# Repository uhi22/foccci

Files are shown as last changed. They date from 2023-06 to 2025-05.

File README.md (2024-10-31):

# foccci - The Fully Open CCS Charge Controller Interface

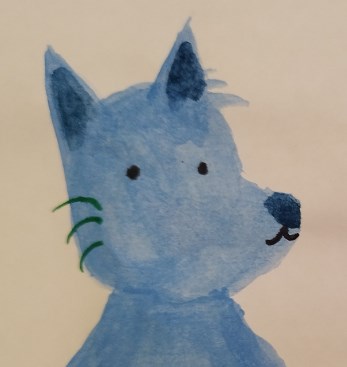
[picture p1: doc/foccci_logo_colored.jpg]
 Hi, I'm Foccci. Just call me [Foksi] or [Fok-See] or just Foxi :-)
My real name is "Fully Open CCS Charge Controller Interface", but that's just too difficult to remember.

What I am? I'm a Charge Controller that enables CCS charging of homebrew electric vehicles.
I was born in the OpenInverter forum community, https://openinverter.org/forum/viewtopic.php?t=3727, and I'm growing more and more due to the great people there.
Inside, I have a QCA7005 PLC modem and an STM32 microcontroller. I'm a piece of hardware, and because hardware alone is quite boring,
I'm in a team with Clara, https://github.com/uhi22/ccs32clara, which is dealing with the bits and bytes of our mission. And together, we can do a lot for you.

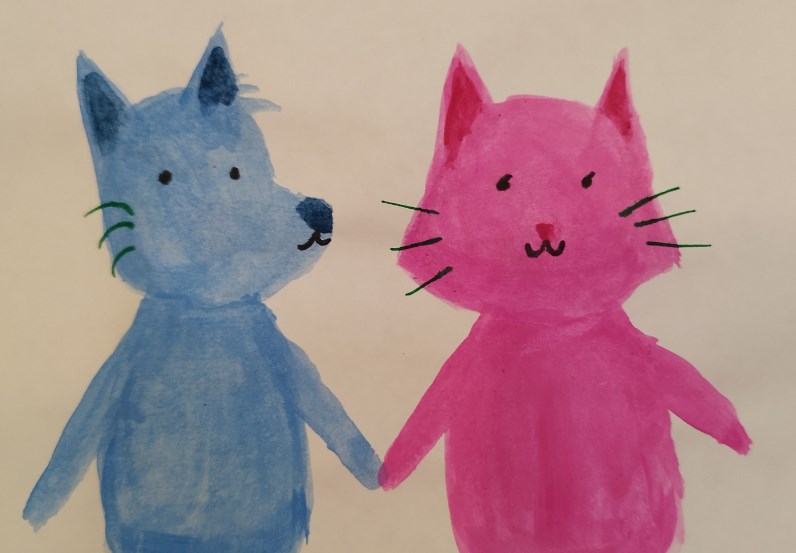
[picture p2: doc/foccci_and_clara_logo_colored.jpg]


# News

## 2024-06-27 Foccci Is Gaining Speed

While some folks are integrating Foccci in their vehicles and providing nice pictures for the galery (https://openinverter.org/forum/viewtopic.php?t=5077), we were proudly presenting the project at the
Augsburg Linux info day (https://openinverter.org/forum/viewtopic.php?t=4800). Sleep and wakeup,
new, fast contactor driver and a new connector pinout provide more flexibility for the car integration. That will
be the version 5, which will hopefully pop-up in the shop in July.

## 2023-12-13 Supercharging works. Halve a dozen boards are spread around the world. 

Johu is charging the Touran on the TESLA Supercharger using the hand-populated V3 board: https://openinverter.org/forum/viewtopic.php?p=64563#p64563 and https://www.youtube.com/watch?v=OKg3VUslol8
The first JLC populated boards have been completed manually, only one bug in the schematic needed a small workaround. Boards are on the way to several enthusiasts for further testing. The software is growing thanks to the great openinverter community.

## 2023-10-25 First Order of Populated Boards

Received four reservations on openinverter forum, and this was the trigger to create version v4.1 with minor layout
improvements, and to order a batch of five
at JLCPCB. Total cost for five: $127.32 including shipping, taxes and duties. The NCV8402 was out of stock,
and the QCA7005 is anyway not in their stock. So the material price is

- 25€ JLCPCB populated PCB
- 12€ QCA7005
- 4€ 2 x NCV8402
- 1€ RF transformator
- <1€ connectors for programming and serial line

## 2023-10-08 Light-Bulb-Demo-Charging on Alpitronic and ABB works

Using the foccci V3 board together with ccs32clara software, the muehlpower voltage sense board, a cheap chinese relay, the light-bulb-demo
worked on the first attempt on alpitronics hypercharger and on an ABB triple charger.

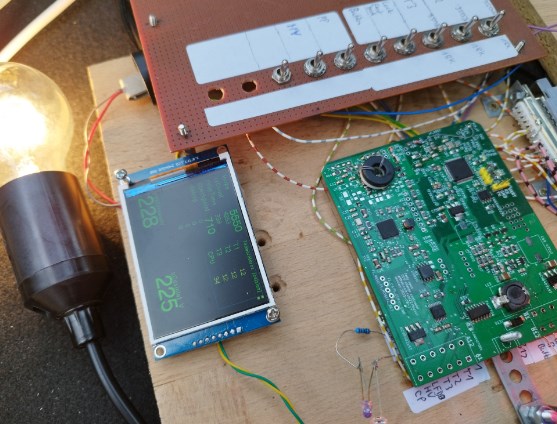
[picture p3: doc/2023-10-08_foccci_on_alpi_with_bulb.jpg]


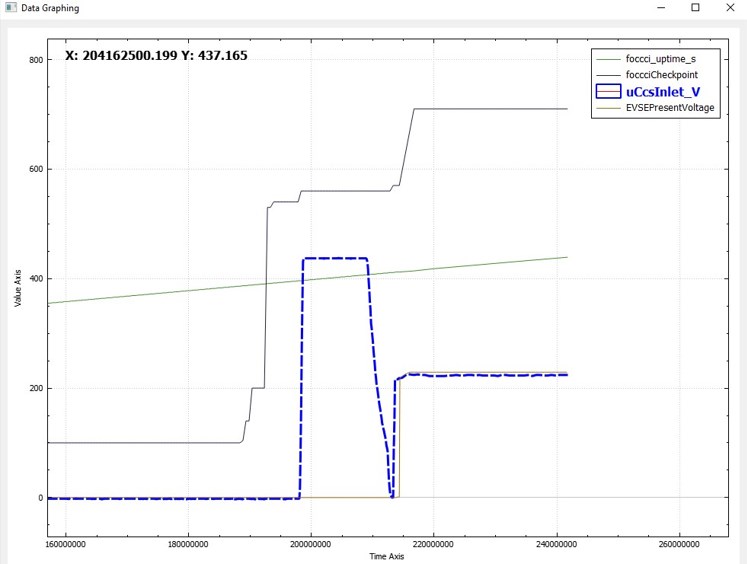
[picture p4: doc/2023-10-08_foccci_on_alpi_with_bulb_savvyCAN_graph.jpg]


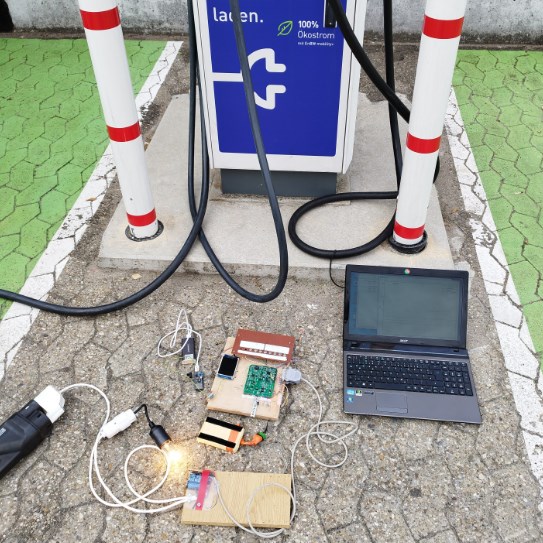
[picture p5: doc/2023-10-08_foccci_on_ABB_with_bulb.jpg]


## 2023-07-28 Charging Loop Reached

The foccci board version 2023-07-12 runs the STM32F103 and the QCA7005, and successfully enters
the charging loop, with simulated evse by pyPLC. It provides the checkpoint number and some other
informations via CAN with 500kBaud. On the other side of the CAN sits an ESP32 Wifi-Kit-32, with
a CAN transceiver added. It shows the data of the CAN on its OLED display.

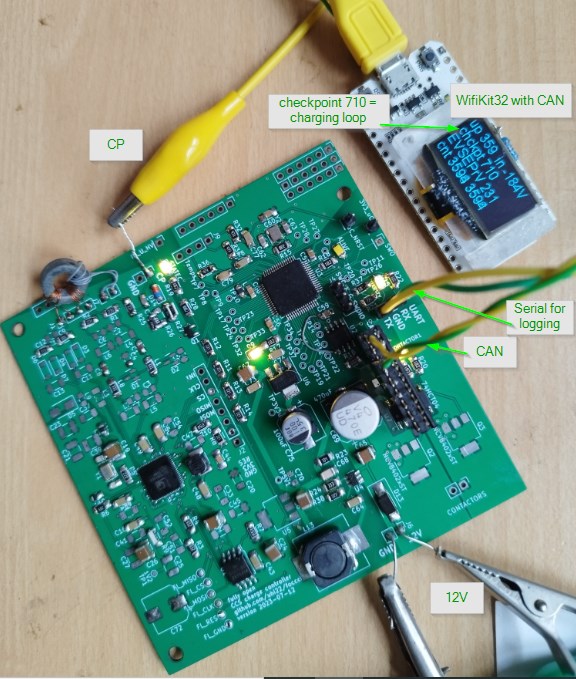
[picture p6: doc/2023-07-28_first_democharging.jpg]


## 2023-07-09 The board starts talking

After the PCBs and QCAs arrived, the soldering was the next challenge. It went well, and the board started talking to
the ESP32 running ccs32berta https://github.com/uhi22/ccs32berta

https://openinverter.org/forum/viewtopic.php?p=58627#p58627

## 2023-06-21 First PCB with the QCA7005

...is ready in KiCad and is sent to JLCPCB. It is a two-layer, and has so many capacitors, that they do not really fit
to the place where they would make sense. Caused by taking the schematic from the Millisman design, but changing
the size to 1206 for easy hand soldering. Btw: Below five dollars for five PCBs, including shipping, duties and taxes.

## 2023-06-14 The Idea Is Born

...and the discussion is starting on the OpenInverter forum
https://openinverter.org/forum/viewtopic.php?p=57643#p57643

# Board versions

## V1 June 2023

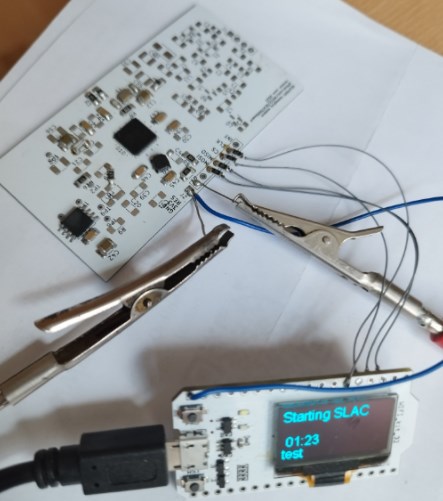
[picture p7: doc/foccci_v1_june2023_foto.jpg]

- Just the QCA7005, exposing the SPI interface.
- No controller, no voltage regulator, no CP logic.
- Test result summary: Light-bulb-demo-charging works on alpitronics, with ccs32berta running on ESP32. (https://github.com/uhi22/ccs32berta)

## V2 2023-07-12

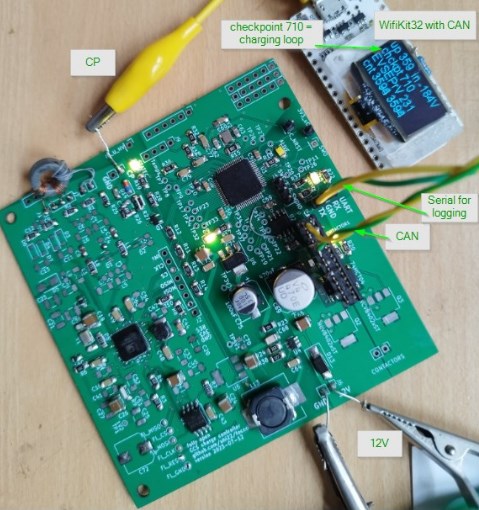
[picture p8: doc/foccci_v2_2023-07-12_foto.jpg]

- STM32 controller
- Power supply
- CAN transceiver
- CP logic
- Two contactor drivers
- Test result summary: Light-bulb-demo-charging works on alpitronics, with ccs32clara https://github.com/uhi22/ccs32clara running on the STM32.  https://openinverter.org/forum/viewtopic.php?p=59821#p59821

## V3 2023-08-17

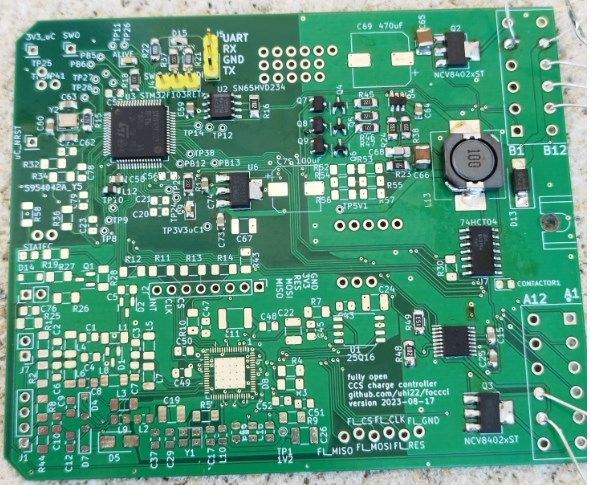
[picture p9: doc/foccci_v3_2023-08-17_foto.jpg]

- HBridge driver DRV8874 for connector lock
- discrete drivers for RGB LEDs
- Deutsch Connector 2x12pins
- added CP and PP sensing
- changed from 2 layers to 4 layers
- Test result summary: The new output drivers work with https://github.com/uhi22/ccs32clara. Other tests still in progress.
- Issues:
    - Diode to 3V3 is missing in the CP sense path (R58). Need to be patched.
    - There is a via near the pin1-corner of the QCA, which is very near to the metal frame at the corner, and may cause shortcut between 1V2 and ground.

## V4 2023-09-10

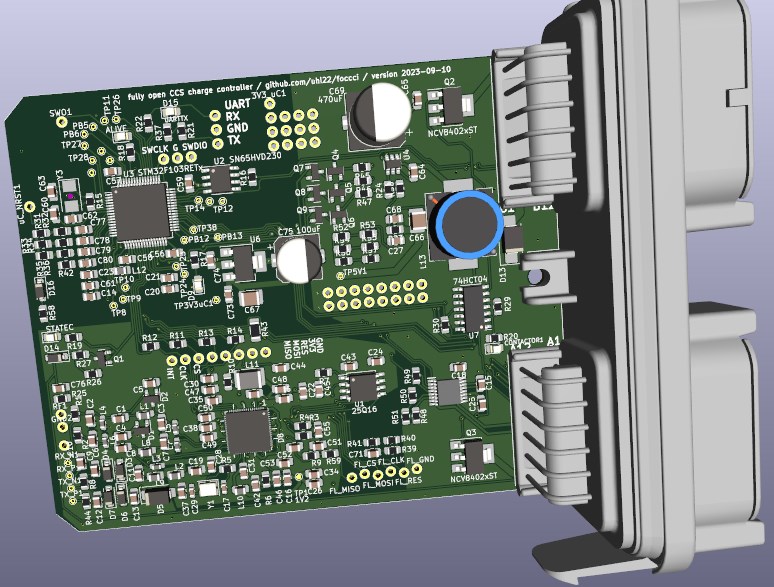
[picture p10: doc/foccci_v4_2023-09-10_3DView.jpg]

- Prepared for assembling by JLCPCB
- No 1206 size components anymore. Means: 0805 is the new default size now.
- Test result summary: PCBs not ordered yet. No testing done yet.
- Outdated, never produced.

## V4.1 2023-10-25

- functionally identical to V4
- moved via away from QCA corner to avoid solder bridge
- silk screen improvements: more component names and better readability
- Test result summary: one issue found (shortcut on the RX inputs to ground via inductors). After fixing this, everything works fine.

## V4.2 2024-02-06

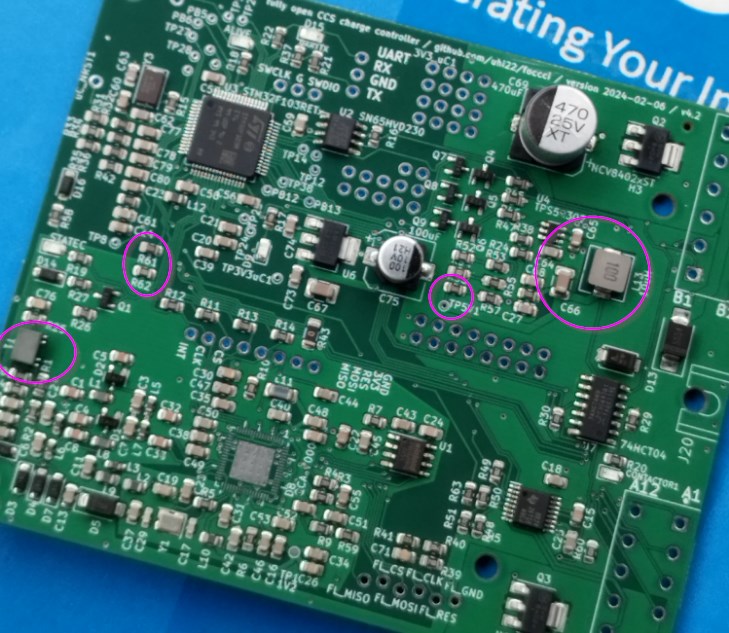
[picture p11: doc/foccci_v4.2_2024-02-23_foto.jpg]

- rx path grounding bug resolved
- added RF transformer
- proximity pilot input circuit corrected (330ohm pull-up to 5V instead of 1k to 3.3V)
- hardware variant coding with two resistors on analog port added
- routed the current measurement pin of the lock driver DRV8874 (IPROPI) to the ADC
- more copper cooling area for the contactor drivers
- more spare holes
- added openinverter logo - and lost it later when transferring the schematics update to the PCB - sorry
- added mounting holes
- layout optimizations, footprint and part number corrections
- Issues:
    - R56 (PP pull-up) has 33ohms instead of intended 330ohms. Wrong part number C17634.
    - missing track between D4 and D7
    - missing tracks on C39 (IPROPI)
    - missing track on R63 (IPROPI)
    - missing tracks on R28 (ADC_PP)
    - missing ground on R60 (PP_PULLDOWN)

These are the patches:
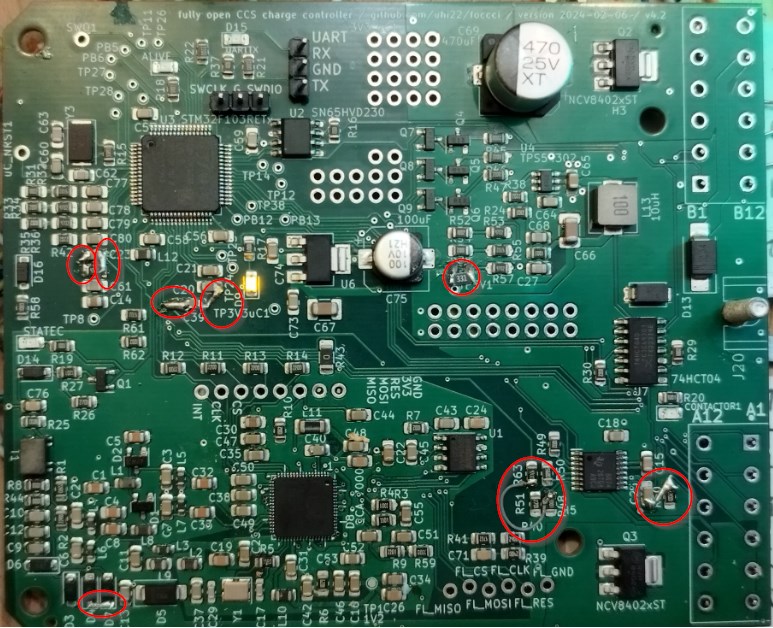
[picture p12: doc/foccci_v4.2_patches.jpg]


## V4.3

fixes the issues of the 4.2

## V4.5

- contactor driver is now the same, fast as the lock motor driver
- wakeup logic added

## V4.5b

First version with the changed connector pinout. Intermediate version, never produced.

## V5

Functionally identical with V4.5b. The first official version with the new connector pinout.
- layout fixes (missing connection D20, clearance violations, courtyard violations)
- QCA JTAG preparation
- Added openinverter and Foccci logos

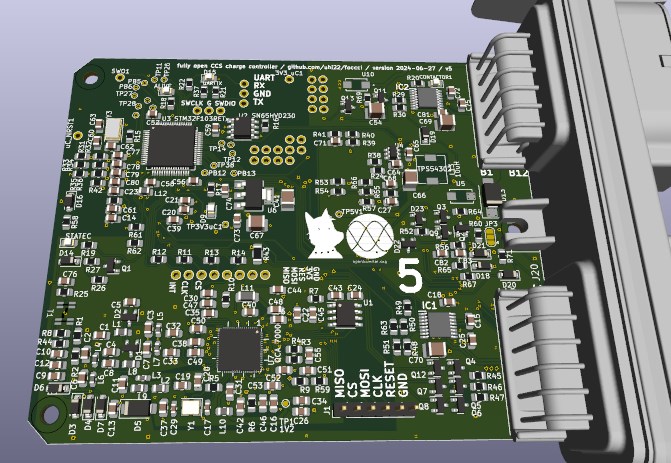
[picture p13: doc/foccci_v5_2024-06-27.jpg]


- Issues
    - enable pin of the step-down gets battery voltage, which leads to current draw
    - wrong resistor values R52 and R64 in the BOM

## V5.1

- added D8 at the enable pin of the step-down, to avoid unintended current flow
- removed spare capacitors on the crystal from schematic
- propagated the 1k values of R52 and R64 to the board
- fixed some rotations

## V5.2pre

- removed the RF transformer including symmetric parts of the RX and TX path
- added fast TVS for protection of RF path
- three mounting holes changed from 3.2mm to 3.5mm
- demo placement for alternative 2.54mm headers (not routed, lot of DRC violations!!!)

# Background

The QCA7005 schematic and board was originally designed by Millisman https://github.com/Millisman/QCA7000, then forked to https://github.com/uhi22/QCA7000board and then renamed to https://github.com/uhi22/foccci

# Changes to the original Millisman design

## Schematic
- removed JTAG completely
- removed connector for SPI flash, added testpoints instead

- ATP_P and ATP_N are reserved analog test points. Leave unconnected without testpoints.
- ZC_IN connected to ground. Not used.
- PLL_BYPASS has an internal pulldown. Removed the external pulldown.
- Removed the LEDs on the GPIO.
- RSVD06 and 07 are "do not connect". Removed the test points.
- Bugfix: The ground was missing between C13 and C14.

## symbol QCA7000:
 - RSVD01 changed to power_in, because connected to 3.3V
 - RSVD04 changed to power_in, because connected to 1.2V
 - TCK changed from output to input, because this is the test clock driven by debugger. Even if the data sheet says "output".
 
## Footprints in Schematic

- changed the 100nF to 1206 for easy handsoldering (and back to 0805 for some, to safe space)
- changed the 10µF to 1210
- changed other 0603 Cs to 0805
- changed L and Rs to 1206 (and the beads back to 0805)

## Todos for now

[ ] Footprint for L13 leads to complains of JLC, see https://openinverter.org/forum/viewtopic.php?p=72630#p72630

## Todos for Later

- [ ] add optional "Molex Mini-Fit Jr. Header, Dual Row" for the case, that the Deutsch is not needed in certain use cases.
- [ ] Docu: add details of step-by-step bring-up, incl current consumption, and typical errors
- [ ] more temperature inputs (6, to support L1, L2, L3, N, DC+ and DC-)
- [ ] The use of the LEDs on GPIO0 to 3 is not clear. Are they used in the automotive firmware at all? GPIO3: on the CCM, this is connected to µC.43 via R8 (0 ohms). Measure the pin.
- [ ] Regarding AMS1117-3.3 for the 3v3 regulators. These are tried and tested, but you may wish to avoid the polarized capacitor by using a more modern regulator. Consider TLV75733PDBV "Stable With a 1-μF Ceramic Output Capacitor"
- [ ] The STM32F103 seems to meet the requirements and it's popular but be aware that it has a basic ARM core with no FPU. And: Do we need a low-power variant (stm32L4 series)?
- [ ] The QCA7005 is labelled QCA7000.
- [ ] missing the JTAG port pull down resistors on the QCA
- [ ] Could do with one more processor decoupler so that a cap can be dropped right against every package power pin.
- [ ] Would be worth adding lines to the QCA7005 Reset (so that is can be reset without a power cycle) and the Int pins (just in case it's needed in the future).
- [ ] Might put a Schottky protection diode on the temperate sense inputs.
- [ ] supply voltage measurement (to be able to adjust the PWM for contactors according to the supply voltage, and just for info)

## Finished Todos
- [x] TVS at the CP
- [x] Transformerless RF path
- [x] do not inject >7V into the enable pin of the step-down
- [x] Low-power concept
- [x] Clarify interface (electrically and mechanically)
- [x] more copper cooling area for the NCVs
- [x] analog current feedback from the DRV8874 IPROPI to the controller
- [x] Add a version indication analog circuit. Discussed here: https://openinverter.org/forum/viewtopic.php?p=66745#p66745
- [x] Change the PP pull-up to 330 ohms and 5V, and optionally prepare pull-down 2k7. Use voltage divider to the controller, to be able to measure the full 0 to 5V range. Discussion here: https://openinverter.org/forum/viewtopic.php?p=66208#p66208

- [x] For C69, how to workaround the forced switch from "economy" to "standard" service? Workaround: use C3445244, discussed here: https://openinverter.org/forum/viewtopic.php?p=65016#p65016
- [x] Remove DC-grounding of the RX inputs. Done: C32 and C33 added on the RX inputs.
- [x] Transformer (discussion here: https://openinverter.org/forum/viewtopic.php?p=64465#p64465) see https://jlcpcb.com/partdetail/3170710-CL4532A201/C2904734 Done: Added into new lib transformerCL4532A-201 and to schematic and pcb.
- [x] Adapt the part number for the NCV8402 (discussed here: https://openinverter.org/forum/viewtopic.php?p=62903#p62903). Done: Part number C77755 instead of C236053
- [x] Adapt the footprints / part numbers for the parts which JLC could not populate
    - [x] U1 Flash: Old: Package_SO:SOP-8_5.28x5.23mm_P1.27mm, must be SOIC 150mil (order code SN), which is Package_SO:SOIC-8_3.9x4.9mm_P1.27mm.
    - [x] L11: The https://jlcpcb.com/partdetail/C162588 is normal 1206. Changed from Inductor_SMD:L_1812_4532Metric_Pad1.30x3.40mm_HandSolder to Inductor_SMD:L_1206_3216Metric_Pad1.22x1.90mm_HandSolder
- [x] Add additional mounting holes
- [x] Stepdown layout optimization (discussed here: https://openinverter.org/forum/viewtopic.php?p=61697#p61697), including smaller L, e.g. https://jlcpcb.com/partdetail/LantuMicro-SMS1050100MT/C5127462 instead of C3000379. And, next step, even smaller
https://jlcpcb.com/partdetail/Sunlord-MWSA0503S100MT/C408412 is 5.1 x 5.4mm.
- [x] TVS at the 12V. SMAJ18A
- [x] move as much as possible bottom layer components to upper layer, to allow population by JLBPCB
- [x] adapt layout for changed footprints
- [x] check/remove/correct the JLCPCB part numbers for all parts. Most parts now 0805.
- [x] add protection diode for CP sense
- [x] CP sensing
- [x] 5V on the connector for supply of the muehlpower high voltage sense board
- [x] Clarify expected contactor current and use appropriate drivers
- [x] Footprints for the bigger capacitors too small. -> Use 1210 for C65, C66, C67, 
- [x] Many texts in the silk screen are not readable due to overlap with solder or components
- [x] Some of the many capacitors on the supply lines could be removed
- [x] Use 0805 for all 100nF, instead of mixing 0805 and 1206.
- [x] The EN pin of the CAN transceiver should have the flexibility to solder-bridge to GND and 3V3, to allow different type of transceivers.
- [x] Change footprint of the test points for flash programming, so that squared connector pins fit into.
- [x] highside LED drivers for RGB button
- [x] VDDA of the STM32 needs additional 1µF according to STM application note AN2834. https://www.st.com/resource/en/application_note/an2834-how-to-get-the-best-adc-accuracy-in-stm32-microcontrollers-stmicroelectronics.pdf chapter 4.2.1 -> C14 added.
- [x] add port locking driver
- [x] Complete the schematic and the layout for the DRV8874 h-bridge driver
- [x] add PP detection
- [x] change to 4 layers
- [x] One of your AMS1117 seems to have a 100nF output cap and the other doesn't.
- [x] 470u input cap is an electrolytic? Yes.
- [x] Which connector? DTM13-12PA-12PB-R008 https://openinverter.org/forum/viewtopic.php?p=58697#p58697
- [x] HCT04: Risk of activating the contactors if the controller power fails. Find a better solution.
- [x] Check boot config on GPIO 0 to 2.
    - [x] GPIO0: High during boot to boot from the SPI Flash. (pin60) CCM: R9 is 3k3 to 3V3.
    - [x] GPIO1: must be pulled low during reset. (pin61) CCM: R11 is 3k3 to ground.
    - [x] GPIO2: 0=legacy SPI, 1=burst SPI. Which is used in the CCM? (pin62) CCM: R10 is 3k3 to 3V3, and the not-populated R27 into direction of µC.
        - [x] connect the GPIO2 with pullup to 3V3
- [x] add LEDs for functional check
- [x] add mounting holes
- [x] correct voltage divider in the TPS54302
- [x] 3V3_uC and NRST on connectors for debugger
- [x] removed the wrong part number and datasheet for the 8MHz XTAL
- [x] larger footprint for L10: From 1206 to 1812
- [x] check all pins -> all plausible with the data sheet.
- [x] check the QCA footprint -> fits.
- [x] assign footprint to all components in the schematic
- [x] add CP logic
- [x] add microcontroller
- [x] add power supply
- [x] add contactor driver outputs
- [x] add port temperature sensor inputs
- [x] Takeover from CCM:
   - [x] RBIAS (pin 51, R9). In the CCM this is R19 with 2,5k. Used 3k || 15k, this is exactly 2k5.
   - [x] BIAS_REF (pin 40, R6). In the CCM this is R23 with 6,2k. -> Changed from 2k5 to 6k2 in the schematic. Populated 6k8.
- [x] What's going on with the missing processor Gnd pins, are they mapped within the part? Yes, in the layout they are correct.
- [x] Add LIM-like current input for HVDC voltage measuring, https://openinverter.org/forum/viewtopic.php?p=58839#p58839

# Interface

...is described in the wiki: https://openinverter.org/wiki/Foccci

# Connector and Housing

Ideas: https://openinverter.org/forum/viewtopic.php?p=59972#p59972

Plan:
- use the DTM13-12PA-12PB-R008 - 2 x 12 pins
- data sheet: https://www.te.com/usa-en/product-DTM1312PA12PBR008.html (mentioned here: https://openinverter.org/forum/viewtopic.php?p=60064#p60064)
- Enclosure: https://www.te.com/usa-en/product-EEC-325X4B.html

# Power supply options

## The OpenInverter VCU supply
From openinverter VCU (https://github.com/jsphuebner/stm32-vcu/blob/master/Hardware/GS450H_VCU_V3%20-%20Schematic.pdf)
- MP2359DJ as step down from (6V to 24V) to 5V.
    - datasheet https://www.monolithicpower.com/en/documentview/productdocument/index/version/2/document_type/Datasheet/lang/en/sku/MP2359/document_id/228
    - cheap (5 parts 6 euros on ebay from China)
    - "not recommended for new designs"
    - 1.2MHz fix frequency
    - output 1.2A
- Inductance 4.7µH
    - https://www.ebay.de/itm/334756668131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

- Diodes for reverse polarity and step down: Schottky SS54B-HF, 40V, 5A.
    - https://www.mouser.de/datasheet/2/80/20190806170503-2505092.pdf
    
- ams1117-3.3V linear from 5V to 3.3V
    - output 1A
    - cheap (10 parts 4 euros on ebay)
    - datasheet https://datasheet.lcsc.com/szlcsc/2001081204_Shikues-AMS1117-1-2_C475600.pdf
Conclusion: Seems ok for feeding the QCA7005 and ESP32 plus other small consumers.

## The zombieverter supply
From https://github.com/jsphuebner/stm32-vcu/blob/master/Hardware/Zombie/ZombieVerter_V1%20-%20Schematic.pdf
- XL1509-5.0 as step down from (6V to 40V) to 5V
    - https://datasheet.lcsc.com/lcsc/1809050422_XLSEMI-XL1509-5-0E1_C61063.pdf
    - 2A constant output
    - 150kHz fix frequency
    - recommended L: 68uH/2A
    - cheap (10 parts 9 euro on ebay from China)
- Inductance 68uH:
    - e.g. SMD 12x12x7mm
    - e.g. https://de.aliexpress.com/item/4000079812764.html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,scm-url:1007.40050.281175.0,pvid:03c46a0a-7aed-47f8-b4c4-6e97bc2d985f,tpp_buckets:668%232846%238114%231999&isseo=y&pdp_npi=3%40dis%21EUR%211.84%211.84%21%21%21%21%21%40211b613116886252208597357e08be%2110000000209047381%21rec%21DE%21

## The Catphish supply
From https://openinverter.org/forum/viewtopic.php?p=58555#p58555
- TPS54302 as step down from (6V to 28V) to 5V
    - voltage is flexible by resistor divider
    - output 3A
    - 400kHz fix frequency
    - SOT-23 (6) package
    - no external diode on the output required
    - https://www.ti.com/lit/gpn/tps54302 
- L 10uH, JLC C408412
- TLV75733PDBV linear from 5V to 3V3
    - 1A
    - SOT-23 5pin
    - https://www.ti.com/lit/ds/symlink/tlv757p.pdf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

# CAN Transceiver
- SN65HVD234
    - https://www.ti.com/lit/ds/symlink/sn65hvd230.pdf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

# Requirements
- [ ] 8V to 30V power supply
- [ ] PLC communication
- [ ] CAN communication
- [ ] CP level handling (and -detection?)
- [ ] PP detection
- [ ] 12V highside LED drivers (for RGB LEDs as in BMW LIM)
- [ ] Contactor driver (with PWM?) for two contactors
- [ ] Charge port temperature sensing (2 channels, either NTC or PT1000)
- [ ] Connector lock motor bridge and connector lock feedback
- Optional:
    - [ ] Analog input for HV voltage sensor at the charging port
    - [ ] fuel flap switch
    - [ ] button to start/stop the charging process
    - [ ] HV contactor feedback
    
# Requirements for the low-power-mode

- The foccci shall fall in low-power-mode, if not needed. The consumption shall be less than 5mA during this mode.
- The foccci shall use the enable pin of the step down converter TPS54302 to shut down the power supply.
- The following ways shall be used to activate the high-power-mode:
    - CP line: A significant voltage (above 4V) for a significant time (at least some milliseconds).
    - Button: A button to ground, internally pulled-up to 12V, if pressed long enough (at least some milliseconds).
    - microcontroller: The STM32 shall be able to keep itself powered by using a toggle pin. In case of stuck to high or low, the foccci shall power-down.
    - Not planned at the moment: Wakeup via CAN communication. This would be a helpful use case, if the user wakes the car via remote key (unlock), and the connector is unlocked by this activity.

# Controller

STM32 selection:

Overview: http://stefanfrings.de/stm32/stm32f1.html

https://www.st.com/en/microcontrollers-microprocessors/stm32f103.html
- STM32F103C8T6 ("blue pill") 64kB Flash and 20kB RAM too small. -> FAIL
- STM32F401CC ("black pill") 256kB Flash and 64k RAM. No CAN -> FAIL
    - https://www.st.com/en/microcontrollers-microprocessors/stm32f401cc.html
- STM32F103RC 256k Flash, 48k RAM, CAN 
- STM32F103RD 384k Flash, 64k RAM, CAN (10 pieces 22 euro on Aliexpress)
- STM32F103RE 512k Flash, 64k RAM, CAN (10 pieces 24 euro on Aliexpress)
- STM32F303RE (Nucleo demo board available) (STM32F303RET6) 512K Flash, 80k RAM, LQFP-64, 1 CAN. (6 euro on Aliexpress)

Programming:
- en.st-stm32cubeide_1.12.1_16088_20230420_1057_x86_64.exe

# First run of the June 2023 version

- Starting with power suppy connected to the 3V3, but set to 0V. Slowly increase the voltage to 0.5V. Observe the current. No current is good.
- Measure, whether the DVDD pins of the QCA and 3 pins of the Flash have 0.5V.
- Connect multimeter to 1V2, and turn the power supply slowly up.
- With 2V, the board draws 4.5mA.
- At 2.7V, the current jumps from 6mA to 13mA. This is when the 1.2V regulator starts delivering its intended output voltage.
- At 3.3V, the current is 20mA. This does not look like normal operating current.
- On the L10 input, there is a 0V/3.3V quare wave with 600ns cycle time. This looks normal for the step-down-converter.
- On the R6 (both sides), there is the 25MHz clock, with ~1V amplitude.
- The Reset line is 3.3V (no reset). When pulling it to ground, the current consumption increases from 20.8mA to 23mA.
- The CS of the Flash is permanent high. This means, the QCA does not want to load its programm code from the Flash. Something is wrong.
- The RBIAS and R_BIASREF were not populated. Added them.
- Looks better: At 3V3, the current is 80mA. At the CS of the Flash there is activity for one second after power-on. Seems the QCA is fetching its program code.
- Connect the ESP32 with the ccs32berta via SPI, using 220 ohm protection resistors in all four SPI lines. ESP powered via USB, QCA powered from 3.3V bench power supply. Result: The Berta finds the modem and starts the SLAC.

# Programming the SPI Flash

An introduction how to use a Raspberry to program the SPI flash is here:
https://www.rototron.info/recover-bricked-bios-using-flashrom-on-a-raspberry-pi/
The connection is quite simple: SPI_FLASH_programming_with_Raspberry.jpg

Make sure that SPI is enabled in the settings of the Raspberry.
Install the flashrom tool: `sudo apt-get install flashrom`
The docu of flashrom is here: https://www.flashrom.org/Flashrom

Check whether the device is detected: `flashrom -p linux_spi:dev=/dev/spidev0.0,spispeed=2000 -V`

Binary is available here: https://github.com/uhi22/Ioniq28Investigations/blob/main/CCM_ChargeControlModule_PLC_CCS/CCM_FlashDump_SpiFlash_2MB_Ioniq_00_33_79.bin

For viewing the binary, a hex editor can be used, e.g. http://www.funduc.com/fshexedit.htm

To flash the binary file to the SPI flash: `flashrom -p linux_spi:dev=/dev/spidev0.0,spispeed=2000 -w myfile.bin` In the case that to tool complains that multiple flash chip definitions match the detected chip, choose the correct one with the option `-c "MX25L...something...`

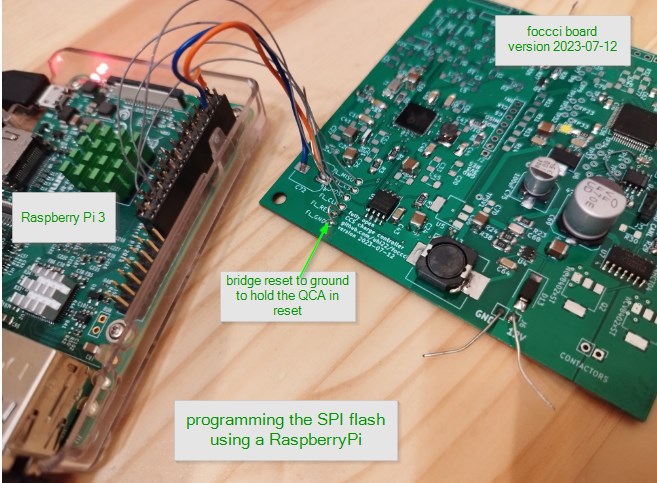
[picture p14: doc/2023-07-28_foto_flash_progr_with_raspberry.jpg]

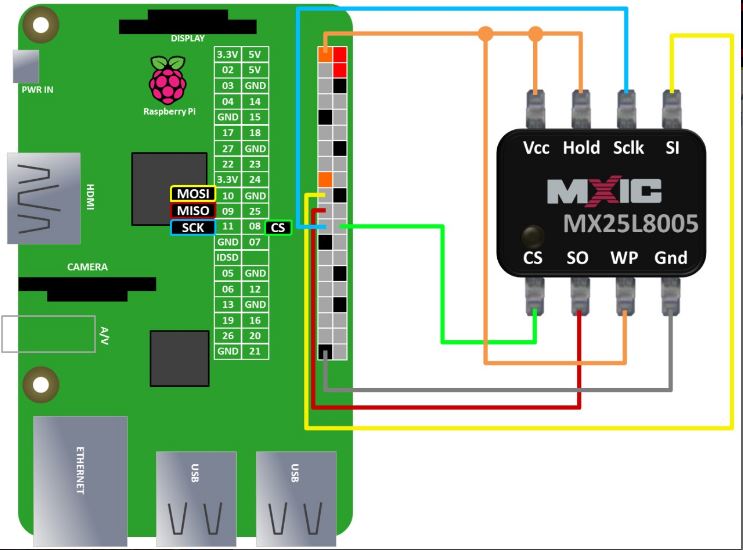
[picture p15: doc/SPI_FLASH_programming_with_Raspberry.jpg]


# Create Fabrication Output for JLCPCB

Starting with KiCad7, the The xsltproc appears to have been removed. So the procedure to create the BOM needs to be adjusted.
In https://gist.github.com/arturo182/a8c4a4b96907cfccf616a1edb59d0389 we find, that there is a plugin now: "Fabrication Toolkit".
This can be installed with the "Plugin and Content Manager" in the KiCad main window.
Then, in the PCB editor, use the FabricationToolkit from the toolbar. This creates a new folder in <project>/production/, which
contains a zip with Gerber and drill files, and also the BOM, positions and designator files.

The docu of the Fabrication Toolkit is here: https://github.com/bennymeg/JLC-Plugin-for-KiCad

Some of the IC footprints have the wrong orientation in the JLCPCB viewer. The Fabrication toolkit offers the possibility to
rotate (and shift, if necessary) the footprints, by adding in the schematic an attribute 'JLCPCB Rotation Offset'.
Thanks to jrbe for the hint in https://openinverter.org/forum/viewtopic.php?p=61049#p61049

# JLCPCB offers

Offer 2023-08-27: 5 PCBs, 2 populated.
- Option A: All available components: $82, which includes Extended components fee: $45.30
- Option B: Only basic components. $21. Plus shipping and duties, = $38.

Offer 2023-08-28: 5 PCBs, 5 populated.
- Total $107 for 5 populated PCBs, plus shipping ($13) and duties and taxes ($23). Plus QCA, connector, inductor, transformator, housing.
- Includes $42 extended components fee.

# Soldering Lessons

[solder_lessons.md](doc/solder_lessons.md)

# Trouble Shooting / FAQ

## How to trouble shoot Foccci/Clara?

For trouble shooting it is recommended to create a log file of the serial output. You need a serial-to-usb converter and connect it to the UART TX line and ground. For recording, you can use e.g. Putty on windows or any console program. The baud rate is 921600. Not each cheap USB-to-serial is able to catch this high speed. So if you get only garbage, try an other adaptor.

Additionally, use the openinverter web interface to observe spot values. As default, the Node ID of Foccci/Clara is 22.

## No communication with the charger possible

Check the following points (discussed here: https://openinverter.org/forum/viewtopic.php?p=64449#p64449 )
1. Is the 1.2V present and stable?
2. Does the STM detect the modem? Means: Does it show the QCAs software version?
3. Does the QCA go to sleep 30s after power-on? This is when the STM says "zero modems found".
4. Does the QCA stay awake longer than 30s when a central coordinator is present. If not, this means the QCA does not hear the central coordinator, so the RX path is deaf.
5. Are the RX and TX pins (4 in total) on the QCA at around 1.6V statically? If not, then check for short circuits.
6. Is the resistance between the RX pins around 500 ohms (measured when not powered)? If not, check for short circuits or bad soldered pads.
7. Is the resistance between the TX pins around 16kohms (measured when not powered)? If not, check for short circuits or bad soldered pads.
8. If evse (central coordinator) is connected, do you see packets on the RX pins? Using two osci channels, they should be invers on positive and negative RX pins.
9. In the web interface or in the serial log, check whether the spot value ControlPilotDuty shows 5% PWM on the control pilot.
10. In the web interface or in the serial log, check whether the resistance on the ProximityPilot pin is correctly detected. The spot value "ResistanceProxPilot" shall show 10000 ohms (means: infinite) while the charge plug is not connected, and it shall show around 1500 ohms if a CCS2 plug is connected. For CCS1 this should show 150 ohms if the button the plug is not pressed, and 480 ohms if the button on the plug is pressed. (Discussion here: https://openinverter.org/forum/viewtopic.php?p=70435#p70435)

## Clara shows software version "bootloader". Is tis normal?

No. Clara should report something like "[PEVSLAC] received GET_SW.CNF
For MAC 04:65:65:ff:ff:ff software version MAC-QCA7005-1.1.0.730-04-20140815-CS" 

If you see instead something like "[PEVSLAC] received GET_SW.CNF
For MAC 00:b0:52:00:00:01 software version BootLoader" then the QCA7005 was not able to load the firmware from the SPI flash U1. Some possible root causes are
* U1 is not populated
* U1 is not programmed with the software (see above "Programming of the SPI flash")
* U1 is wrong type.
* One of the SPI lines between the QCA and the SPI flash are not soldered correctly.

# Credits

Thanks to Millisman for the initial board design.

Thanks to Lars @evcreate for sponsoring the Ioniq charge control module.

Thanks to celeron55, mikeselectricstuff, Zieg, catphish, projectgus, chrskly, johu, Infant, muehlpower, crasbe, royhen99, asavage, Pete9008, P.S.Mangelsdorf, grgumxlm, royhen99, MeKe, mstegen, jrbe, Bigpie, xvyDFatih, olegiv, ns0708, f0ld, explorer232, dougyip, Gabriel, tom91, quentin42, maciek16c, apple2, CCSknowitall on the openinverter forum for the helpful discussions, proposals, reviews, tests and questions.

Special thanks to projectgus for organizing the chips.

Thanks to cookie_kater1 for the logos.

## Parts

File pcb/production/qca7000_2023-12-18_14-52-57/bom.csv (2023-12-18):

Designator | Footprint | Quantity | Value | LCSC Part #
3V3, 3V3_uC1, CLK1, CS1, GND1, INT1, MISO1, MOSI1, RES1, SWCLK1, SWDIO1, SWGND1, SWO1, UART_GND1, UART_RX1, UART_TX1, uC_NRST1 | TestPoint_Special_THTPad_D1.9mm_Drill1mm | 17 | ~
C1, C32, C33, C4, C5, C8 | 0805 | 6 | 1.5nF | C1717
C10, C2, C3, C6, C7 | 0805 | 5 | 220pF | C107145
C11, C12, C13, C16, C18, C20, C21, C23, C25, C28, C31, C34, C35, C37, C38, C40, C42, C43, C44, C45, C46, C47, C48, C49, C50, C51, C52, C53, C55, C56, C57, C58, C59, C60, C61, C64, C73, C74, C77, C78, C79, C80, C9 | 0805 | 43 | 100nF | C49678
C14 | 0805 | 1 | 1uF | C28323
C15 | 0805 | 1 | 22nF | C1729
C17, C29 | 0603 | 2 | 6.8pF | C1679
C17a1, C29a1 | 1206 | 2 | 6.8pF
C19, C22, C24, C26, C30, C36, C65 | 0805 | 7 | 10uF 25V | C15850
C27, C62, C63 | 0805 | 3 | 22pF | C1804
C66, C67 | 1210 | 2 | 22uF | C12891
C68 | 0805 | 1 | 47pF | C14857
C69 | CP_Elec_10x10 | 1 | 470uF | C4747956
C71, C76 | 0805 | 2 | 1nF | C46653
C75 | CP_Elec_8x10 | 1 | 100uF | C59937
D1, D2 | SOT-23 | 2 | BAV99 | C2500
D10 | 0805 | 1 | ALIVE | C2296
D11 | 0805 | 1 | STATEC | C2296
D12 | 0805 | 1 | CONTACTOR1 | C2296
D13 | D_SMB_Handsoldering | 1 | SS54B-HF | C3014033
D14, D16, D3, D4, D6, D7 | D_SOD-123 | 6 | B5819W | C8598
D15 | 0805 | 1 | UARTTX | C2296
D5 | D_SMA | 1 | 3V9 | C438352
D8 | QFN-68-1EP_8x8mm_P0.4mm_EP5.2x5.2mm_ThermalVias | 1 | QCA 7000
D9 | 0805 | 1 | PWR | C2296
H1, H2, H3, H4, H5 | MountingHole_3.2mm_M3 | 5 | MountingHole
IC1 | SOP65P640X120-17N | 1 | DRV8874QPWPRQ1 | C1855818
J20 | TE_DTM1312PA12PBR008 | 1 | DTM1312PA12PBR008
JP1 | SolderJumper-2_P1.3mm_Open_TrianglePad1.0x1.5mm | 1 | EN_LOW
JP2 | SolderJumper-2_P1.3mm_Open_TrianglePad1.0x1.5mm | 1 | EN_HIGH
L1, L8 | 0805 | 2 | 270nH | C281081
L10, L12, L2, L9 | 0805 | 4 | Bead 600 | C1017
L11 | 1206 | 1 | 4.7uH | C162588
L13 | L_12x12mm_H4.5mm | 1 | 10uH | C5127462
L3, L4, L5, L6, L7 | 0603 | 5 | 1.8uH | C78153
PB12, PB13, PB5, PB6, TP10, TP11, TP12, TP13, TP14, TP23, TP24, TP26, TP27, TP28, TP29, TP30, TP31, TP38, TP8, TP9 | TestPoint_THTPad_D1.0mm_Drill0.5mm | 20 | ~
Q1, Q7, Q8, Q9 | SOT-23 | 4 | DTC114E | C358500
Q2, Q3 | SOT-223 | 2 | NCV8402xST | C77755
Q4, Q5, Q6 | SOT-23 | 3 | DTA143Z | C2910150
R1, R2 | 0805 | 2 | 22 | C17561
R10, R29, R30, R31, R33, R35, R49, R52, R54, R7 | 0805 | 10 | 10k | C17414
R11, R12, R13, R14, R21, R22, R45, R46, R47 | 0805 | 9 | 220 | C17557
R15, R5 | 0805 | 2 | 33 | C17634
R16, R17, R18, R19, R20, R37, R48, R56 | 0805 | 8 | 1k | C17513
R23, R58 | 0805 | 2 | 100k | C149504
R24 | 0805 | 1 | 33k | C17633
R25 | 0805 | 1 | 180 | C25270
R26, R51 | 0805 | 2 | 2k7 | C17530
R27 | 0805 | 1 | 1k2 | C17379
R3, R4 | 0805 | 2 | 3.3K | C26010
R32, R34, R36, R41, R53, R55, R57 | 0805 | 7 | 47k | C17713
R38, R42 | 0805 | 2 | 22k | C17560
R39, R40 | 0805 | 2 | 240 | C17572
R43 | 1206 | 1 | 0 | C17888
R44, R8 | 0805 | 2 | 100 | C17408
R50 | 0805 | 1 | 560 | C28636
R59 | 0805 | 1 | 330 | C17630
R6 | 0805 | 1 | 6k2 | C17767
R9 | 0805 | 1 | 2.2k | C17520
T1 | transformerCL4532A-201 | 1 | ~ | C2904734
TP1 | TestPoint_Pad_D1.0mm | 1 | 1V2
TP15, TP25, TP32, TP33, TP34, TP35, TP36, TP37, TP41, TP42, TP43, TP44, TP45, TP46, TP47, TP48, TP49, TP50, TP51, TP52, TP53, TP54, TP55, TP56, TP57, TP58, TP59, TP6, TP60 | TestPoint_Special_THTPad_D1.9mm_Drill1mm | 29 | TestPoint
TP2 | TestPoint_Special_THTPad_D1.9mm_Drill1mm | 1 | FL_MOSI
TP3 | TestPoint_Special_THTPad_D1.9mm_Drill1mm | 1 | FL_CLK
TP39 | TestPoint_Special_THTPad_D1.9mm_Drill1mm | 1 | FL_GND
TP3V3uC1 | TestPoint_THTPad_D1.0mm_Drill0.5mm | 1 | TP3V3uC
TP4 | TestPoint_Special_THTPad_D1.9mm_Drill1mm | 1 | FL_CS
TP40 | TestPoint_Special_THTPad_D1.9mm_Drill1mm | 1 | FL_RES
TP5 | TestPoint_Special_THTPad_D1.9mm_Drill1mm | 1 | FL_MISO
TP5V1 | TestPoint_THTPad_D1.0mm_Drill0.5mm | 1 | TP5V
U1 | SOIC-8_3.9x4.9mm_P1.27mm | 1 | 25Q16 | C115407
U2 | SOIC-8_3.9x4.9mm_P1.27mm | 1 | SN65HVD230 | C12084
U3 | LQFP-64_10x10mm_P0.5mm | 1 | STM32F103RETx | C8322
U4 | SOT-23-6 | 1 | TPS54302 | C311983
U5 | SMA_UNI_STM | 1 | SMAJ18A-TR | C908771
U6 | SOT-223-3_TabPin2 | 1 | AMS1117-3.3 | C6186
U7 | SO-14_3.9x8.65mm_P1.27mm | 1 | 74HCT04 | C672096
U8 | TE_EEC-325X4B | 1 | EEC-325X4B
Y1 | Crystal_SMD_TXC_7M-4Pin_3.2x2.5mm | 1 | 25MHz | C9006
Y2 | Crystal_SMD_TXC_7M-4Pin_3.2x2.5mm | 1 | 8MHz | none
Y3 | Crystal_SMD_5032-2Pin_5.0x3.2mm | 1 | 8MHz | C115962

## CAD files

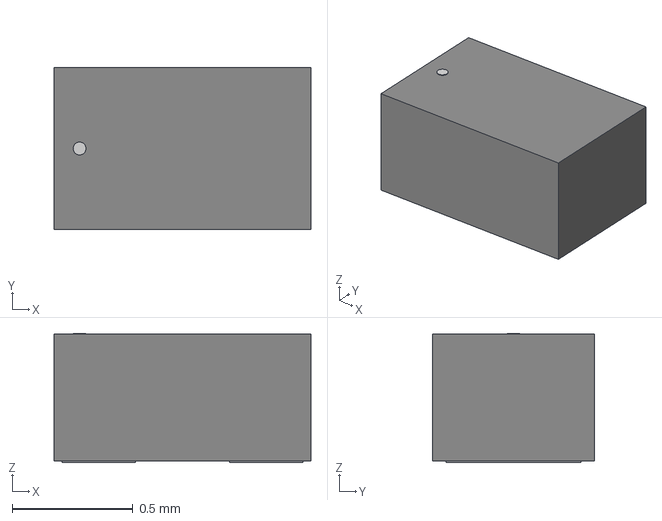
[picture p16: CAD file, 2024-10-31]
pcb/externLibs/DESD3V3S1BL_7B_TVS_10pF/X1-DFN1006-2_RH_DIO.step
1.07 x 0.674 x 0.536 mm

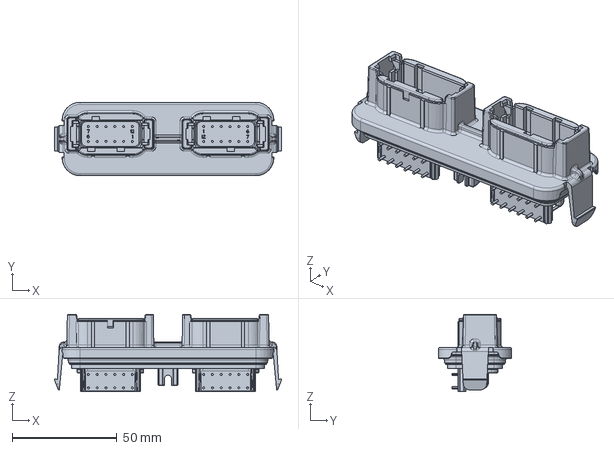
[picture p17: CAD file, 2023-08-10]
pcb/externLibs/DTM1312PA12PBR008/DTM1312PA12PBR008.step
108.3 x 35.0 x 36.9 mm

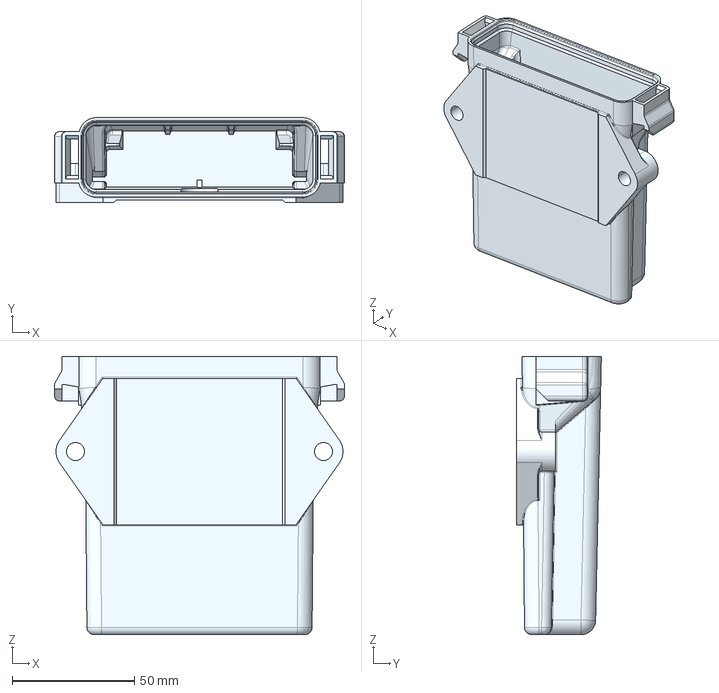
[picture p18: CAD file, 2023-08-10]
pcb/externLibs/EEC-325X4B/EEC-325X4B.step
118.8 x 34.7 x 114.0 mm

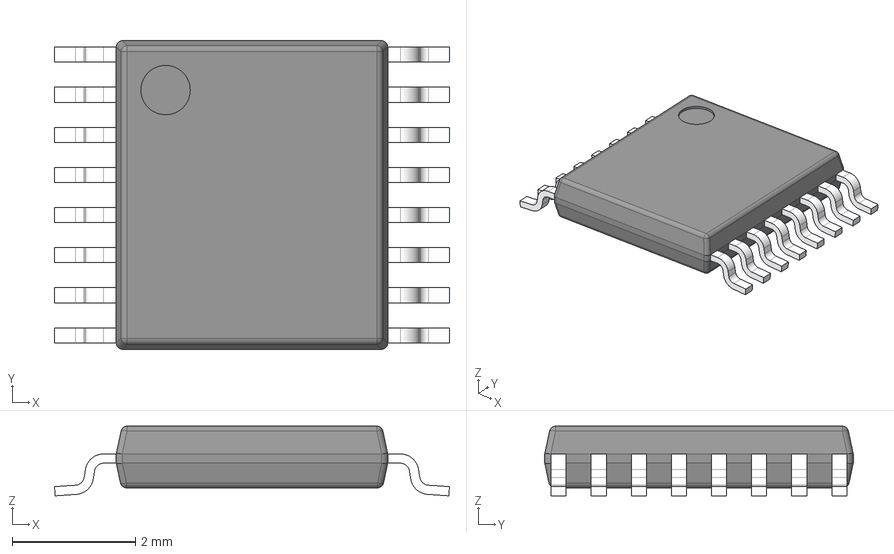
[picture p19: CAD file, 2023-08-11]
pcb/externLibs/LIB_DRV8874QPWPRQ1/DRV8874QPWPRQ1/3D/DRV8874QPWPRQ1.stp
6.40 x 5.00 x 1.13 mm
BODY-TSSOP
LEAD-TSSOP x 16
PIN1
DAP

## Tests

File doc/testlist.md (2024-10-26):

# Pre-Delivery Tests

## Preparation

[ ] 1. Solder bridge JP3 connects 1 to 2, to enable PP wakeup
[ ] 2. visual inpection

## Voltage Tests

### Supply voltage ramp, while button is pressed
[ ] 3. While wakeup input is at supply, increase supply voltage. Controller starts at ~5V supply. Alive LED flashes.
[ ] 4. current decreases while voltage is increased to 18V

### Static voltages
[ ] 5. 5V
[ ] 6. 3.3V
[ ] 7. 1.2V
[ ] 8. 1.6V at all 4 RF pins

## Functional Tests

[ ] 9. Sleep in case of power-up
[ ] 10. wakeup by button, sleep after ~10s
[ ] 11. wakeup by CP, sleep after ~10s
[ ] 12. wakeup by PP 1k5, sleep after ~10s
[ ] 13. wakeup by wakeline=12V, sleep after ~10s
[ ] 14. wakeline stays at 12V while CP PWM is present

### Demo Charging Session

DemoVoltage 220V, DemoControl=Standalone

[ ] 15. LED green blinking
[ ] 16. LED blue blinking
[ ] 17. State C on the EVSE detected
[ ] 18. Connector lock motor controlled
[ ] 19. Contactors activated, one after the other
[ ] 20. Charging loop reached
[ ] 21. Stop button terminates the session
[ ] 22. Connector unlock
[ ] 23. Red LED if the session is aborted by unpowering the EVSE and PP still 1k5
[ ] 24. Red LED flashing if the EVSE applies a 25% PWM. Not red, but blue with newer Clara.

### Web interface

NodeId=22

[ ] 25. Temp1, Temp2, Temp3 react (~33°C with 6k8 resistor)
[ ] 26. Inlet voltage reacts (with Parameter InletVtgSrc=AnalogInput)
[ ] 27. AdcLockFeedback reacts
[ ] 28. ResistanceProxPilot ~1500ohms and infinite
[ ] 29. ControlPilotDuty shows correct values 5% and 25%
[ ] 30. Serial log shows data

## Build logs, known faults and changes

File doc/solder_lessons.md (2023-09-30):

# Solder lessons

This is an (incomplete) collection of lessions regarding soldering the QFN package.

## Hand soldering QFN?

Yes, this works. What do we need?

- Solder tin, standard, Sn60PbCu2
- Solder iron, fine tip and thick tip
- Solder flux (e.g. KELLY SHUN KE-500, from https://de.aliexpress.com/item/1005004009158994.html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 )
- Hot air station, e.g. AOYUE Int 852, e.g. from https://www.ebay.de/itm/163304333026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

- A kitchen stove with ceramic hob, or something similar
- An infrared thermometer
- A magnifying glass, for example 4 diopters
- In best case a cheap (USB) microscope, e.g. https://www.ebay.de/itm/295649324815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
- Isopropanol and a small, hard brush for cleaning
- Solder wick

## Tested workflow

Still untinned:

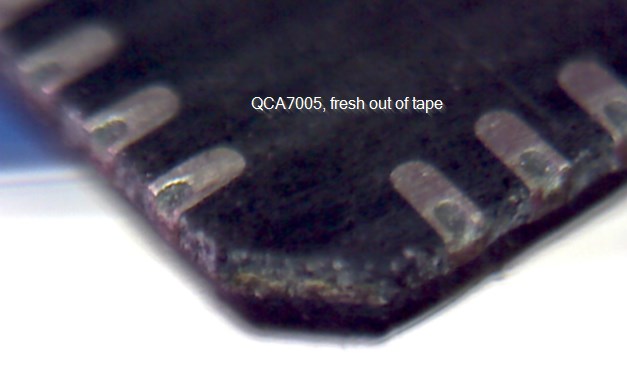
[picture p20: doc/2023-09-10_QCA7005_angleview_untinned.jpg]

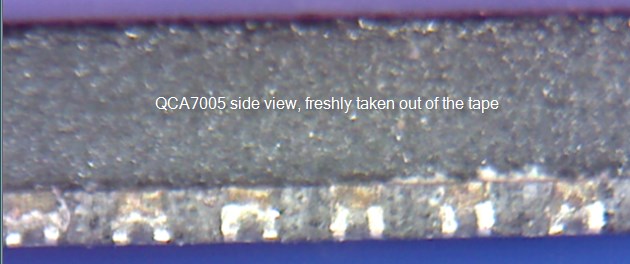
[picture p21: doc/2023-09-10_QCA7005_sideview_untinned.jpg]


1. Pre-tin the pins of the QFN package. They may have some oxidation, so you need an amount of flux, a hot iron and patience. Do not hurry, make sure that each pin has got tin, on the underside and also on the edge.
2. Pre-tin the center pad, and remove the tin on the center pad using solder wick.
3. Clean the package with isopropanol and brush.
4. Inspect the QFN carefully. All pins should have a certain amount of tin, with a smooth surface and no holes. If this is not yet reached, go back to step 1. The temperature of the iron should be hot, to have an effective reaction of the flux, but not as hot that the flux turns its color to brown or black.

Tinned (left side) and untinned (right side) pins
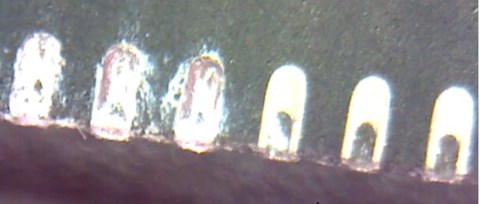
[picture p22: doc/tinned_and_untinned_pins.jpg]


5. Pre-tin the PCB. Use flux and a big drop of tin, and walk over the pads. Since the pads are a "level below" the surface of the solder mask, it may happen, that the tin does not reach the pad. Make sure to reach each pad, by using a pointed iron and move its tip on each pad. This job is easier, if the PCB is pre-heated.
6. Pre-tin the center pad on the PCB. For this you need a thicker iron, because the heat will flow away through the copper layers.
7. Remove the tin on the center pad using solder wick.
8. Clean the PCB with isopropanol and brush 
9. Inspect the PCB. Each pad should have the same amount of tin. The center pad should be completely flat. If any anomalies are present, go back to step 5.
10. Put a _small_ single drop of tin to the center pad on the PCB. The less the better. Too much tin on the center pad will produce contact problems on the pins, because the QFN will float on the center. Too less tin on the center pad contains the risk of no contact of the center pad.
11. Add fresh flux on the PCB.
12. Place the QFN on the PCB. The exact placement does not matter yet. Make sure the orientation is correct.
13. Put the PCB on the stove. Shortly turn on the stove, and observe the PCB temperature with the infrared thermometer. Goal is 100°C to 120°C. If there is smoke, then it is definitely too hot. Remove the PCB, let everything cool down. It is fine that this pre-heating takes 2 or 5 minutes.
14. Observe that the flux becomes liquid and the QFN floats in it.
15. Use the hot air to further increase the temperature. The flux is gasing, the QFN may jump a little bit around due to this. Then it lies on the pads. Check that each edge sits correctly. The rough positioning needs to be done manually. The fine positioning will be done by the tin itself, the device is drawn into the correct position automatically.
16. Remove the PCB from the stove and let it cool down.
17. Clean with isopropanol and brush.
18. Inspect the work carefully.

Typical faults:

Pins not aligned to the pads

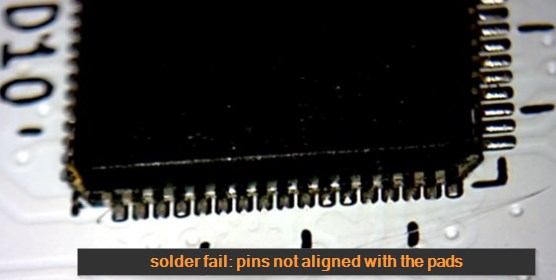
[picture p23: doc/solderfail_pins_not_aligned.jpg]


Bridges

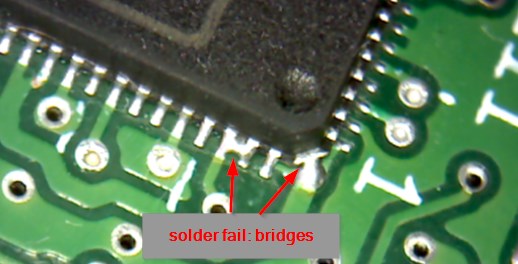
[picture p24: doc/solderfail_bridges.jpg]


Unconnected pins

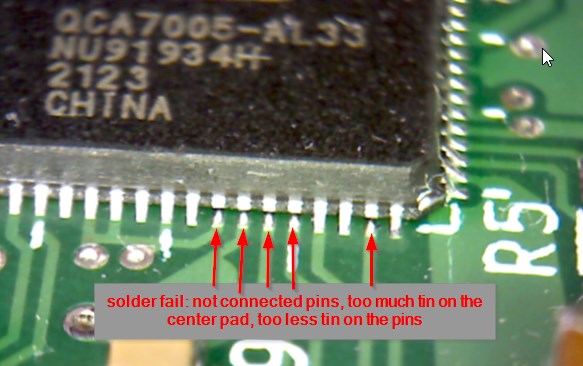
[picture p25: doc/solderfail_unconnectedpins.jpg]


In case of unconnected pins due to too less tin, it is possible to add tin afterwards.

19. Pre-heat the PCB as above.
20. Use the solder iron, flux and tin to reach every joint. Better use too much tin, it is okay to create shortcuts in this step. The goal is to have on each joint the necessary temperature and the sufficient amount of tin, so that the tin makes a reliable connection.
21. Use flux and solder wick to remove tin where it is too much.
22. Optionally use flux and hot air to re-melt all connections
23. Remove the PCB from the stove and let it cool down.
24. Clean with isopropanol and brush.
25. Inspect the work carefully.
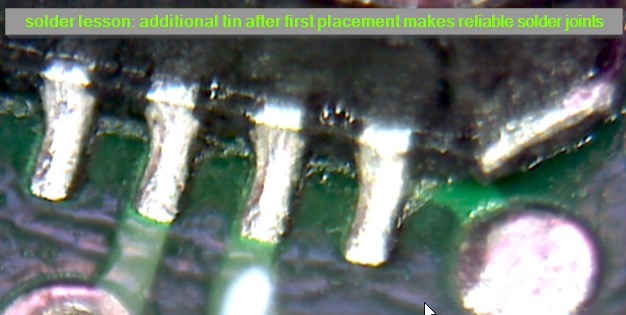
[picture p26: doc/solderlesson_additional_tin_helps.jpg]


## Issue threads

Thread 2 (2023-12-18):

Add wakeup logic

jsphuebner, 2023-12-18:
In order to start up foccci and other components needed for rapid charging, it should be possible to
a) wake up foccci via the PP signal (i.e. plug seated indication)
b) Have foccci wake up or power additional components

Discussed here https://openinverter.org/forum/viewtopic.php?p=64221#p64221

uhi22, 2023-12-18:
Dedicated thread for discussion is here: https://openinverter.org/forum/viewtopic.php?p=65022#p65022

uhi22, 2024-10-26:
Wakeup via CP, PP, button and wakeup line works with Foccci version 5 and 5.1. Closing.

Closed 2024-10-26.

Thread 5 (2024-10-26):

Too large pads for the RF transformer may lead to solder bridges

uhi22, 2024-10-26:
We found two JLC populated Focccis with solder bridge below the RF transformer.
The amount of solder shall be reduced by shrinking the pads, which should lead to less solder paste.
Discussed here: https://openinverter.org/forum/viewtopic.php?p=76150#p76150

Or even better (thanks johu): Kick the transformer out completely.

uhi22, 2025-01-05:
Kicked out the transformer completely. Version 5.2p7 is the first transformerless version, and was tested okay.
Closing this issue.

Closed 2025-01-05.

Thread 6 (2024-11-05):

Add UART3 pin header

uhi22, 2024-11-05:
To give some flexibility like flashing via UART and maybe serial display or whatever.
Discussed here: https://openinverter.org/forum/viewtopic.php?p=76455#p76455

uhi22, 2024-11-28:
Done with https://github.com/uhi22/foccci/commit/413c8ef2a10fd3ce8bdf70788c21fc362a79e89f

Closed 2024-11-28.

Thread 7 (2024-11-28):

Layout improvements - feedback from review

uhi22, 2024-11-28:
Feedback from jrbe revealed a lot of improvement possibilities. Thanks for this. Just tracking it here in an issue, to avoid loss of information.

1. Do J3 & J5 have enough room to the box for clearance? If you want you can set a components keepout on the edges where the box lips are - if it has them.. I think the front courtyard area is purple to try to keep stuff out of those sections. Or just for bench testing?
2. For the C77-C80 + area there is 1 thin ground for a string of 9? capacitors & resistors. I'd suggest bumping them over a bit and adding a top local thermal relief GND plane with a bunch of stitching vias to gnd. I always try to stitch ground pads to the inner ground plane just to avoid issues.
3. You have +3V3 & GND in the 2 inner planes but use a bit of a spiderweb of a plane on top to connect things. It can get hard to track whats going on for good connections using the woven top method. Rules check will see things connected even though it might be a very thin trace, a lot of heavy items on it, or a long convoluted path. I'd suggest using the inner planes as +3V3 & GND and routing the high speed lines on top of the inner ground plane. Dropping vias everywhere they're needed locally.
4. Y2 / Y3 backup crystal footprint - Is it still necessary?
5. If you leave the planes off the top and bottom layers you can use small sections of planes for ground, power, etc. on the top or bottom layers to connect groups. It takes a bit to remember you have the power and ground pretty much everywhere for you but it helps simplify things a ton. You can likely eliminate the planes on the top and bottom and start there if you want. I usually do one trace and via to power / ground for a pad then just copy / paste that trace and via everywhere its needed.
6. the inner power plane can have a trace for the 1.2v line. You can make the 3v3 a U shape around it if you're worried about making a loop. Whats there gets thin and makes some loops around C40.
7. via in pad is ok if you are doing filled & capped vias, otherwise theres a chance it ends up a dry solder joint from the solder wicking into the via hole or toumbstoning if the hole is on the edge of the pad. You can put the vias off the edge of the pad, past the solder mask and not worry about the solder going anywhere. The soldermask will block it.
8. Pin 1 dots next to ICs help fabrication breeze through the assembly and troubleshooting. I know there are other methods but they are all less quick and clear, at least for me.
9. Design Rules Checker (DRC) helps find important and less important issues. There are some footprint overlaps to bump a bit and silkscreen overlaps if it matters to you.
10. plane minimum size can be adjusted to flow a bit better between pads and things. JLC is fine with .2 plane sections between items, that's usually all it takes to not have fingers of the plane flow almost touching.
11. I usually try to do +3V3 or gnd on an inner layer, via up, capacitor pad, then pad. I try to keep the capacitor pad as the connection between to keep it clean. If it drops back down to the inner planes then up again its hard to say its decoupled well still. Almost every datasheet says to keep the capacitor as close as practical to the pin.
12. D13 is close to the main connector screw boss. It should work but could likely move a bit.
13. Temp1 male pin pokes through the connector housing. The J2 & J4 connectors look to be an extra though, so maybe it doesn't matter for your use case??
14. foccci icon has an extra miso / mosi / reset / etc label under him.
15. the ground pour on the bottom might be unnecessary. Removing it only sets 1 item as not connected. It shouldn't hurt to leave it there.
16. Of note: KiCad added teardrops in version 8. Its not a huge deal but teardrops can be added to all or specific types of areas if you want. Can help the trace connections to vias and other things long term.

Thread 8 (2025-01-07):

12V power supply documentation

glt248, 2025-01-07:
Hello,
First, thank you for your work on this project.

As your wiki says in the Pin description :

    `12V 	B8 	B8 	Supply voltage, always on. 9 to 24V are fine. `

But at 24V, the ADC_button signal will rise to 4.29V from calc, but the pin PC4 on the STM32F103 is not 5V tolerant. Do I miss a protection on your schematic ?  Max supply value seams to be under 18.45 V.

I will test FOCCCI on a 28V LVDC project, and I look for alternate references for non-28V tolerant components. I will submit them when I will test them.

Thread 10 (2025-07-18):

STM32 output protection

maciek16c, 2025-07-18:
I think additional protection should be added to the microcontroller outputs that drive transistors. A gate resistor will probably be sufficient. If any MOSFET in the 12V control circuit shorts, it could potentially feed 12V directly into the MCU. This actually happened in the wake-up circuit, where Q11 and Q13 were damaged and the STM32 was destroyed.

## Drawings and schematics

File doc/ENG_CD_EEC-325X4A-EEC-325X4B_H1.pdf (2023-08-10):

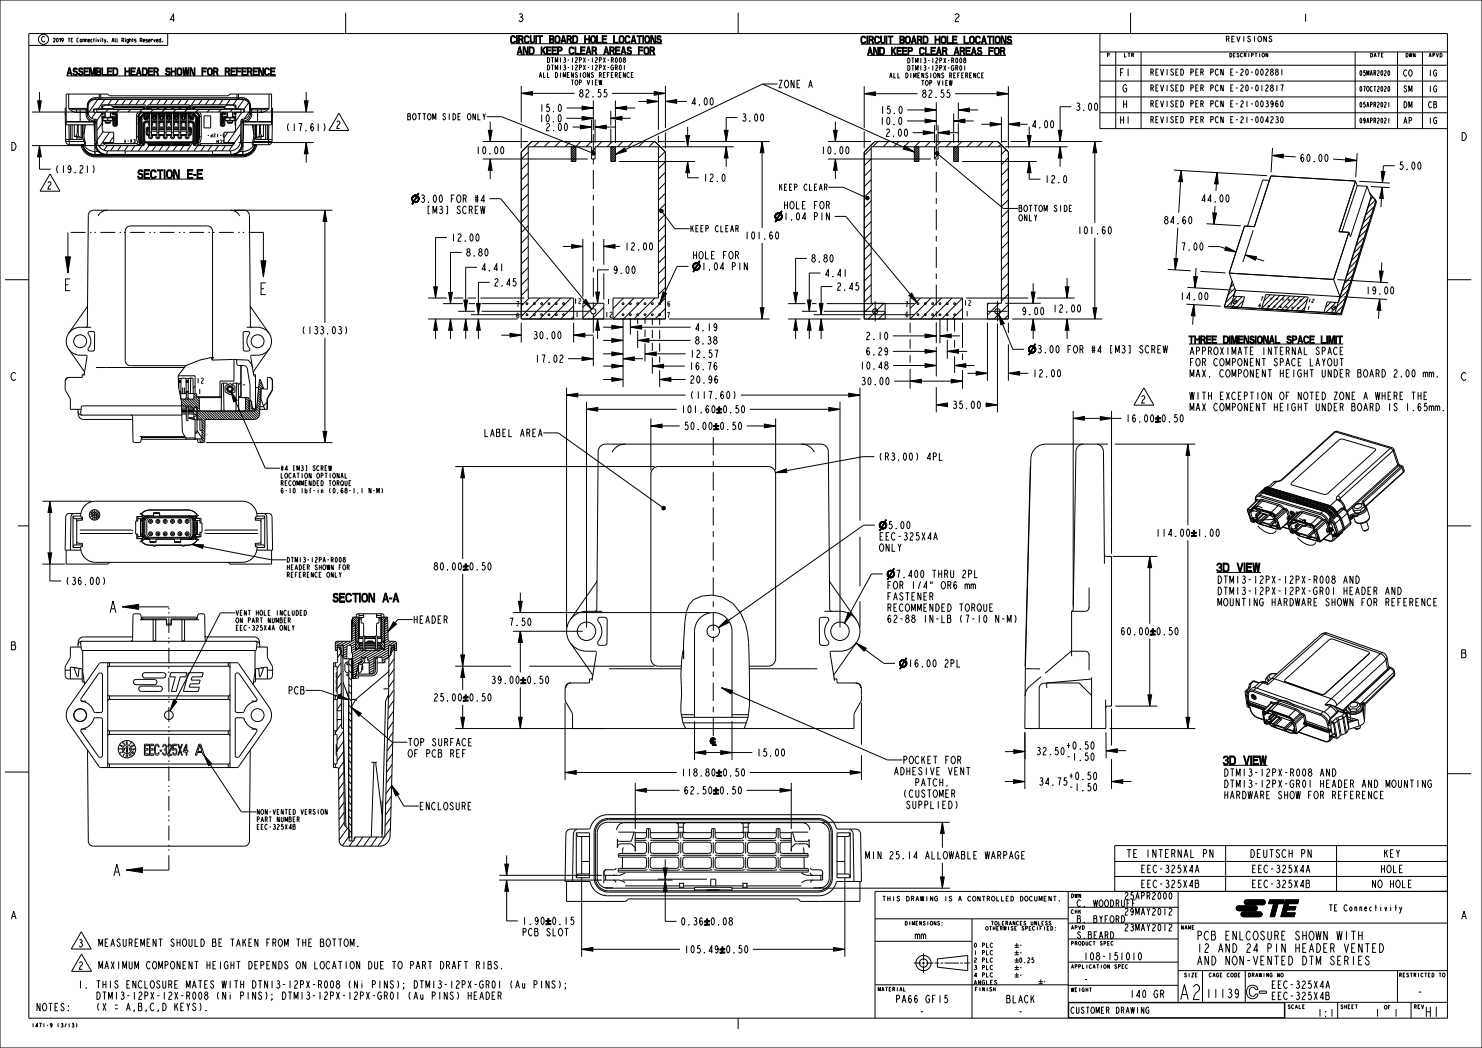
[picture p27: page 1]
REVISIONS; 0 PLC 1 PLC 2 PLC 3 PLC 4 PLC ANGLES; SCALE; SHEET; REV; SIZE; CAGE; CODE; DRAWING NO; DIMENSIONS:; TOLERANCES UNLESS; OTHERWISE; SPECIFIED:; CHK; APVD; MATERIAL; FINISH; PRODUCT SPEC; APPLICATION SPEC; WEIGHT; LTR; DESCRIPTION; DATE; DWN; RESTRICTED TO; CUSTOMER DRAWING; 29MAY2012; BLACK; Connectivity. All; Rights Reserved.; F1 REVISED PER PCN E-20-002881; 05MAR2020 CO IG; REVISED PER PCN E-20-012817; 07OCT2020; REVISED PER PCN E-21-003960; 05APR2021; REVISED PER PCN E-21-004230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

ASSEMBLED HEADER SHOWN FOR REFERENCE

CIRCUIT BOARD HOLE LOCATIONS
AND KEEP CLEAR AREAS FOR

BOTTOM SIDE ONLY

THREE DIMENSIONAL SPACE LIMIT
APPROXIMATE INTERNAL SPACE
FOR COMPONENT SPACE LAYOUT
MAX. COMPONENT HEIGHT UNDER BOARD 2.00 mm.
WITH EXCEPTION OF NOTED ZONE A WHERE THE
MAX COMPONENT HEIGHT UNDER BOARD IS 1.65mm.

DTM13-12PA-R008
HEADER SHOWN FOR
REFERENCE ONLY
SECTION A-A

3D VIEW
DTM13-12PX-12PX-R008 AND
DTM13-12PX-12PX-GR01 HEADER AND
MOUNTING HARDWARE SHOWN FOR REFERENCE

VENT HOLE INCLUDED
ON PART NUMBER
EEC-325X4A ONLY

TOP SURFACE
OF PCB REF

DTM13-12PX-R008 AND
DTM13-12PX-GR01 HEADER AND MOUNTING
HARDWARE SHOW FOR REFERENCE

NON-VENTED VERSION
PART NUMBER
EEC-325X4B

MIN 25.14 ALLOWABLE WARPAGE

25APR2000 DWN C. WOODRUFF B. BYFORD 23MAY2012 S.BEARD | TE Connectivity

THIS DRAWING IS A CONTROLLED DOCUMENT.

NAME
PCB ENLCOSURE SHOWN WITH

MEASUREMENT SHOULD BE TAKEN FROM THE BOTTOM.
MAXIMUM COMPONENT HEIGHT DEPENDS ON LOCATION DUE TO PART DRAFT RIBS.
1. THIS ENCLOSURE MATES WITH DTN13-12PX-R008 (Ni PINS); DTM13-12PX-GR01 (Au PINS);
DTM13-12PX-12X-R008 (Ni PINS); DTM13-12PX-12PX-GR01 (Au PINS) HEADER
(X = A,B,C,D KEYS).

12 AND 24 PIN HEADER VENTED AND NON-VENTED DTM SERIES

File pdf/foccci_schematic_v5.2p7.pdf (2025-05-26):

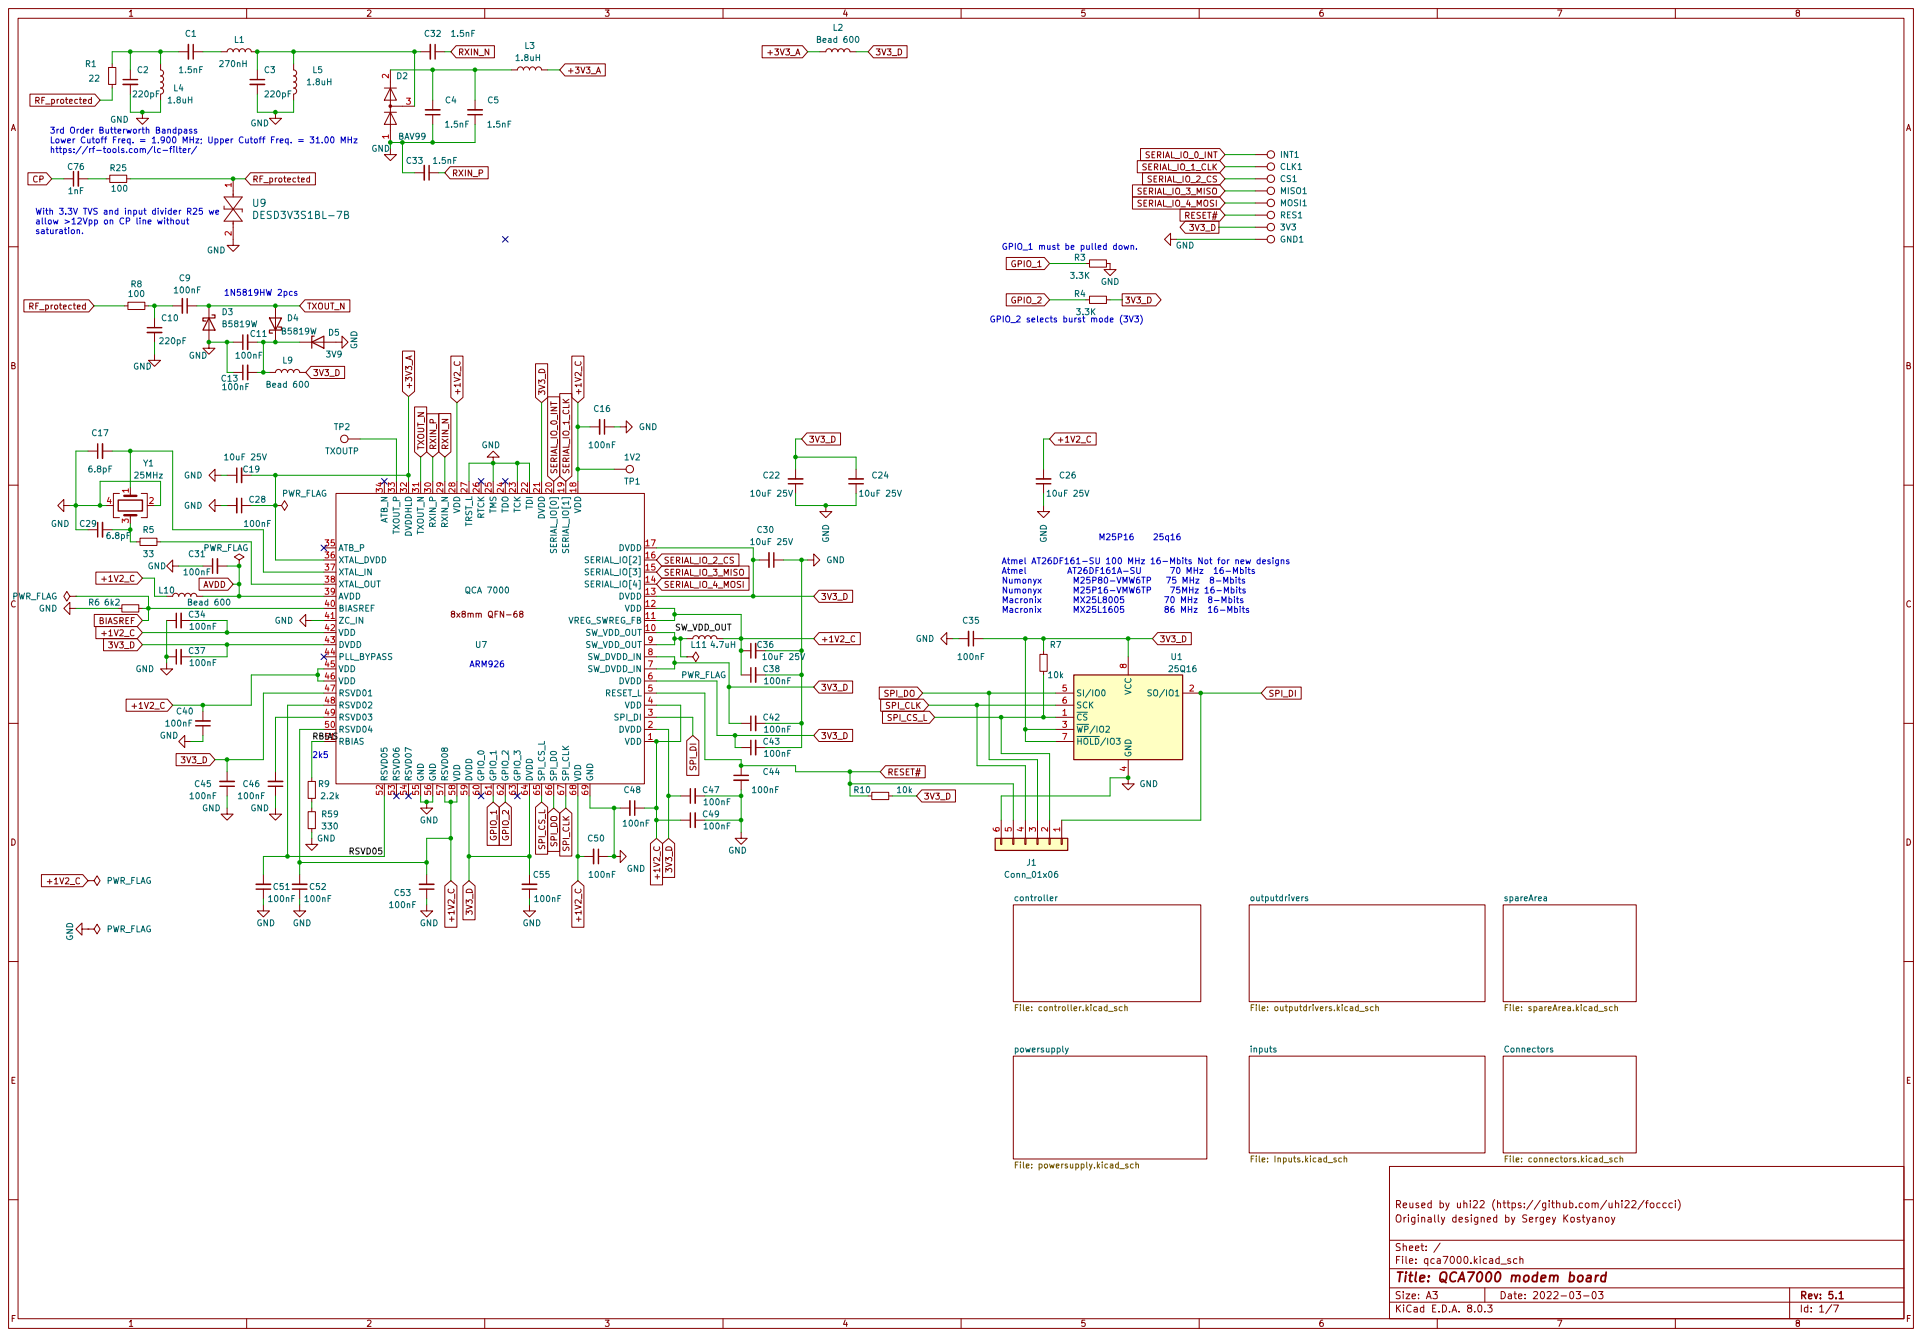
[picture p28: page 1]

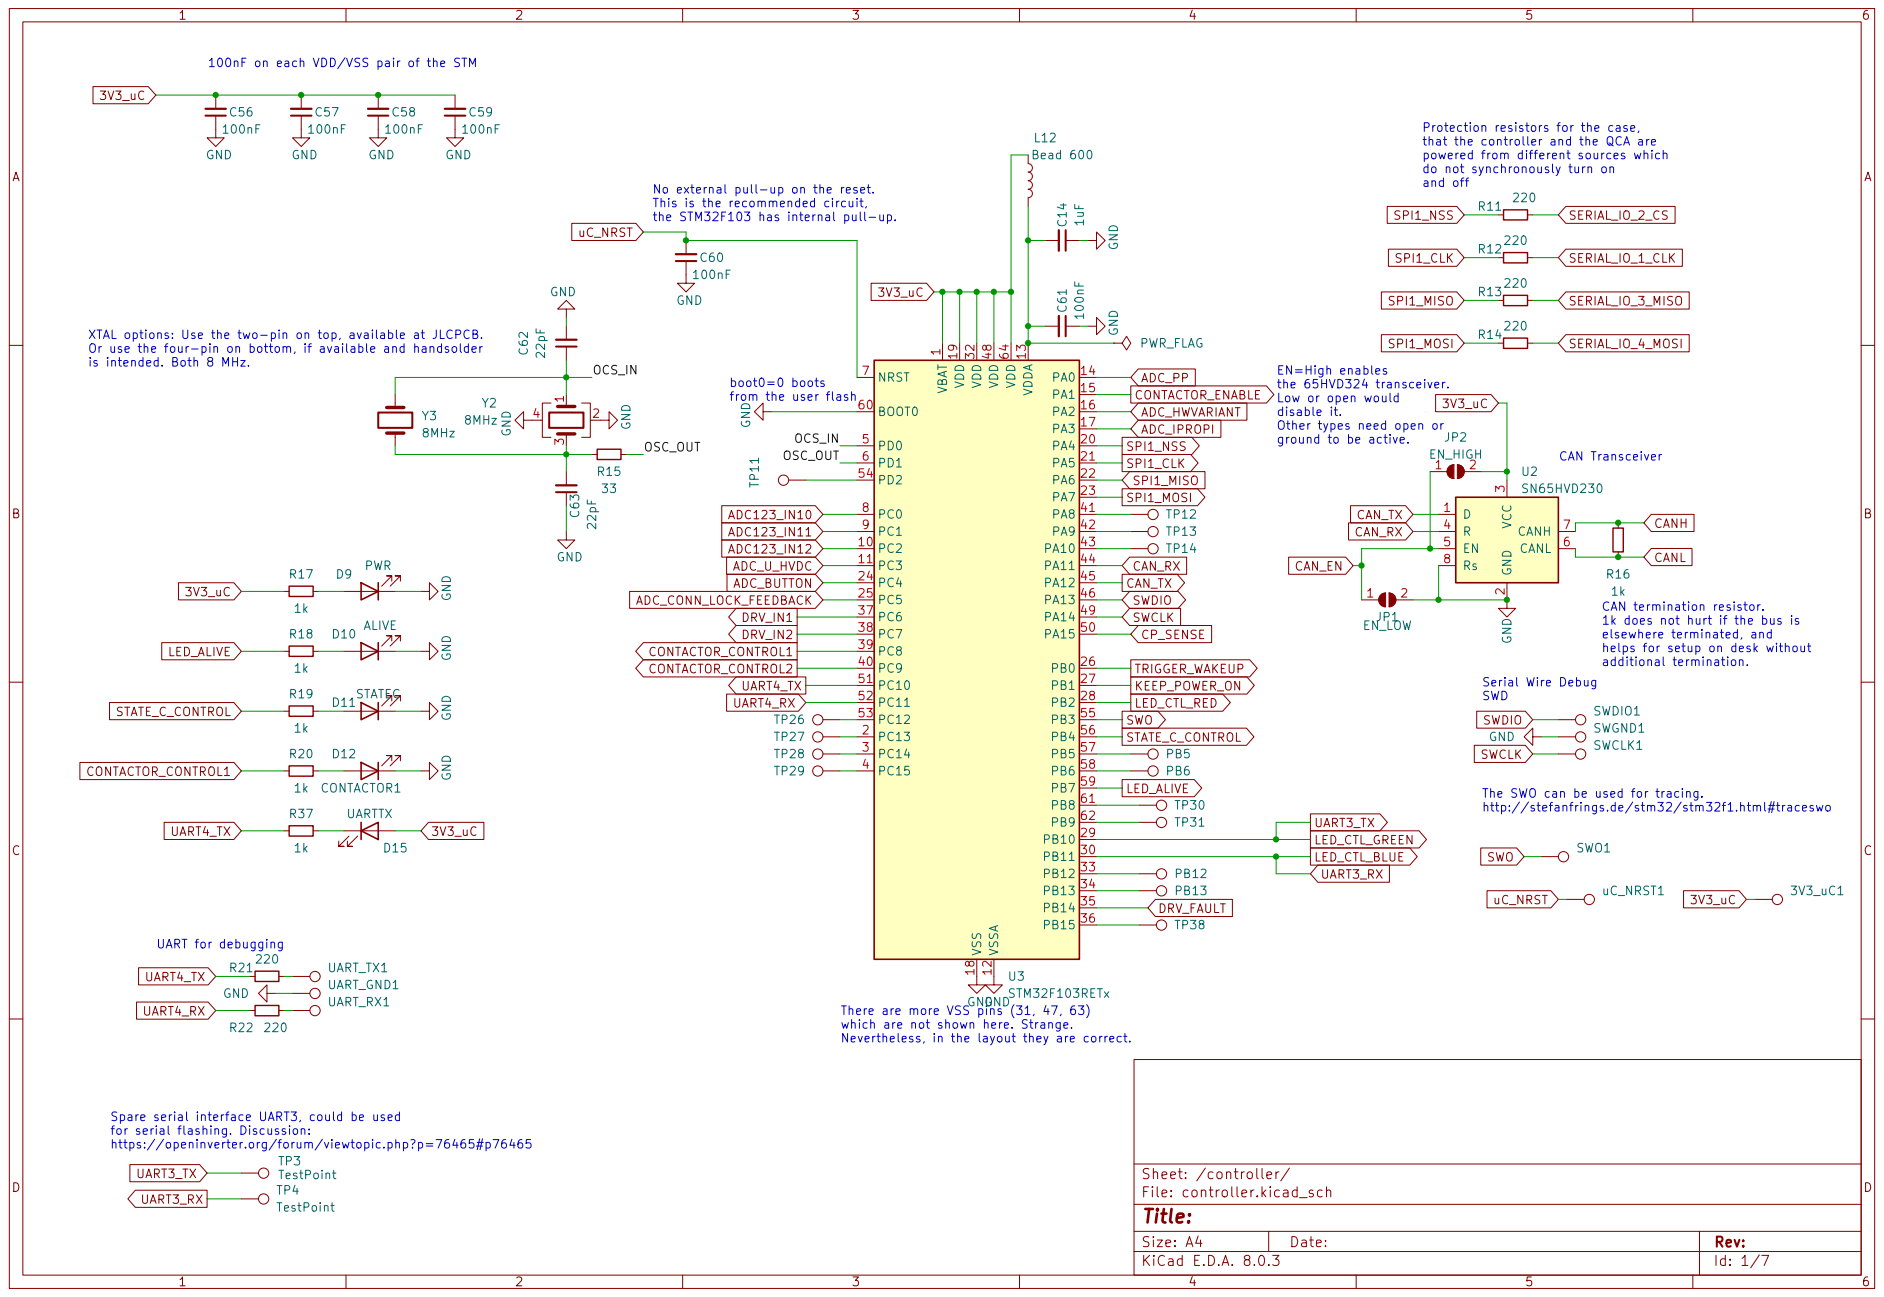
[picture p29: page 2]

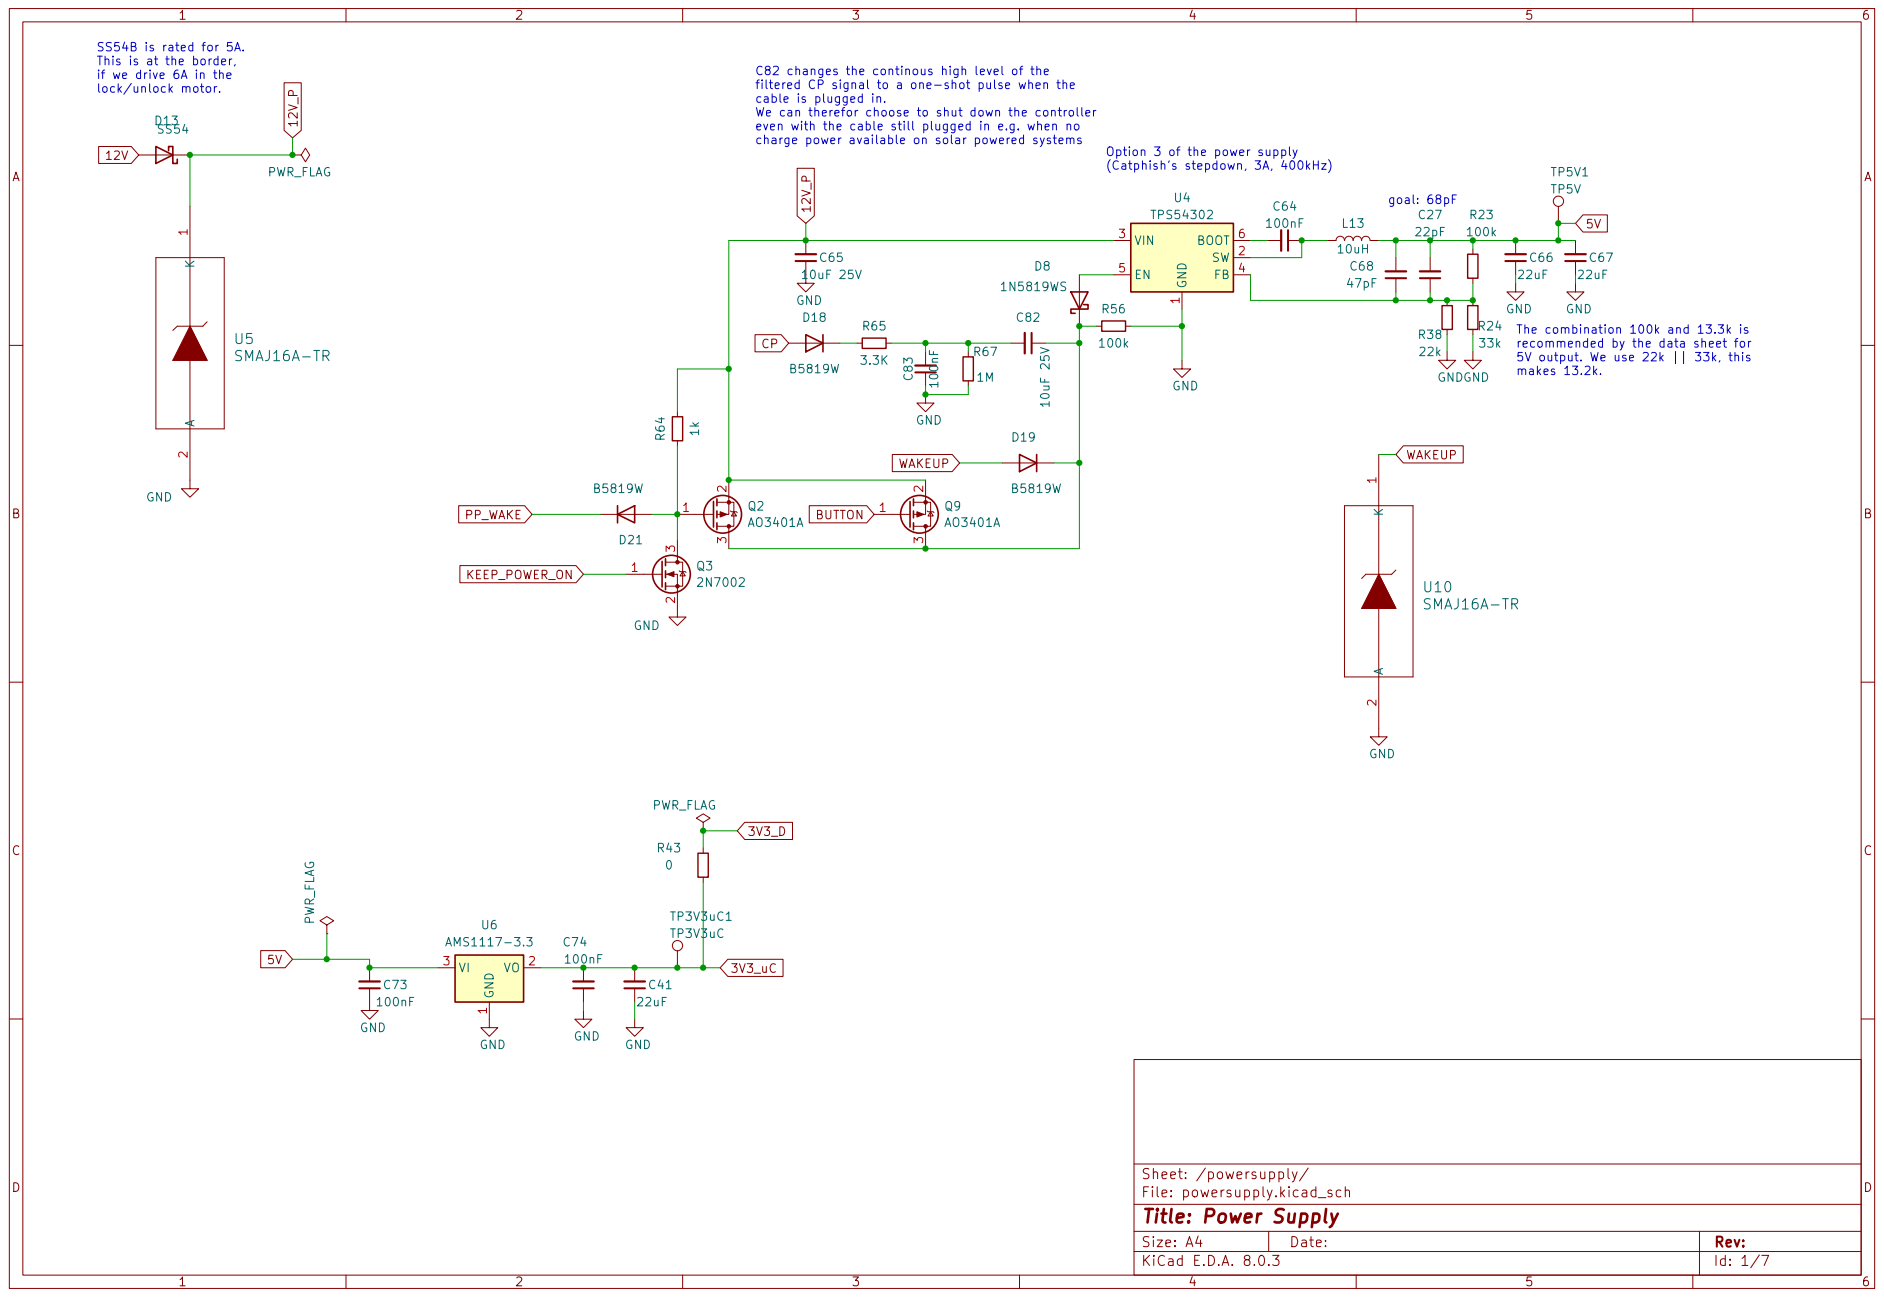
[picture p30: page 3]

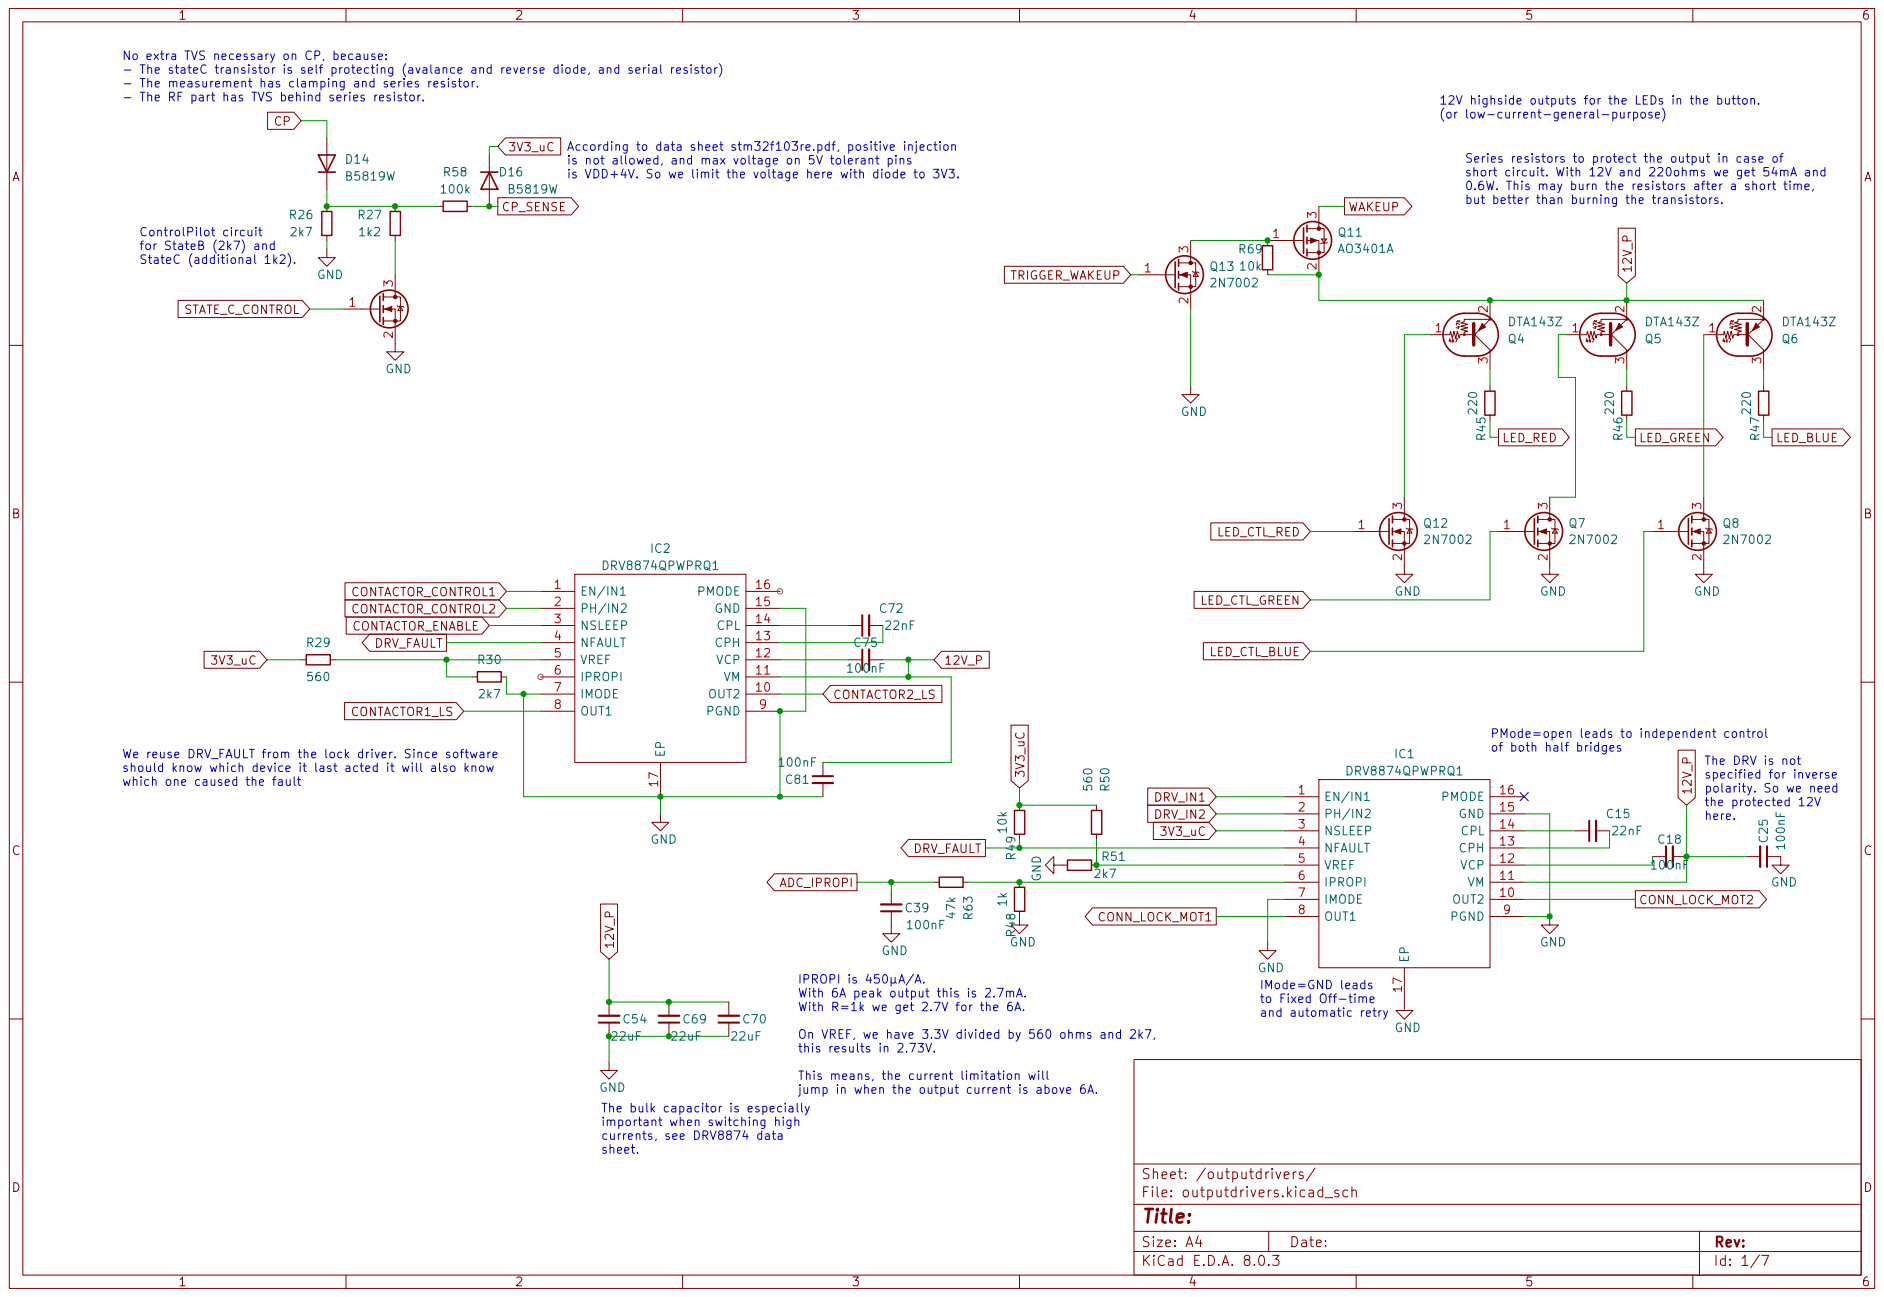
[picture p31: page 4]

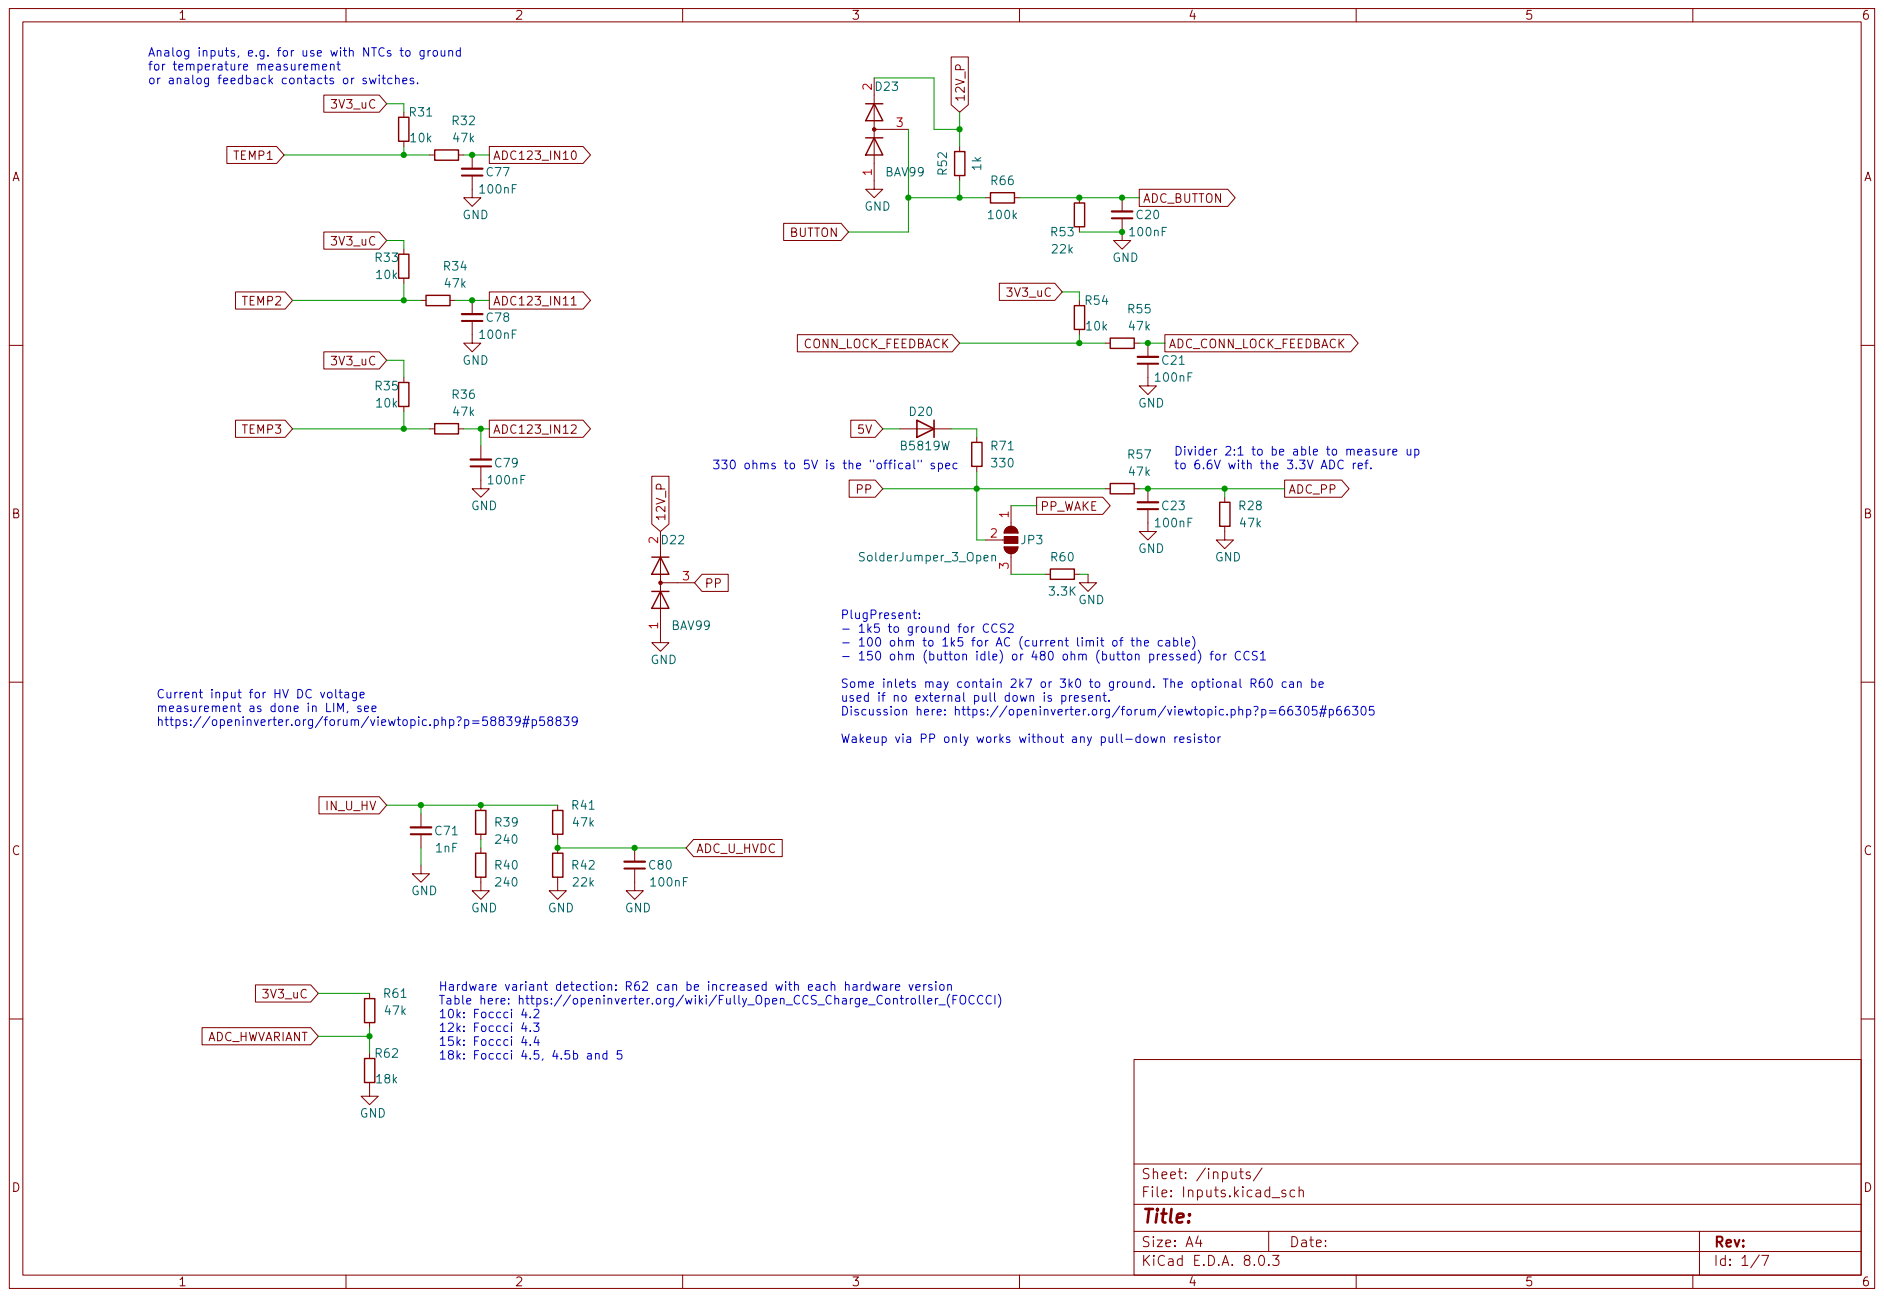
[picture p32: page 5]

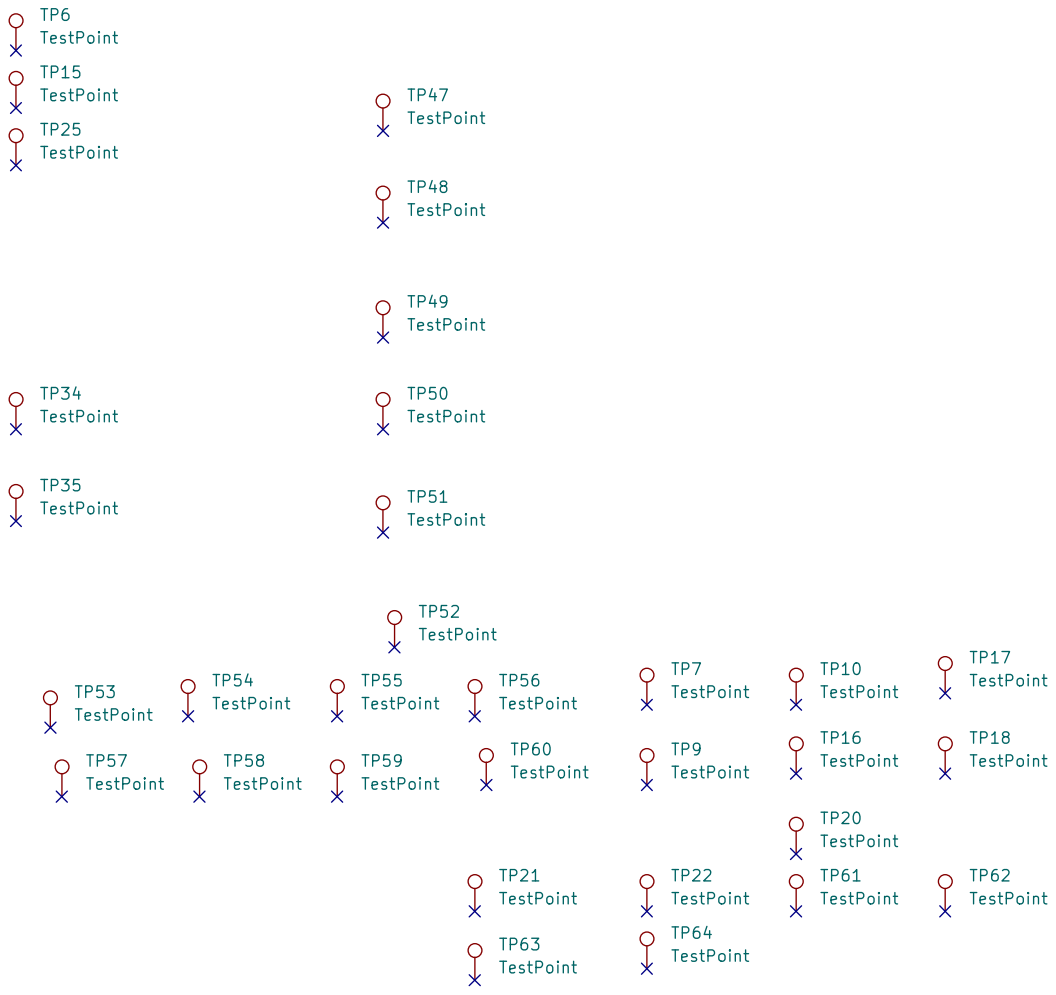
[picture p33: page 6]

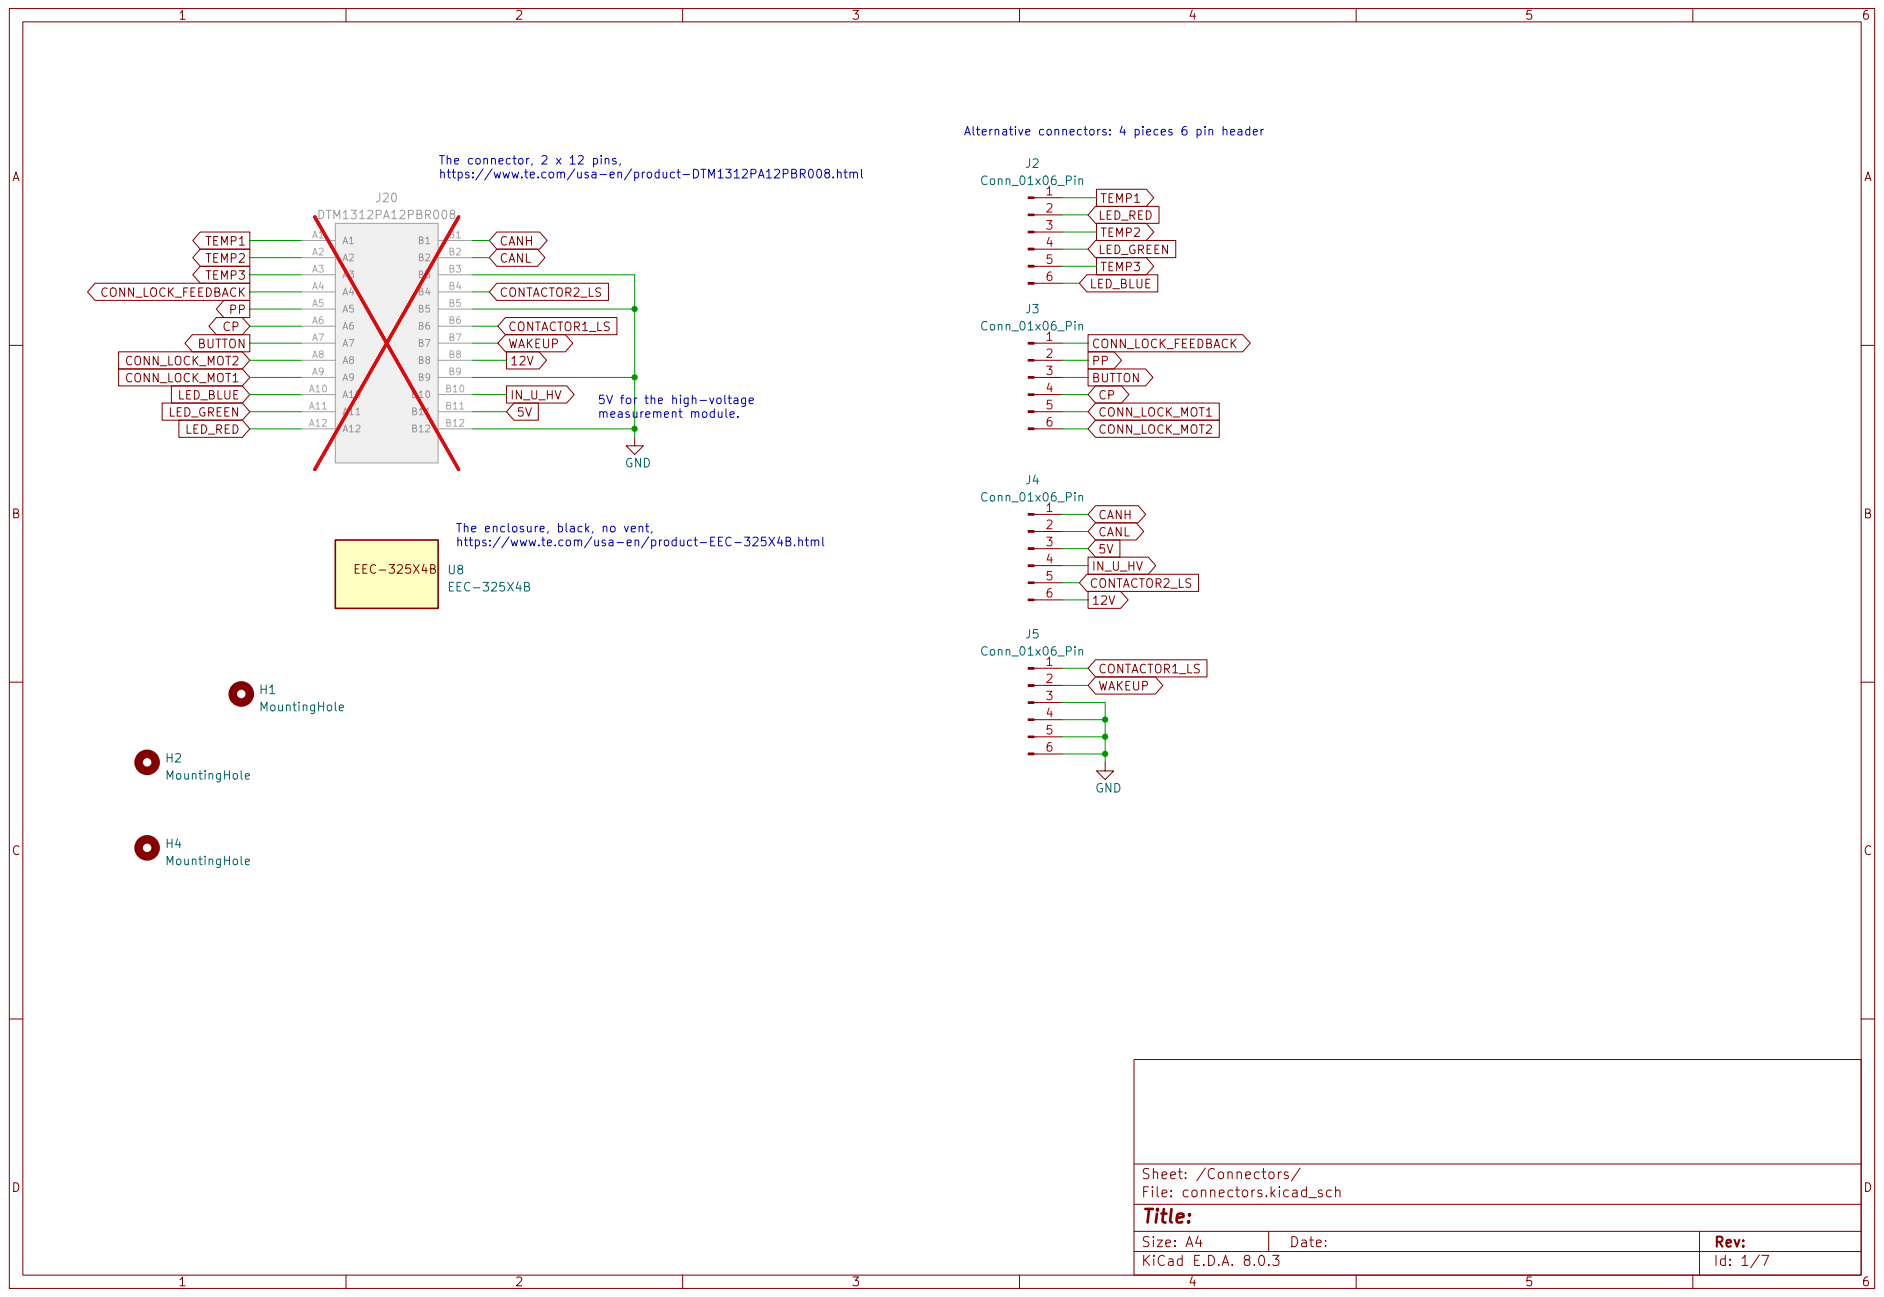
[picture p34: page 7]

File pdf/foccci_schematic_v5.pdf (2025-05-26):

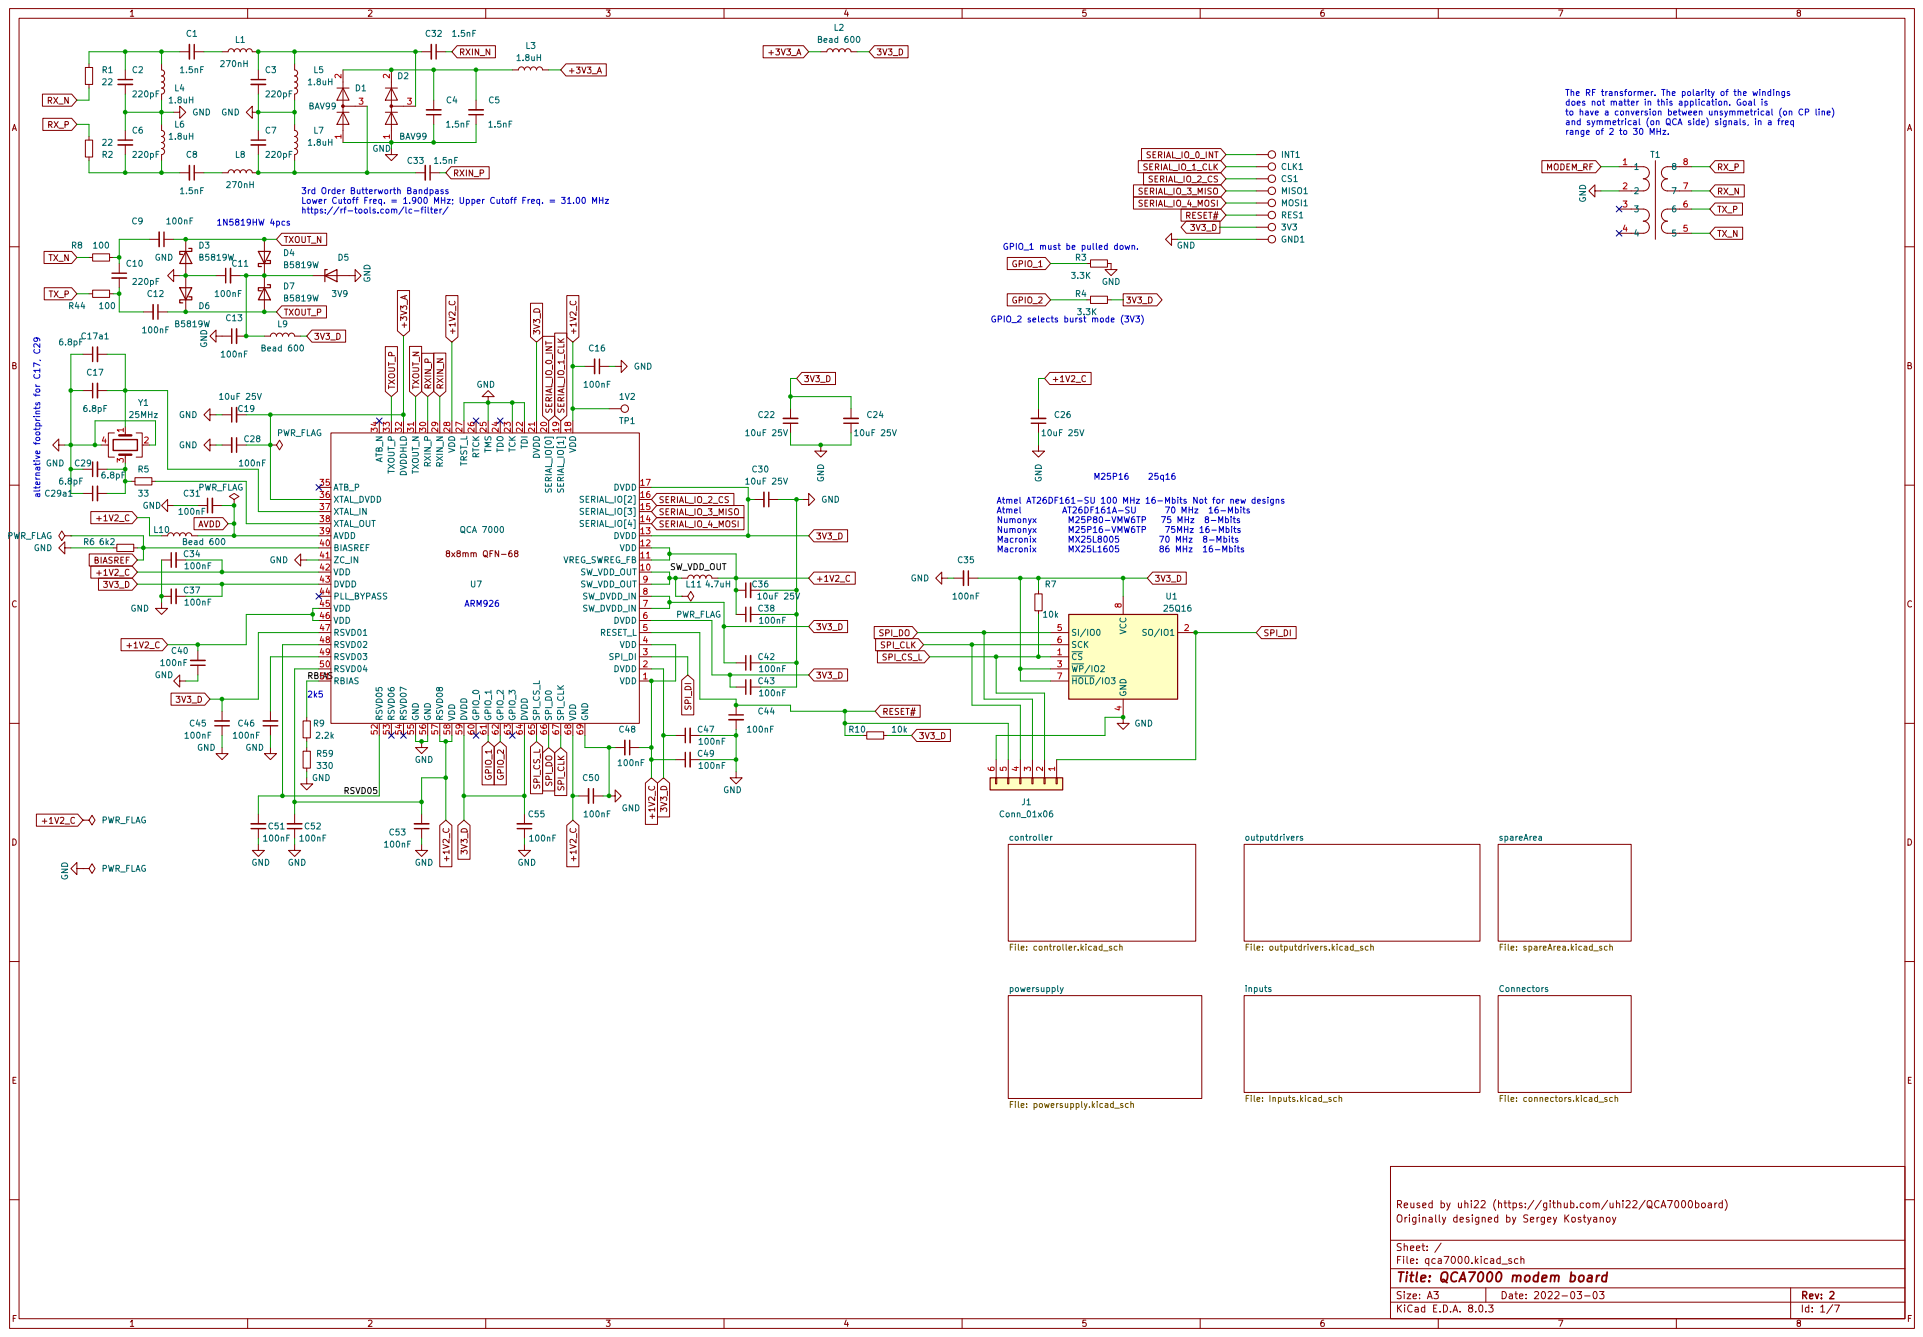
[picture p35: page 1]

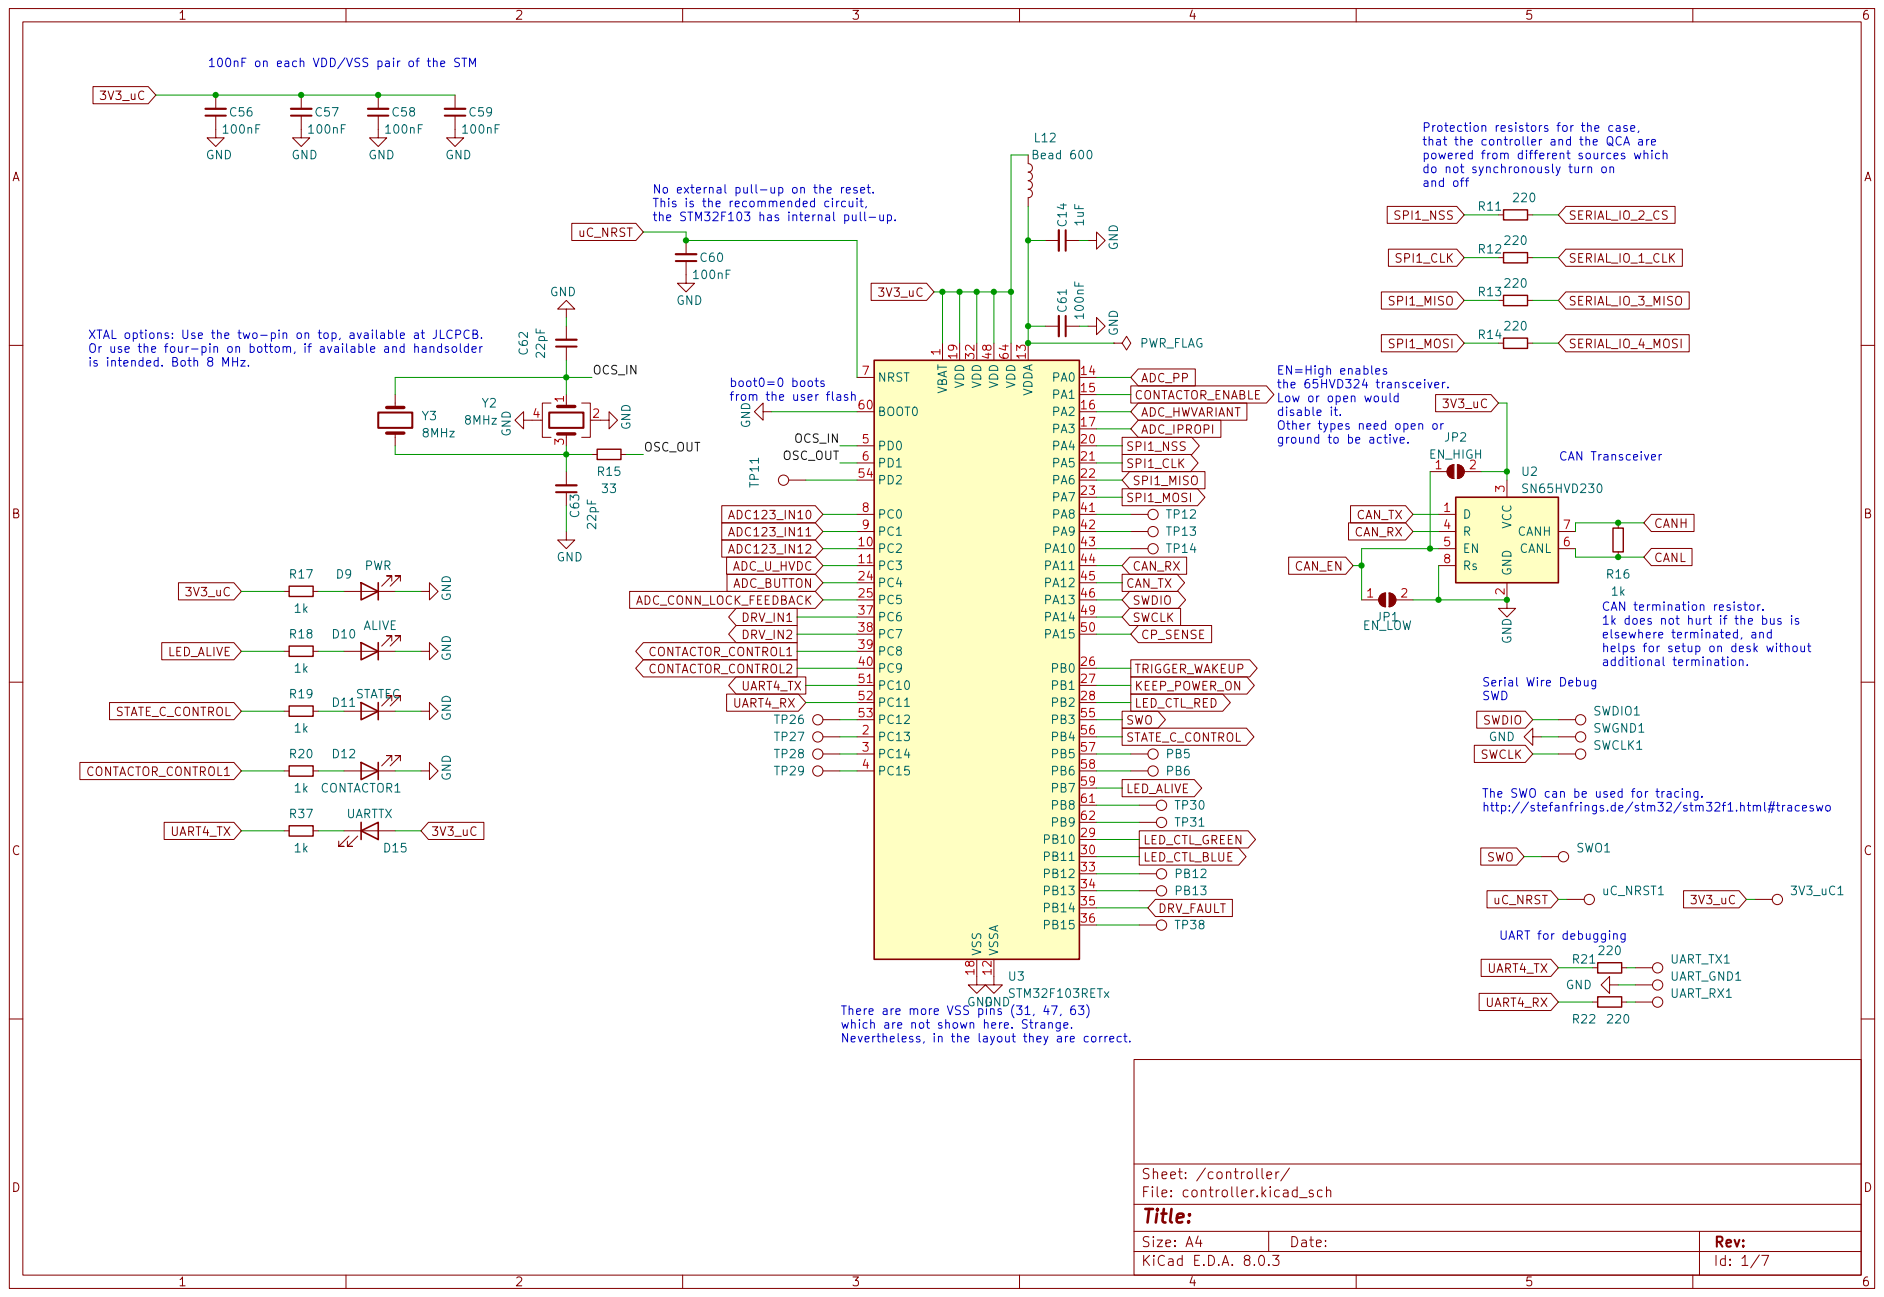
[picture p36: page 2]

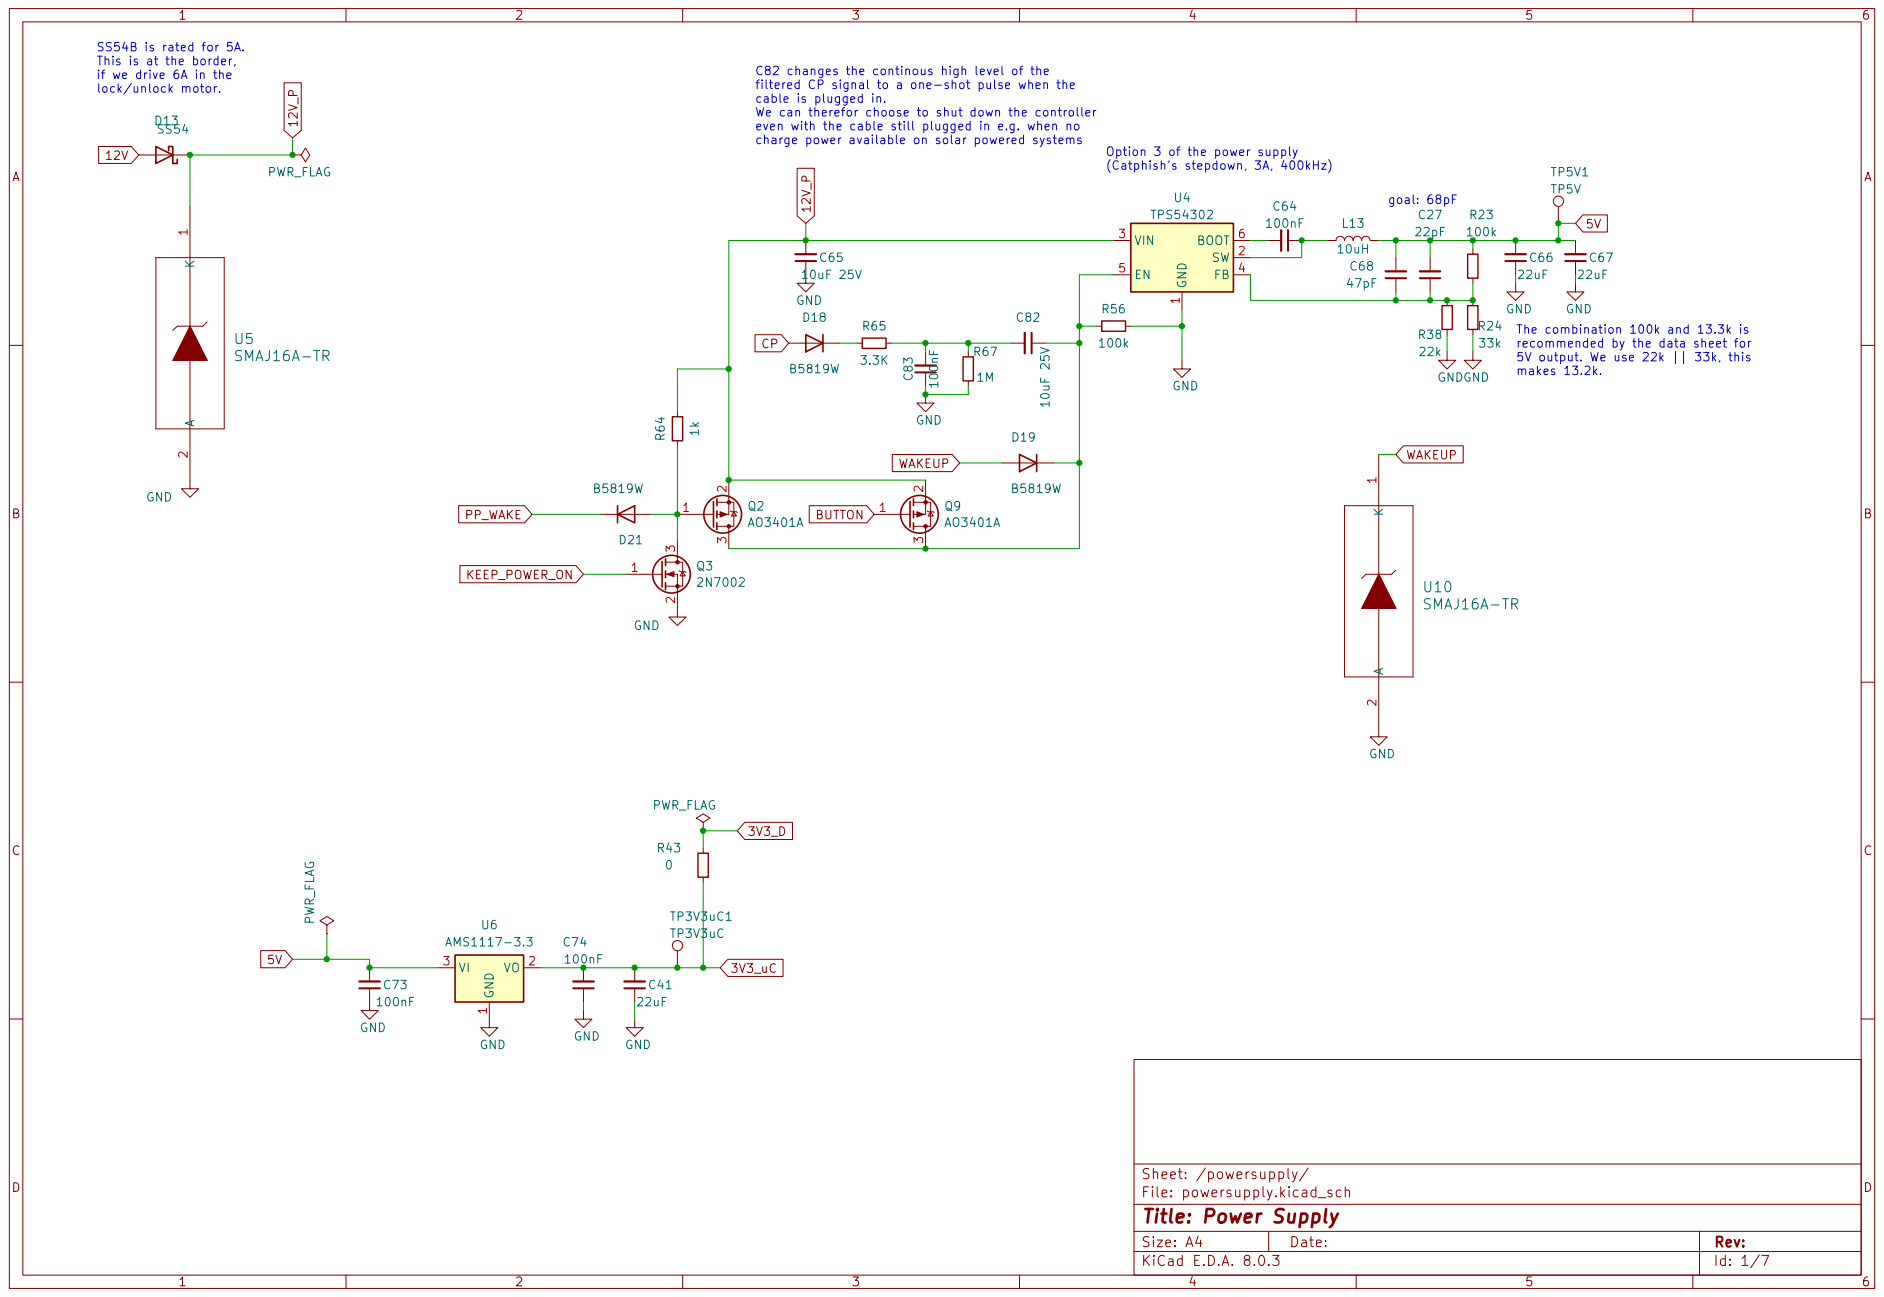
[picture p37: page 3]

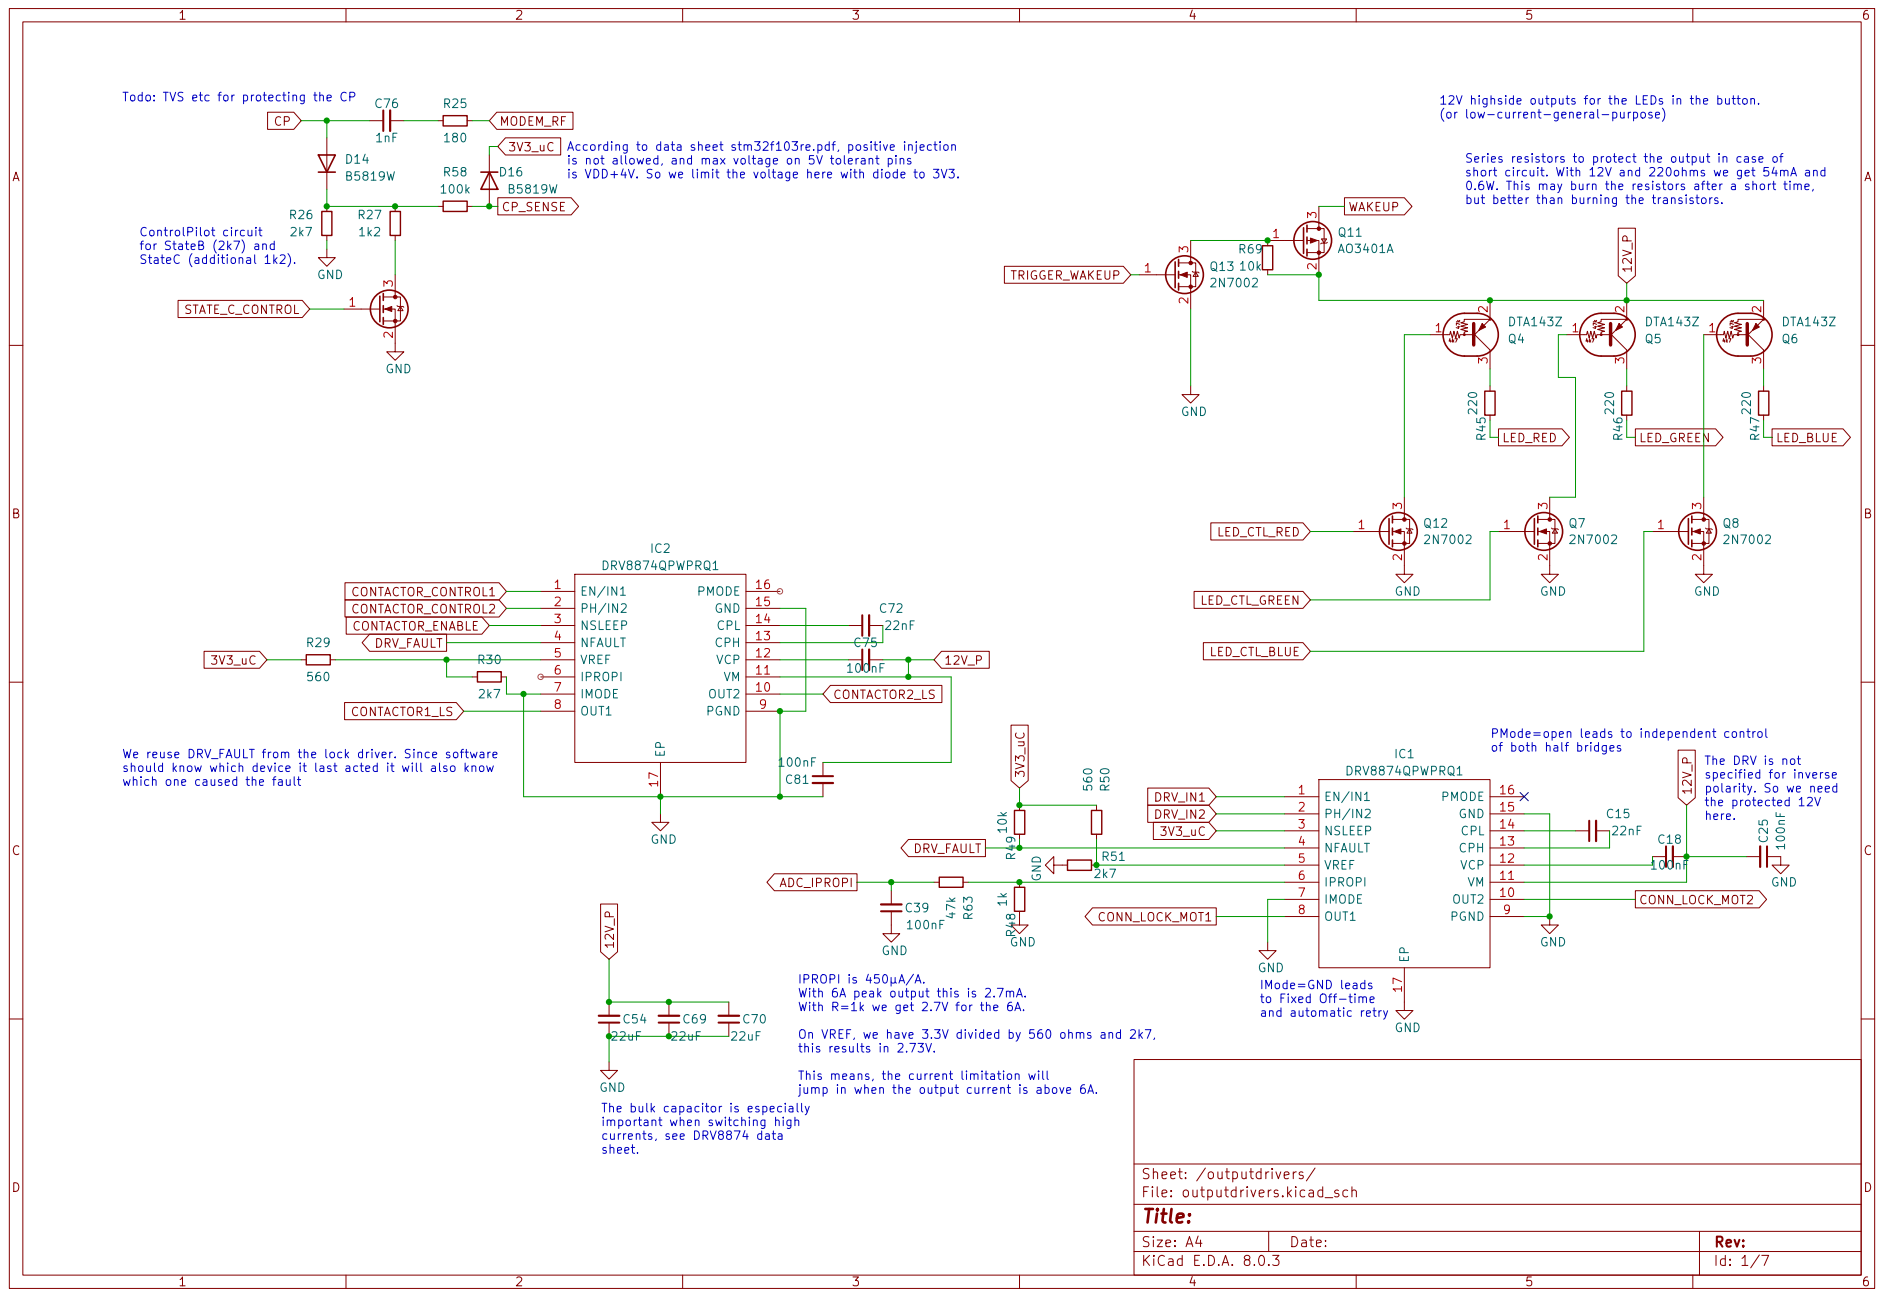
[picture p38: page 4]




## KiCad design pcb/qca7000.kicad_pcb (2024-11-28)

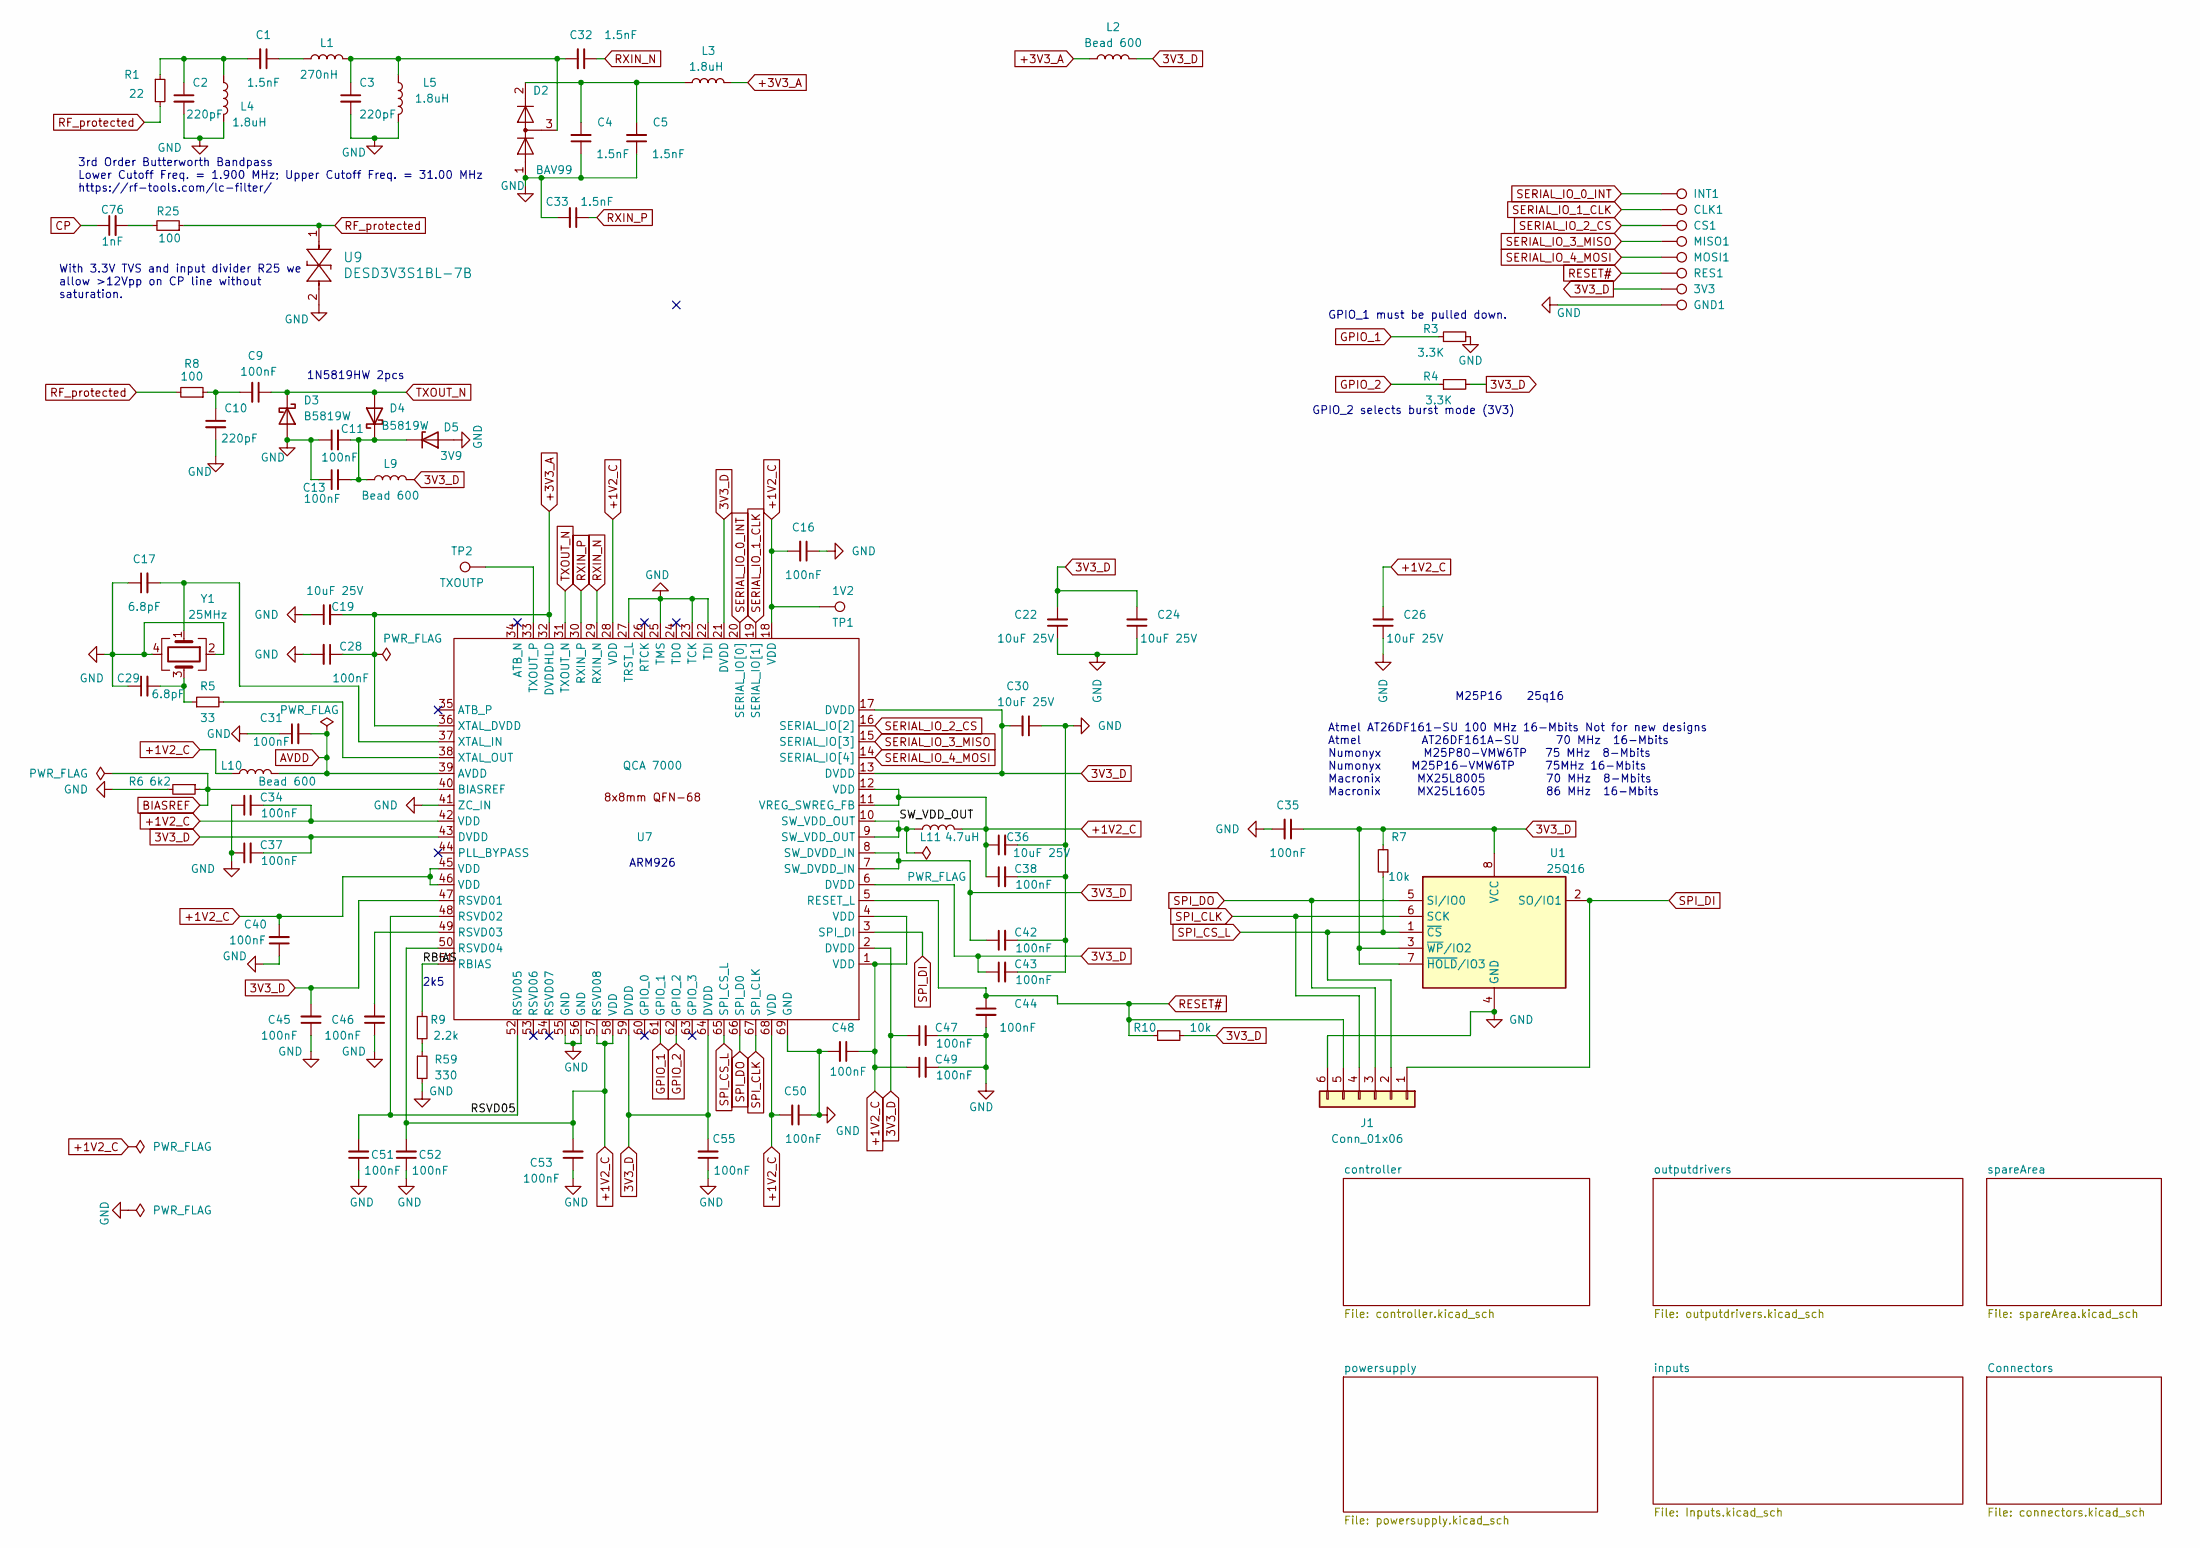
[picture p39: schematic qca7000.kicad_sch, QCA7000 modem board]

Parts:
3V3: TestPoint_Special_THTPad_D1.9mm_Drill1mm
C1, C4, C5, C32, C33: 1.5nF; C_0805_2012Metric_Pad1.18x1.45mm_HandSolder; LCSC C1717
C2, C3, C10: 220pF; C_0805_2012Metric_Pad1.18x1.45mm_HandSolder; LCSC C107145
C9, C11, C13, C16, C28, C31, C34, C35, C37, C38, C40, C42, C43, C44, C45, C46, C47, C48, C49, C50, C51, C52, C53, C55: 100nF; C_0805_2012Metric_Pad1.18x1.45mm_HandSolder; LCSC C49678
C17, C29: 6.8pF; C_0603_1608Metric_Pad1.08x0.95mm_HandSolder; LCSC C1679
C19, C22, C24, C26, C30, C36: 10uF 25V; C_0805_2012Metric_Pad1.18x1.45mm_HandSolder; LCSC C15850
C76: 1nF; C_0805_2012Metric_Pad1.18x1.45mm_HandSolder; LCSC C46653
CLK1: TestPoint_Special_THTPad_D1.9mm_Drill1mm
CS1: TestPoint_Special_THTPad_D1.9mm_Drill1mm
D2: BAV99; SOT-23; LCSC C2500
D3, D4: B5819W; D_SOD-123; LCSC C8598
D5: 3V9; D_SMA; LCSC C438352
GND1: TestPoint_Special_THTPad_D1.9mm_Drill1mm
INT1: TestPoint_Special_THTPad_D1.9mm_Drill1mm
J1: Conn_01x06; PinHeader_1x06_P2.54mm_Vertical
L1: 270nH; L_0805_2012Metric_Pad1.05x1.20mm_HandSolder; LCSC C281081
L2, L9, L10: Bead 600; L_0805_2012Metric_Pad1.15x1.40mm_HandSolder; LCSC C1017
L3, L4, L5: 1.8uH; L_0603_1608Metric_Pad1.05x0.95mm_HandSolder; LCSC C78153
L11: 4.7uH; L_1206_3216Metric_Pad1.22x1.90mm_HandSolder; LCSC C162588
MISO1: TestPoint_Special_THTPad_D1.9mm_Drill1mm
MOSI1: TestPoint_Special_THTPad_D1.9mm_Drill1mm
R1: 22; R_0805_2012Metric_Pad1.20x1.40mm_HandSolder; LCSC C17561
R3, R4: 3.3K; R_0805_2012Metric_Pad1.20x1.40mm_HandSolder; LCSC C26010
R5: 33; R_0805_2012Metric_Pad1.20x1.40mm_HandSolder; LCSC C17634
R6: 6k2; R_0805_2012Metric_Pad1.20x1.40mm_HandSolder; LCSC C4260
R7, R10: 10k; R_0805_2012Metric_Pad1.20x1.40mm_HandSolder; LCSC C17414
R8, R25: 100; R_0805_2012Metric_Pad1.20x1.40mm_HandSolder; LCSC C17408
R9: 2.2k; R_0805_2012Metric_Pad1.20x1.40mm_HandSolder; LCSC C17520
R59: 330; R_0805_2012Metric_Pad1.20x1.40mm_HandSolder; LCSC C23138
RES1: TestPoint_Special_THTPad_D1.9mm_Drill1mm
TP1: 1V2; TestPoint_Pad_D1.0mm
TP2: TXOUTP; TestPoint_Pad_D1.0mm
U1: 25Q16; SOIC-8_3.9x4.9mm_P1.27mm; LCSC C115407
U7: QCA 7000; QFN-68-1EP_8x8mm_P0.4mm_EP5.2x5.2mm_ThermalVias; LCSC C9900078626
U9: DESD3V3S1BL-7B; X1-DFN1006-2_RH_DIO; LCSC C500765
Y1: 25MHz; Crystal_SMD_TXC_7M-4Pin_3.2x2.5mm; LCSC C9006

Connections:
3V3_D: 3V3.1, C22.2, C24.2, C30.2, C35.1, C37.2, C42.1, C43.1, C45.2, C47.1, C55.2, L2.2, L9.2, R4.2, R7.2, R10.2, U1.3 (~WP/IO2), U1.7 (~HOLD/IO3), U1.8 (VCC), U7.2 (DVDD), U7.6 (DVDD), U7.7 (SW_DVDD_IN), U7.8 (SW_DVDD_IN), U7.13 (DVDD), U7.17 (DVDD), U7.21 (DVDD), U7.43 (DVDD), U7.47 (RSVD01), U7.59 (DVDD), U7.64 (DVDD); also elsewhere on the board
+1V2_C: C16.2, C26.2, C34.2, C36.1, C38.1, C40.2, C48.1, C49.1, C50.2, C52.2, C53.2, L10.2, L11.2, TP1.1, U7.1 (VDD), U7.4 (VDD), U7.11 (VREG_SWREG_FB), U7.12 (VDD), U7.18 (VDD), U7.28 (VDD), U7.42 (VDD), U7.45 (VDD), U7.46 (VDD), U7.50 (RSVD04), U7.57 (RSVD08), U7.58 (VDD), U7.68 (VDD)
+3V3_A: C19.2, C28.1, L2.1, L3.2, U7.32 (DVDDHLD), U7.36 (XTAL_DVDD)
/RBIAS: R9.1, U7.51 (RBIAS)
/RSVD05: C51.2, U7.48 (RSVD02), U7.52 (RSVD05)
/SW_VDD_OUT: L11.1, U7.9 (SW_VDD_OUT), U7.10 (SW_VDD_OUT)
AVDD: C31.2, L10.1, U7.39 (AVDD)
BIASREF: R6.1, U7.40 (BIASREF)
CP: C76.1; also elsewhere on the board
GND: C2.2, C3.2, C4.1, C5.1, C10.2, C11.1, C13.1, C16.1, C17.1, C19.1, C22.1, C24.1, C26.1, C28.2, C29.1, C30.1, C31.1, C33.2, C34.1, C35.2, C36.2, C37.1, C38.2, C40.1, C42.2, C43.2, C44.2, C45.1, C46.1, C47.2, C48.2, C49.2, C50.1, C51.1, C52.1, C53.1, C55.1, D2.1 (K), D3.2 (A), D5.2 (A), GND1.1, J1.6, L4.2, L5.2, R3.2, R6.2, R59.2, U1.4 (GND), U7.22 (TDI), U7.23 (TCK), U7.25 (TMS), U7.27 (TRST_L), U7.41 (ZC_IN), U7.55 (GND), U7.56 (GND), U7.69 (GND), U9.2, Y1.2, Y1.4; also elsewhere on the board
GPIO_1: R3.1, U7.61 (GPIO_1)
GPIO_2: R4.1, U7.62 (GPIO_2)
unnamed: C1.1, L1.1
unnamed: C1.2, C2.1, L4.1, R1.1
unnamed: C3.1, C32.2, D2.3 (K), L1.2, L5.1
unnamed: C9.2, C10.1, R8.1
unnamed: C29.2, R5.1, Y1.3
unnamed: C76.2, R25.2
unnamed: C4.2, C5.2, D2.2 (A), L3.1
unnamed: C11.2, C13.2, D4.1 (K), D5.1 (K), L9.1
unnamed: R9.2, R59.1
unnamed: C46.2, U7.49 (RSVD03)
unnamed: TP2.1, U7.33 (TXOUT_P)
unnamed: C17.2, U7.37 (XTAL_IN), Y1.1
unnamed: R5.2, U7.38 (XTAL_OUT)
RESET#: C44.1, J1.5, R10.1, RES1.1, U7.5 (RESET_L)
RF_protected: R1.2, R8.2, R25.1, U9.1
RXIN_N: C32.1, U7.29 (RXIN_N)
RXIN_P: C33.1, U7.30 (RXIN_P)
SERIAL_IO_0_INT: INT1.1, U7.20 (SERIAL_IO[0])
SERIAL_IO_1_CLK: CLK1.1, U7.19 (SERIAL_IO[1]); also elsewhere on the board
SERIAL_IO_2_CS: CS1.1, U7.16 (SERIAL_IO[2]); also elsewhere on the board
SERIAL_IO_3_MISO: MISO1.1, U7.15 (SERIAL_IO[3]); also elsewhere on the board
SERIAL_IO_4_MOSI: MOSI1.1, U7.14 (SERIAL_IO[4]); also elsewhere on the board
SPI_CLK: J1.4, U1.6 (SCK), U7.67 (SPI_CLK)
SPI_CS_L: J1.2, R7.1, U1.1 (~CS), U7.65 (SPI_CS_L)
SPI_DI: J1.1, U1.2 (SO/IO1), U7.3 (SPI_DI)
SPI_DO: J1.3, U1.5 (SI/IO0), U7.66 (SPI_D0)
TXOUT_N: C9.1, D3.1 (K), D4.2 (A), U7.31 (TXOUT_N)

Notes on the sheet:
2k5
With 3.3V TVS and input divider R25 we allow >12Vpp on CP line without saturation.
1N5819HW 2pcs
Atmel AT26DF161-SU 100 MHz 16-Mbits Not for new designs Atmel AT26DF161A-SU 70 MHz 16-Mbits Numonyx M25P80-VMW6TP 75 MHz 8-Mbits Numonyx M25P16-VMW6TP 75MHz 16-Mbits Macronix MX25L8005 70 MHz 8-Mbits Macronix MX25L1605 86 MHz 16-Mbits
GPIO_2 selects burst mode (3V3)
ARM926
3rd Order Butterworth Bandpass Lower Cutoff Freq. = 1.900 MHz; Upper Cutoff Freq. = 31.00 MHz https://rf-tools.com/lc-filter/
M25P16
GPIO_1 must be pulled down.
25q16

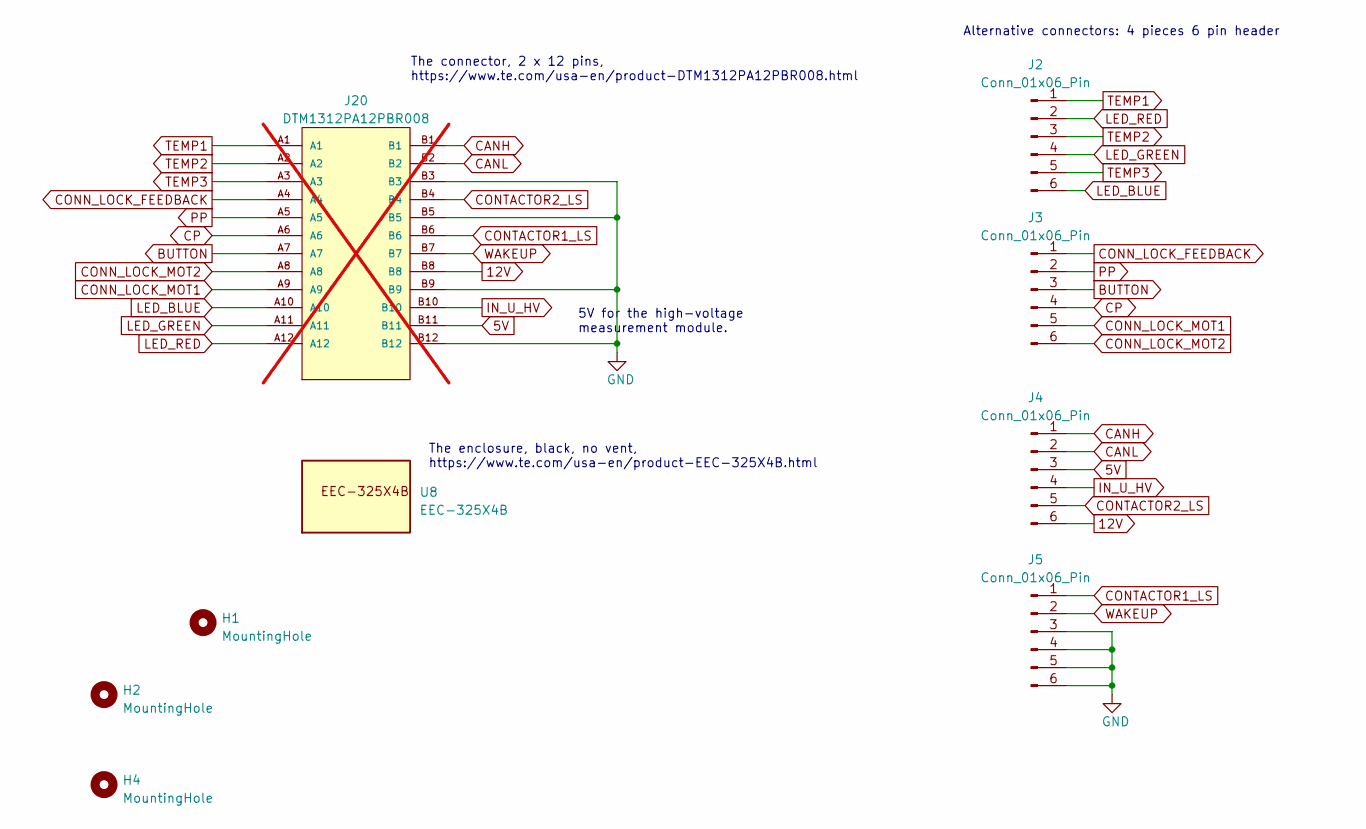
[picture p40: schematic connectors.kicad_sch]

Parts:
H1, H2, H4: MountingHole; MountingHole_3.5mm_Pad
J2, J3, J4, J5: Conn_01x06_Pin; PinHeader_1x06_P2.54mm_Vertical
J20: DTM1312PA12PBR008; TE_DTM1312PA12PBR008; PARTREV E; not fitted
U8: EEC-325X4B; TE_EEC-325X4B; PARTREV F

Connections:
5V: J4.3, J20.B11; also elsewhere on the board
12V: J4.6, J20.B8; also elsewhere on the board
BUTTON: J3.3, J20.A7; also elsewhere on the board
CANH: J4.1, J20.B1; also elsewhere on the board
CANL: J4.2, J20.B2; also elsewhere on the board
CONN_LOCK_FEEDBACK: J3.1, J20.A4; also elsewhere on the board
CONN_LOCK_MOT1: J3.5, J20.A9; also elsewhere on the board
CONN_LOCK_MOT2: J3.6, J20.A8; also elsewhere on the board
CONTACTOR1_LS: J5.1, J20.B6; also elsewhere on the board
CONTACTOR2_LS: J4.5, J20.B4; also elsewhere on the board
CP: J3.4, J20.A6; also elsewhere on the board
GND: J5.3, J5.4, J5.5, J5.6, J20.B3, J20.B5, J20.B9, J20.B12; also elsewhere on the board
IN_U_HV: J4.4, J20.B10; also elsewhere on the board
LED_BLUE: J2.6, J20.A10; also elsewhere on the board
LED_GREEN: J2.4, J20.A11; also elsewhere on the board
LED_RED: J2.2, J20.A12; also elsewhere on the board
PP: J3.2, J20.A5; also elsewhere on the board
TEMP1: J2.1, J20.A1; also elsewhere on the board
TEMP2: J2.3, J20.A2; also elsewhere on the board
TEMP3: J2.5, J20.A3; also elsewhere on the board
WAKEUP: J5.2, J20.B7; also elsewhere on the board

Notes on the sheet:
The enclosure, black, no vent, https://www.te.com/usa-en/product-EEC-325X4B.html
Alternative connectors: 4 pieces 6 pin header
5V for the high-voltage measurement module.
The connector, 2 x 12 pins, https://www.te.com/usa-en/product-DTM1312PA12PBR008.html

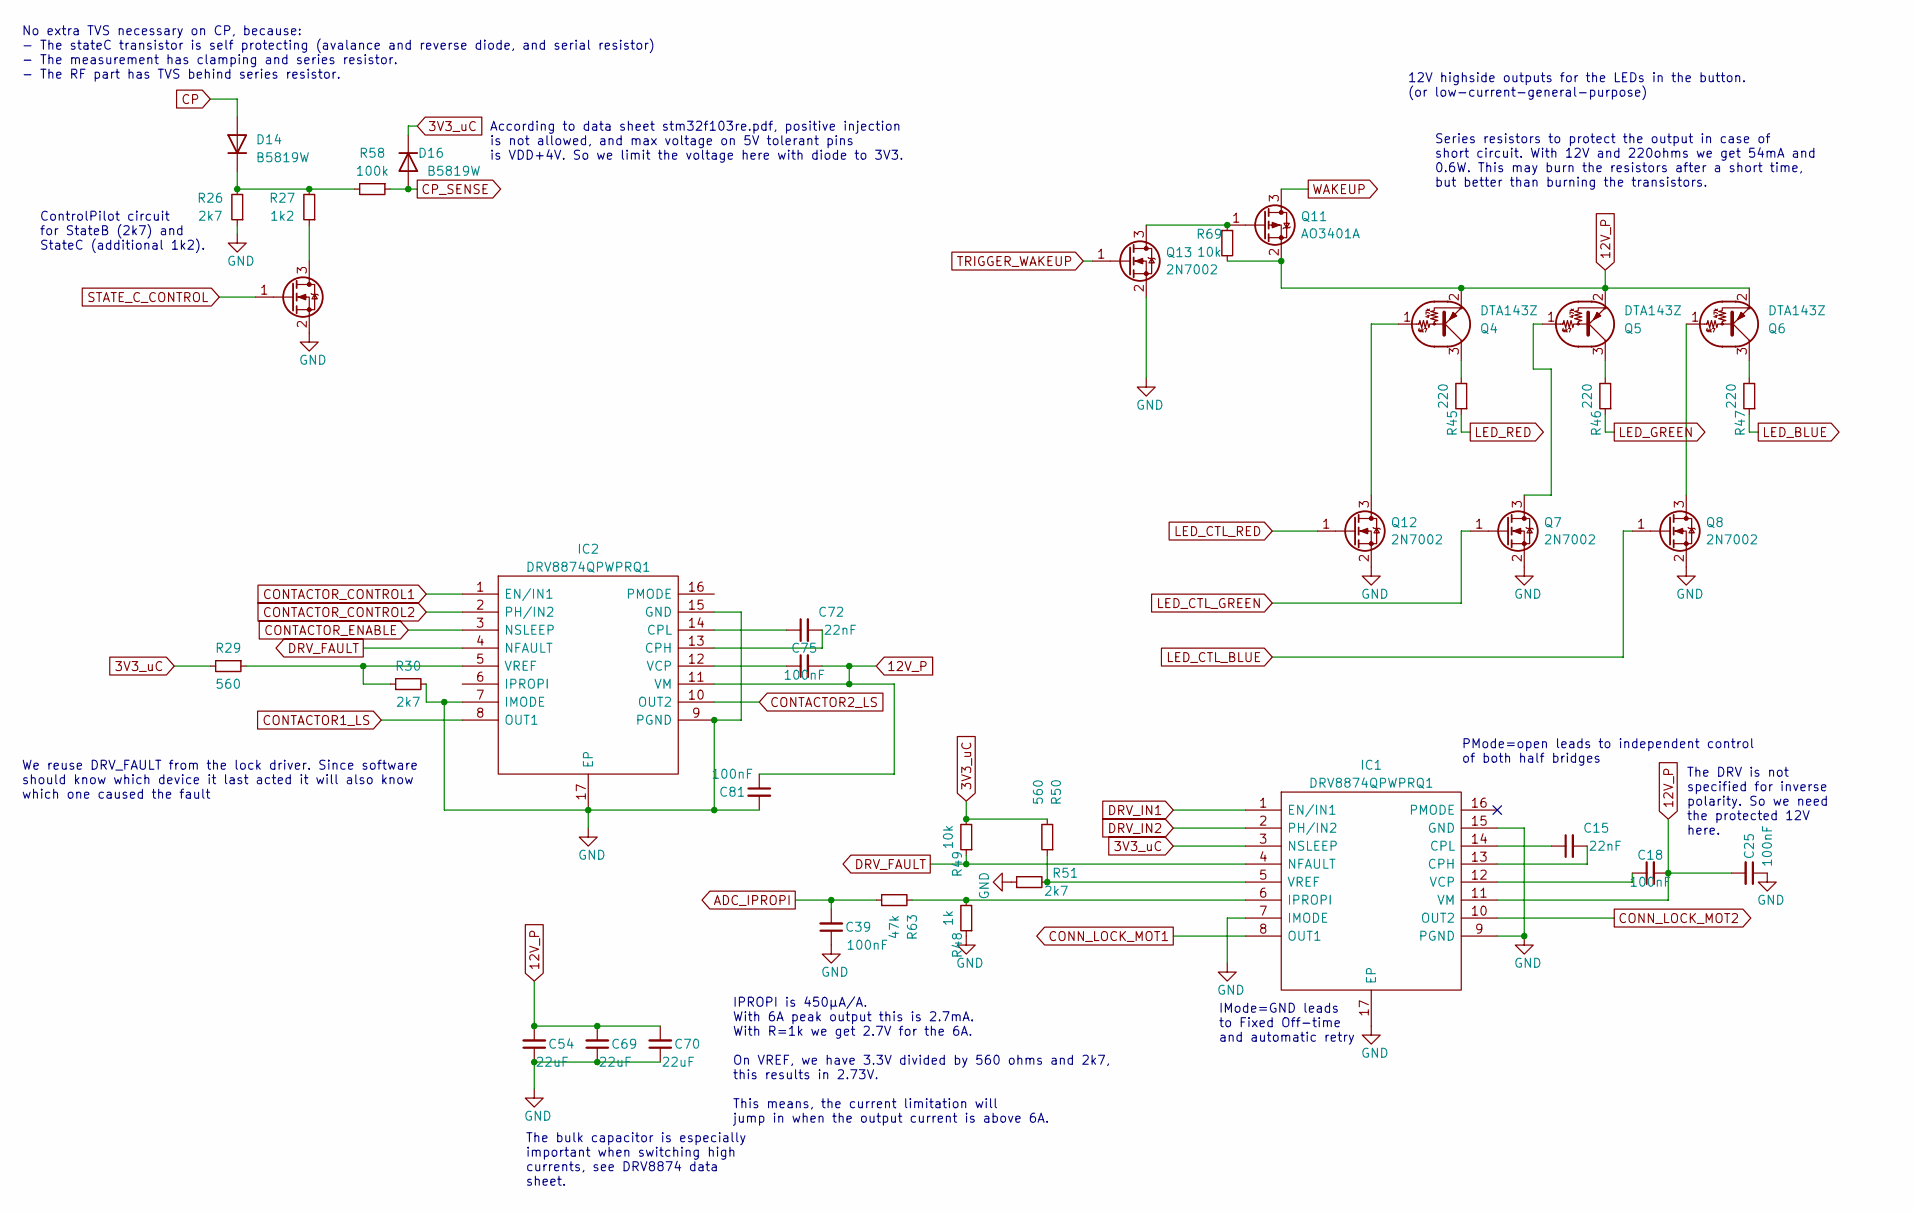
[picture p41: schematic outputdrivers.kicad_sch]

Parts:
C15, C72: 22nF; C_0805_2012Metric_Pad1.18x1.45mm_HandSolder; LCSC C1729
C18, C25, C39, C75, C81: 100nF; C_0805_2012Metric_Pad1.18x1.45mm_HandSolder; LCSC C49678
C54, C69, C70: 22uF; C_1210_3225Metric_Pad1.33x2.70mm_HandSolder; LCSC C12891
D14, D16: B5819W; D_SOD-123; LCSC C8598
IC1, IC2: DRV8874QPWPRQ1; SOP65P640X120-17N; Mouser Part Number 595-DRV8874QPWPRQ1
Q1, Q7, Q8, Q12, Q13: 2N7002; SOT-23; LCSC C8545
Q4, Q5, Q6: DTA143Z; SOT-23; LCSC C2910150
Q11: AO3401A; SOT-23; LCSC C15127
R26, R30, R51: 2k7; R_0805_2012Metric_Pad1.20x1.40mm_HandSolder; LCSC C17530
R27: 1k2; R_0805_2012Metric_Pad1.20x1.40mm_HandSolder; LCSC C17379
R29, R50: 560; R_0805_2012Metric_Pad1.20x1.40mm_HandSolder; LCSC C28636
R45, R46, R47: 220; R_0805_2012Metric_Pad1.20x1.40mm_HandSolder; LCSC C17557
R48: 1k; R_0805_2012Metric_Pad1.20x1.40mm_HandSolder; LCSC C17513
R49, R69: 10k; R_0805_2012Metric_Pad1.20x1.40mm_HandSolder; LCSC C17414
R58: 100k; R_0805_2012Metric_Pad1.20x1.40mm_HandSolder; LCSC C149504
R63: 47k; R_0805_2012Metric_Pad1.20x1.40mm_HandSolder; LCSC C17713

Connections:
3V3_uC: D16.1 (K), IC1.3 (NSLEEP), R29.2, R49.2, R50.2; also elsewhere on the board
12V_P: C18.2, C25.2, C54.2, C69.2, C70.2, C75.2, C81.1, IC1.11 (VM), IC2.11 (VM), Q4.2 (E), Q5.2 (E), Q6.2 (E), Q11.2 (S), R69.2; also elsewhere on the board
ADC_IPROPI: C39.2, R63.1; also elsewhere on the board
CONN_LOCK_MOT1: IC1.8 (OUT1); also elsewhere on the board
CONN_LOCK_MOT2: IC1.10 (OUT2); also elsewhere on the board
CONTACTOR1_LS: IC2.8 (OUT1); also elsewhere on the board
CONTACTOR2_LS: IC2.10 (OUT2); also elsewhere on the board
CONTACTOR_CONTROL1: IC2.1 (EN/IN1); also elsewhere on the board
CONTACTOR_CONTROL2: IC2.2 (PH/IN2); also elsewhere on the board
CONTACTOR_ENABLE: IC2.3 (NSLEEP); also elsewhere on the board
CP: D14.2 (A); also elsewhere on the board
CP_SENSE: D16.2 (A), R58.1; also elsewhere on the board
DRV_FAULT: IC1.4 (NFAULT), IC2.4 (NFAULT), R49.1; also elsewhere on the board
DRV_IN1: IC1.1 (EN/IN1); also elsewhere on the board
DRV_IN2: IC1.2 (PH/IN2); also elsewhere on the board
GND: C25.1, C39.1, C54.1, C69.1, C70.1, C81.2, IC1.7 (IMODE), IC1.9 (PGND), IC1.15 (GND), IC1.17 (EP), IC2.7 (IMODE), IC2.9 (PGND), IC2.15 (GND), IC2.17 (EP), Q1.2 (S), Q7.2 (S), Q8.2 (S), Q12.2 (S), Q13.2 (S), R26.1, R30.2, R48.1, R51.1; also elsewhere on the board
LED_BLUE: R47.1; also elsewhere on the board
LED_CTL_BLUE: Q8.1 (G); also elsewhere on the board
LED_CTL_GREEN: Q7.1 (G); also elsewhere on the board
LED_CTL_RED: Q12.1 (G); also elsewhere on the board
LED_GREEN: R46.1; also elsewhere on the board
LED_RED: R45.1; also elsewhere on the board
unnamed: D14.1 (K), R26.2, R27.2, R58.2
unnamed: C15.2, IC1.13 (CPH)
unnamed: C15.1, IC1.14 (CPL)
unnamed: IC1.6 (IPROPI), R48.2, R63.2
unnamed: C18.1, IC1.12 (VCP)
unnamed: IC1.5 (VREF), R50.1, R51.2
unnamed: C72.2, IC2.13 (CPH)
unnamed: C72.1, IC2.14 (CPL)
unnamed: C75.1, IC2.12 (VCP)
unnamed: IC2.5 (VREF), R29.1, R30.1
unnamed: Q1.3 (D), R27.1
unnamed: Q4.3 (C), R45.2
unnamed: Q5.1 (B), Q7.3 (D)
unnamed: Q5.3 (C), R46.2
unnamed: Q6.1 (B), Q8.3 (D)
unnamed: Q6.3 (C), R47.2
unnamed: Q11.1 (G), Q13.3 (D), R69.1
unnamed: Q4.1 (B), Q12.3 (D)
STATE_C_CONTROL: Q1.1 (G); also elsewhere on the board
TRIGGER_WAKEUP: Q13.1 (G); also elsewhere on the board
WAKEUP: Q11.3 (D); also elsewhere on the board

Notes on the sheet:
IMode=GND leads to Fixed Off-time and automatic retry
IPROPI is 450µA/A. With 6A peak output this is 2.7mA. With R=1k we get 2.7V for the 6A. On VREF, we have 3.3V divided by 560 ohms and 2k7, this results in 2.73V. This means, the current limitation will jump in when the output current is above 6A.
According to data sheet stm32f103re.pdf, positive injection is not allowed, and max voltage on 5V tolerant pins is VDD+4V. So we limit the voltage here with diode to 3V3.
No extra TVS necessary on CP, because: - The stateC transistor is self protecting (avalance and reverse diode, and serial resistor) - The measurement has clamping and series resistor. - The RF part has TVS behind series resistor.
12V highside outputs for the LEDs in the button. (or low-current-general-purpose)
ControlPilot circuit for StateB (2k7) and StateC (additional 1k2).
We reuse DRV_FAULT from the lock driver. Since software should know which device it last acted it will also know which one caused the fault
PMode=open leads to independent control of both half bridges
The bulk capacitor is especially important when switching high currents, see DRV8874 data sheet.
Series resistors to protect the output in case of short circuit. With 12V and 220ohms we get 54mA and 0.6W. This may burn the resistors after a short time, but better than burning the transistors.
The DRV is not specified for inverse polarity. So we need the protected 12V here.

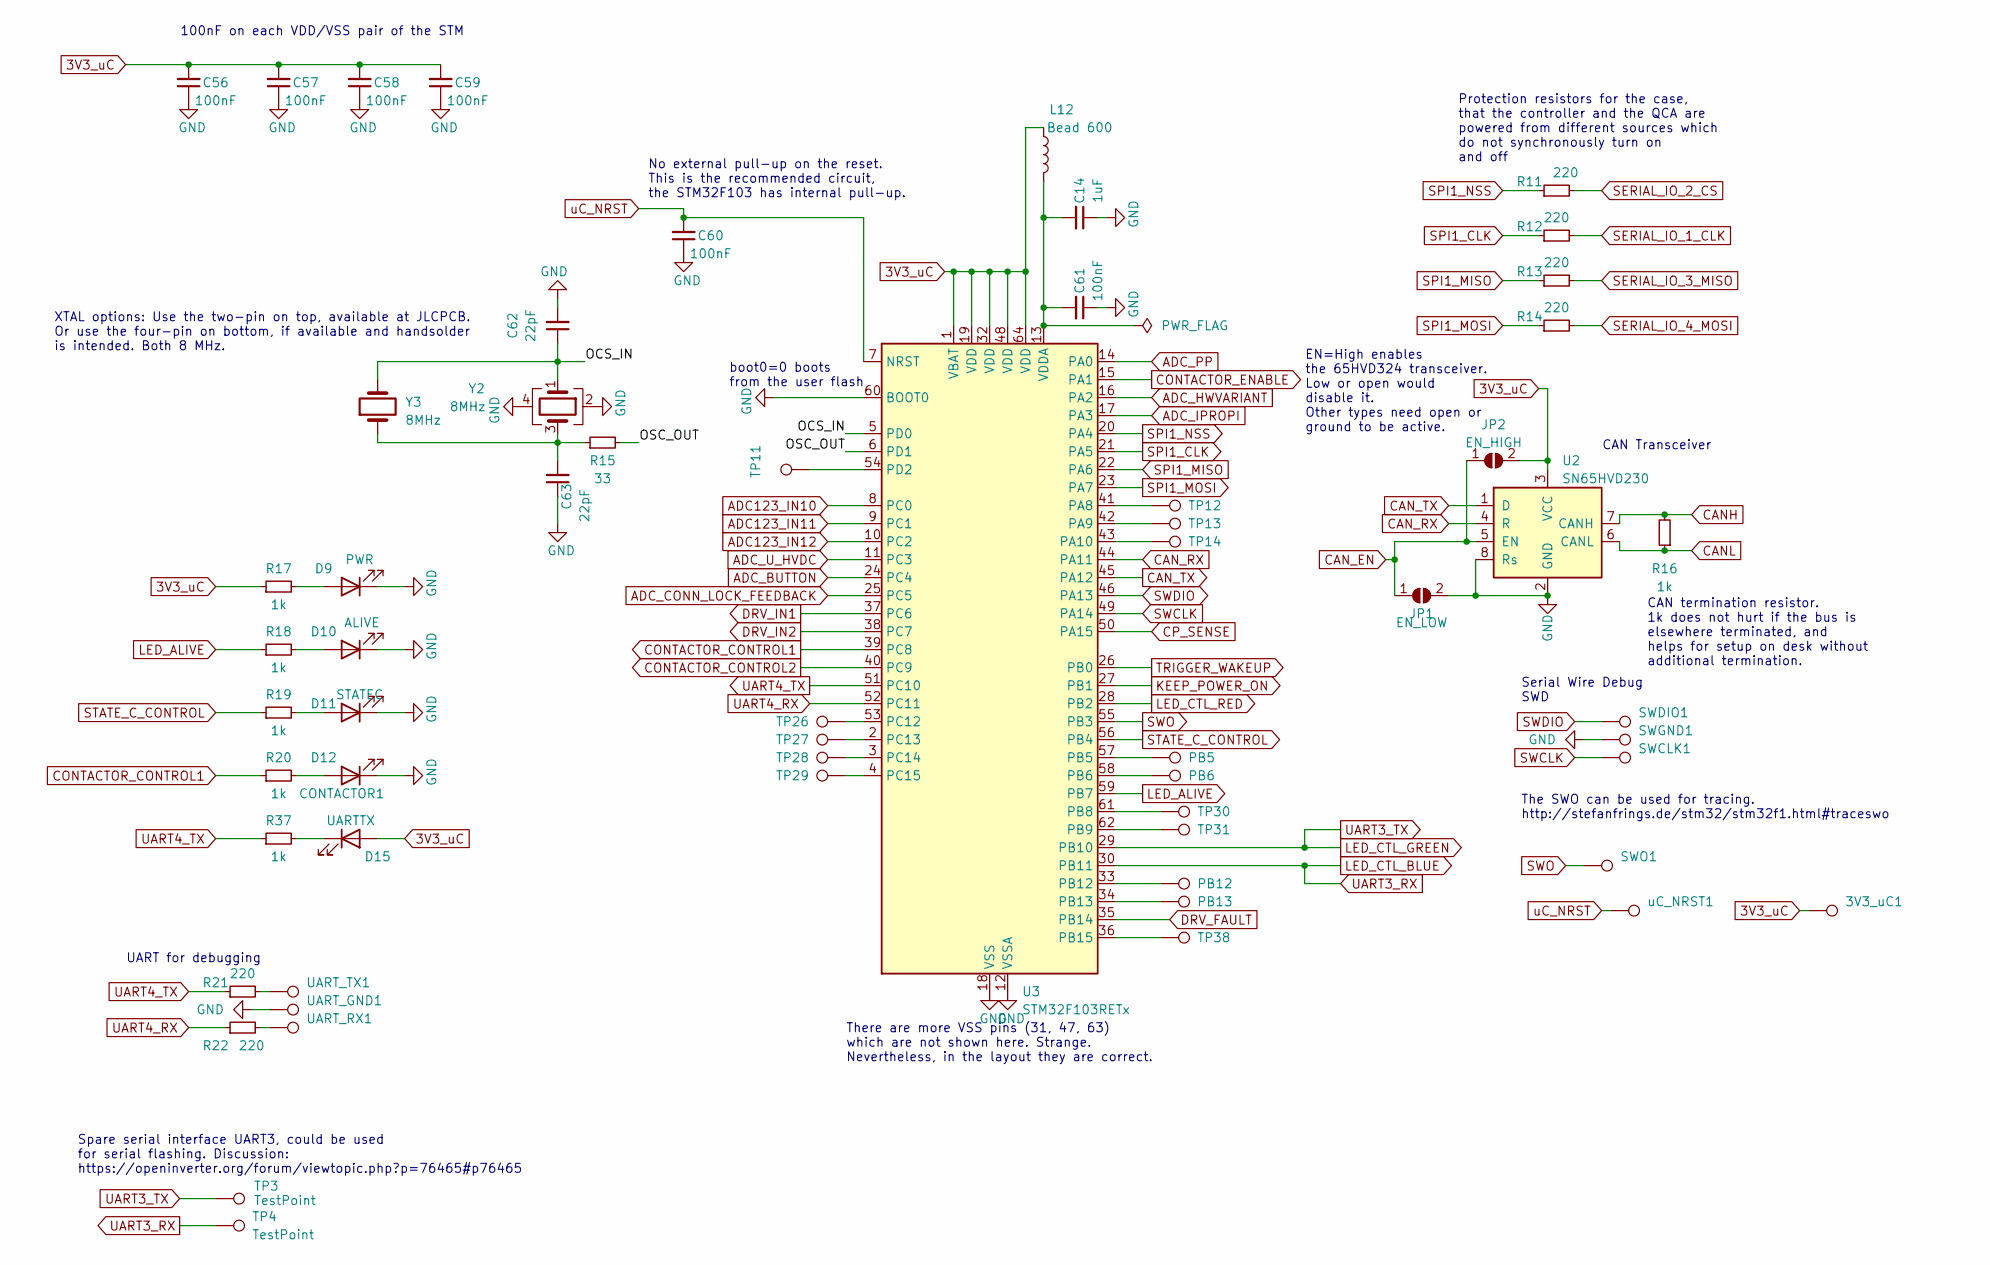
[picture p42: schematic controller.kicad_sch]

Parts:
3V3_uC1: TestPoint_Special_THTPad_D1.9mm_Drill1mm
C14: 1uF; C_0805_2012Metric_Pad1.18x1.45mm_HandSolder; LCSC C28323
C56, C57, C58, C59, C60, C61: 100nF; C_0805_2012Metric_Pad1.18x1.45mm_HandSolder; LCSC C49678
C62, C63: 22pF; C_0805_2012Metric_Pad1.18x1.45mm_HandSolder; LCSC C1804
D9: PWR; LED_0805_2012Metric_Pad1.15x1.40mm_HandSolder; LCSC C2296
D10: ALIVE; LED_0805_2012Metric_Pad1.15x1.40mm_HandSolder; LCSC C2296
D11: STATEC; LED_0805_2012Metric_Pad1.15x1.40mm_HandSolder; LCSC C2296
D12: CONTACTOR1; LED_0805_2012Metric_Pad1.15x1.40mm_HandSolder; LCSC C2296
D15: UARTTX; LED_0805_2012Metric_Pad1.15x1.40mm_HandSolder; LCSC C2296
JP1: EN_LOW; SolderJumper-2_P1.3mm_Open_TrianglePad1.0x1.5mm
JP2: EN_HIGH; SolderJumper-2_P1.3mm_Open_TrianglePad1.0x1.5mm
L12: Bead 600; L_0805_2012Metric_Pad1.15x1.40mm_HandSolder; LCSC C1017
PB5, PB6, PB12, PB13: TestPoint_THTPad_D1.0mm_Drill0.5mm
R11, R12, R13, R14, R21, R22: 220; R_0805_2012Metric_Pad1.20x1.40mm_HandSolder; LCSC C17557
R15: 33; R_0805_2012Metric_Pad1.20x1.40mm_HandSolder; LCSC C17634
R16, R17, R18, R19, R20, R37: 1k; R_0805_2012Metric_Pad1.20x1.40mm_HandSolder; LCSC C17513
SWCLK1: TestPoint_Special_THTPad_D1.9mm_Drill1mm
SWDIO1: TestPoint_Special_THTPad_D1.9mm_Drill1mm
SWGND1: TestPoint_Special_THTPad_D1.9mm_Drill1mm
SWO1: TestPoint_Special_THTPad_D1.9mm_Drill1mm
TP3, TP4: TestPoint; TestPoint_Special_THTPad_D1.9mm_Drill1mm
TP11, TP12, TP13, TP14, TP26, TP27, TP28, TP29, TP30, TP31, TP38: TestPoint_THTPad_D1.0mm_Drill0.5mm
U2: SN65HVD230; SOIC-8_3.9x4.9mm_P1.27mm; LCSC C12084
U3: STM32F103RETx; LQFP-64_10x10mm_P0.5mm; LCSC C8322
UART_GND1: TestPoint_Special_THTPad_D1.9mm_Drill1mm
UART_RX1: TestPoint_Special_THTPad_D1.9mm_Drill1mm
UART_TX1: TestPoint_Special_THTPad_D1.9mm_Drill1mm
Y2: 8MHz; Crystal_SMD_TXC_7M-4Pin_3.2x2.5mm; LCSC none
Y3: 8MHz; Crystal_SMD_5032-2Pin_5.0x3.2mm; LCSC C115962
uC_NRST1: TestPoint_Special_THTPad_D1.9mm_Drill1mm

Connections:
3V3_uC: 3V3_uC1.1, C56.2, C57.2, C58.2, C59.2, D15.2 (A), JP2.2 (B), L12.2, R17.1, U2.3 (VCC), U3.1 (VBAT), U3.19 (VDD), U3.32 (VDD), U3.48 (VDD), U3.64 (VDD); also elsewhere on the board
/controller/OCS_IN: C62.1, U3.5 (PD0), Y2.1, Y3.2
/controller/OSC_OUT: R15.2, U3.6 (PD1)
ADC123_IN10: U3.8 (PC0); also elsewhere on the board
ADC123_IN11: U3.9 (PC1); also elsewhere on the board
ADC123_IN12: U3.10 (PC2); also elsewhere on the board
ADC_BUTTON: U3.24 (PC4); also elsewhere on the board
ADC_CONN_LOCK_FEEDBACK: U3.25 (PC5); also elsewhere on the board
ADC_HWVARIANT: U3.16 (PA2); also elsewhere on the board
ADC_IPROPI: U3.17 (PA3); also elsewhere on the board
ADC_PP: U3.14 (PA0); also elsewhere on the board
ADC_U_HVDC: U3.11 (PC3); also elsewhere on the board
CANH: R16.2, U2.7 (CANH); also elsewhere on the board
CANL: R16.1, U2.6 (CANL); also elsewhere on the board
CAN_EN: JP1.1 (A), JP2.1 (A), U2.5 (EN)
CAN_RX: U2.4 (R), U3.44 (PA11)
CAN_TX: U2.1 (D), U3.45 (PA12)
CONTACTOR_CONTROL1: R20.1, U3.39 (PC8); also elsewhere on the board
CONTACTOR_CONTROL2: U3.40 (PC9); also elsewhere on the board
CONTACTOR_ENABLE: U3.15 (PA1); also elsewhere on the board
CP_SENSE: U3.50 (PA15); also elsewhere on the board
DRV_FAULT: U3.35 (PB14); also elsewhere on the board
DRV_IN1: U3.37 (PC6); also elsewhere on the board
DRV_IN2: U3.38 (PC7); also elsewhere on the board
GND: C14.1, C56.1, C57.1, C58.1, C59.1, C60.1, C61.1, C62.2, C63.1, D9.1 (K), D10.1 (K), D11.1 (K), D12.1 (K), JP1.2 (B), SWGND1.1, U2.2 (GND), U2.8 (Rs), U3.12 (VSSA), U3.18 (VSS), U3.31 (VSS), U3.47 (VSS), U3.60 (BOOT0), U3.63 (VSS), UART_GND1.1, Y2.2, Y2.4; also elsewhere on the board
KEEP_POWER_ON: U3.27 (PB1); also elsewhere on the board
LED_ALIVE: R18.1, U3.59 (PB7)
LED_CTL_BLUE: TP4.1, U3.30 (PB11); also elsewhere on the board
LED_CTL_GREEN: TP3.1, U3.29 (PB10); also elsewhere on the board
LED_CTL_RED: U3.28 (PB2); also elsewhere on the board
unnamed: C63.2, R15.1, Y2.3, Y3.1
unnamed: D9.2 (A), R17.2
unnamed: D10.2 (A), R18.2
unnamed: D11.2 (A), R19.2
unnamed: D12.2 (A), R20.2
unnamed: D15.1 (K), R37.2
unnamed: R21.2, UART_TX1.1
unnamed: R22.2, UART_RX1.1
unnamed: TP12.1, U3.41 (PA8)
unnamed: TP13.1, U3.42 (PA9)
unnamed: TP14.1, U3.43 (PA10)
unnamed: PB5.1, U3.57 (PB5)
unnamed: PB6.1, U3.58 (PB6)
unnamed: TP30.1, U3.61 (PB8)
unnamed: TP31.1, U3.62 (PB9)
unnamed: PB12.1, U3.33 (PB12)
unnamed: PB13.1, U3.34 (PB13)
unnamed: TP38.1, U3.36 (PB15)
unnamed: TP26.1, U3.53 (PC12)
unnamed: TP27.1, U3.2 (PC13)
unnamed: TP28.1, U3.3 (PC14)
unnamed: TP29.1, U3.4 (PC15)
unnamed: TP11.1, U3.54 (PD2)
unnamed: C14.2, C61.2, L12.1, U3.13 (VDDA)
SERIAL_IO_1_CLK: R12.2; also elsewhere on the board
SERIAL_IO_2_CS: R11.2; also elsewhere on the board
SERIAL_IO_3_MISO: R13.2; also elsewhere on the board
SERIAL_IO_4_MOSI: R14.2; also elsewhere on the board
SPI1_CLK: R12.1, U3.21 (PA5)
SPI1_MISO: R13.1, U3.22 (PA6)
SPI1_MOSI: R14.1, U3.23 (PA7)
SPI1_NSS: R11.1, U3.20 (PA4)
STATE_C_CONTROL: R19.1, U3.56 (PB4); also elsewhere on the board
SWCLK: SWCLK1.1, U3.49 (PA14)
SWDIO: SWDIO1.1, U3.46 (PA13)
SWO: SWO1.1, U3.55 (PB3)
TRIGGER_WAKEUP: U3.26 (PB0); also elsewhere on the board
UART4_RX: R22.1, U3.52 (PC11)
UART4_TX: R21.1, R37.1, U3.51 (PC10)
uC_NRST: C60.2, U3.7 (NRST), uC_NRST1.1

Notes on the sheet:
CAN Transceiver
boot0=0 boots from the user flash
Spare serial interface UART3, could be used for serial flashing. Discussion: https://openinverter.org/forum/viewtopic.php?p=76465#p76465
The SWO can be used for tracing. http://stefanfrings.de/stm32/stm32f1.html#traceswo
UART for debugging
100nF on each VDD/VSS pair of the STM
Protection resistors for the case, that the controller and the QCA are powered from different sources which do not synchronously turn on and off
There are more VSS pins (31, 47, 63) which are not shown here. Strange. Nevertheless, in the layout they are correct.
EN=High enables the 65HVD324 transceiver. Low or open would disable it. Other types need open or ground to be active.
Serial Wire Debug SWD
CAN termination resistor. 1k does not hurt if the bus is elsewhere terminated, and helps for setup on desk without additional termination.
XTAL options: Use the two-pin on top, available at JLCPCB. Or use the four-pin on bottom, if available and handsolder is intended. Both 8 MHz.
No external pull-up on the reset. This is the recommended circuit, the STM32F103 has internal pull-up.

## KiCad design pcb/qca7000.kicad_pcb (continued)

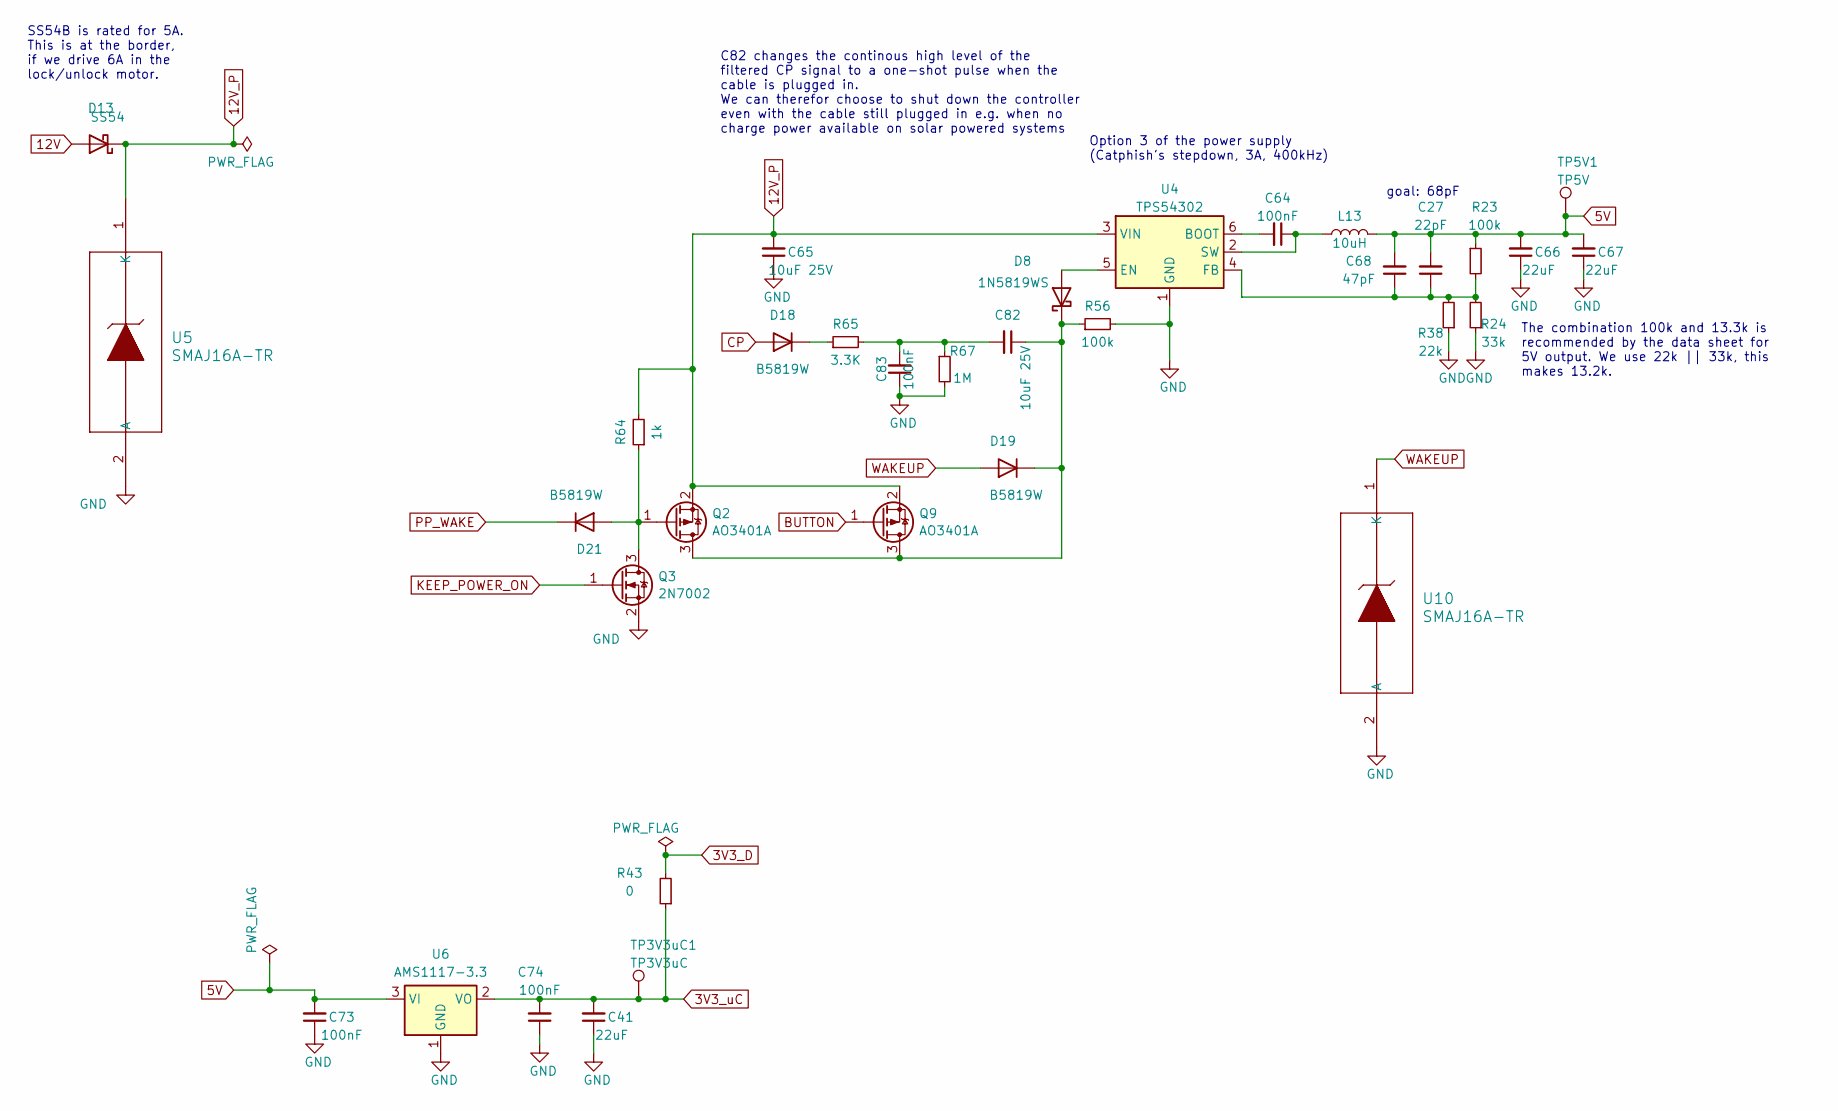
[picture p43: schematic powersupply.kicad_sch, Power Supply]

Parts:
C27: 22pF; C_0805_2012Metric_Pad1.18x1.45mm_HandSolder; LCSC C1804
C41, C66, C67: 22uF; C_1210_3225Metric_Pad1.33x2.70mm_HandSolder; LCSC C12891
C64, C73, C74, C83: 100nF; C_0805_2012Metric_Pad1.18x1.45mm_HandSolder; LCSC C49678
C65, C82: 10uF 25V; C_0805_2012Metric_Pad1.18x1.45mm_HandSolder; LCSC C15850
C68: 47pF; C_0805_2012Metric_Pad1.18x1.45mm_HandSolder; LCSC C14857
D8: 1N5819WS; D_SOD-323; LCSC C191023
D13: SS54; D_SMB_Handsoldering; LCSC C22452
D18, D19, D21: B5819W; D_SOD-123; LCSC C8598
L13: 10uH; L_6.3x6.3_H3; LCSC C408412
Q2, Q9: AO3401A; SOT-23; LCSC C15127
Q3: 2N7002; SOT-23; LCSC C8545
R23, R56: 100k; R_0805_2012Metric_Pad1.20x1.40mm_HandSolder; LCSC C149504
R24: 33k; R_0805_2012Metric_Pad1.20x1.40mm_HandSolder; LCSC C17633
R38: 22k; R_0805_2012Metric_Pad1.20x1.40mm_HandSolder; LCSC C17560
R43: 0; R_1206_3216Metric_Pad1.30x1.75mm_HandSolder; LCSC C17888
R64: 1k; R_0805_2012Metric_Pad1.20x1.40mm_HandSolder; LCSC C17513
R65: 3.3K; R_0805_2012Metric_Pad1.20x1.40mm_HandSolder; LCSC C26010
R67: 1M; R_0805_2012Metric_Pad1.20x1.40mm_HandSolder; LCSC C22935
TP3V3uC1: TP3V3uC; TestPoint_THTPad_D1.0mm_Drill0.5mm
TP5V1: TP5V; TestPoint_THTPad_D1.0mm_Drill0.5mm
U4: TPS54302; SOT-23-6; LCSC C311983
U5, U10: SMAJ16A-TR; SMA_UNI_STM; LCSC C908770
U6: AMS1117-3.3; SOT-223-3_TabPin2; LCSC C6186

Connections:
3V3_D: R43.2; also elsewhere on the board
3V3_uC: C41.2, C74.2, R43.1, TP3V3uC1.1, U6.2 (VO); also elsewhere on the board
5V: C27.2, C66.2, C67.2, C68.2, C73.2, L13.2, R23.1, TP5V1.1, U6.3 (VI); also elsewhere on the board
12V: D13.2 (A); also elsewhere on the board
12V_P: C65.2, D13.1 (K), Q2.2 (S), Q9.2 (S), R64.2, U4.3 (VIN), U5.1 (K); also elsewhere on the board
BUTTON: Q9.1 (G); also elsewhere on the board
CP: D18.2 (A); also elsewhere on the board
GND: C41.1, C65.1, C66.1, C67.1, C73.1, C74.1, C83.1, Q3.2 (S), R24.1, R38.1, R56.2, R67.2, U4.1 (GND), U5.2 (A), U6.1 (GND), U10.2 (A); also elsewhere on the board
KEEP_POWER_ON: Q3.1 (G); also elsewhere on the board
unnamed: C82.2, C83.2, R65.2, R67.1
unnamed: D8.2 (A), U4.5 (EN)
unnamed: D18.1 (K), R65.1
unnamed: C82.1, D8.1 (K), D19.1 (K), Q2.3 (D), Q9.3 (D), R56.1
unnamed: D21.2 (A), Q2.1 (G), Q3.3 (D), R64.1
unnamed: C64.2, U4.6 (BOOT)
unnamed: C27.1, C68.1, R23.2, R24.2, R38.2, U4.4 (FB)
unnamed: C64.1, L13.1, U4.2 (SW)
PP_WAKE: D21.1 (K); also elsewhere on the board
WAKEUP: D19.2 (A), U10.1 (K); also elsewhere on the board

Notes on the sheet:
goal: 68pF
The combination 100k and 13.3k is recommended by the data sheet for 5V output. We use 22k || 33k, this makes 13.2k.
Option 3 of the power supply (Catphish's stepdown, 3A, 400kHz)
SS54B is rated for 5A. This is at the border, if we drive 6A in the lock/unlock motor.
C82 changes the continous high level of the filtered CP signal to a one-shot pulse when the cable is plugged in. We can therefor choose to shut down the controller even with the cable still plugged in e.g. when no charge power available on solar powered systems

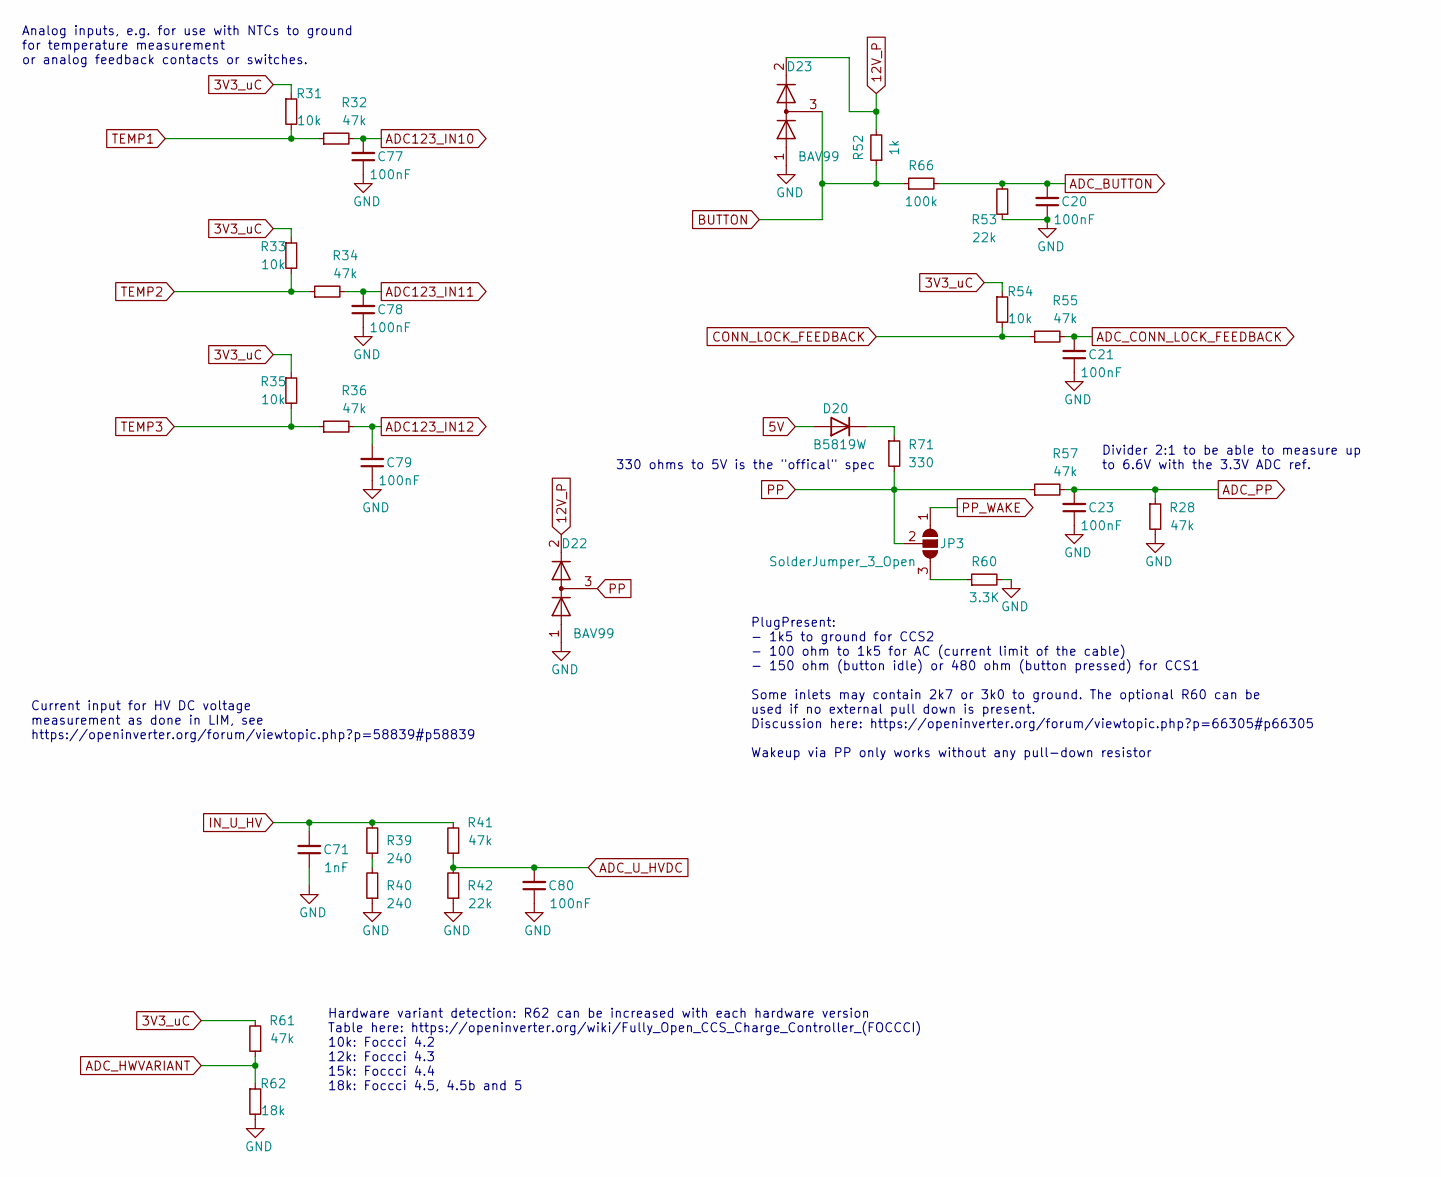
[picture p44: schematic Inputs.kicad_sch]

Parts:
C20, C21, C23, C77, C78, C79, C80: 100nF; C_0805_2012Metric_Pad1.18x1.45mm_HandSolder; LCSC C49678
C71: 1nF; C_0805_2012Metric_Pad1.18x1.45mm_HandSolder; LCSC C46653
D20: B5819W; D_SOD-123; LCSC C8598
D22, D23: BAV99; SOT-23; LCSC C2500
JP3: SolderJumper_3_Open; SolderJumper-3_P1.3mm_Open_RoundedPad1.0x1.5mm
R28, R32, R34, R36, R41, R55, R57, R61: 47k; R_0805_2012Metric_Pad1.20x1.40mm_HandSolder; LCSC C17713
R31, R33, R35, R54: 10k; R_0805_2012Metric_Pad1.20x1.40mm_HandSolder; LCSC C17414
R39, R40: 240; R_0805_2012Metric_Pad1.20x1.40mm_HandSolder; LCSC C17572
R42, R53: 22k; R_0805_2012Metric_Pad1.20x1.40mm_HandSolder; LCSC C17560
R52: 1k; R_0805_2012Metric_Pad1.20x1.40mm_HandSolder; LCSC C17513
R60: 3.3K; R_0805_2012Metric_Pad1.20x1.40mm_HandSolder; LCSC C26010
R62: 18k; R_0805_2012Metric_Pad1.20x1.40mm_HandSolder; LCSC C25810
R66: 100k; R_0805_2012Metric_Pad1.20x1.40mm_HandSolder; LCSC C149504
R71: 330; R_0805_2012Metric_Pad1.20x1.40mm_HandSolder; LCSC C23138

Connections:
3V3_uC: R31.1, R33.1, R35.1, R54.1, R61.2; also elsewhere on the board
5V: D20.2 (A); also elsewhere on the board
12V_P: D22.2 (A), D23.2 (A), R52.2; also elsewhere on the board
ADC123_IN10: C77.2, R32.2; also elsewhere on the board
ADC123_IN11: C78.2, R34.2; also elsewhere on the board
ADC123_IN12: C79.2, R36.2; also elsewhere on the board
ADC_BUTTON: C20.2, R53.2, R66.2; also elsewhere on the board
ADC_CONN_LOCK_FEEDBACK: C21.2, R55.2; also elsewhere on the board
ADC_HWVARIANT: R61.1, R62.1; also elsewhere on the board
ADC_PP: C23.2, R28.1, R57.2; also elsewhere on the board
ADC_U_HVDC: C80.2, R41.1, R42.2; also elsewhere on the board
BUTTON: D23.3 (K), R52.1, R66.1; also elsewhere on the board
CONN_LOCK_FEEDBACK: R54.2, R55.1; also elsewhere on the board
GND: C20.1, C21.1, C23.1, C71.1, C77.1, C78.1, C79.1, C80.1, D22.1 (K), D23.1 (K), R28.2, R40.1, R42.1, R53.1, R60.2, R62.2; also elsewhere on the board
IN_U_HV: C71.2, R39.2, R41.2; also elsewhere on the board
unnamed: D20.1 (K), R71.1
unnamed: JP3.3 (B), R60.1
unnamed: R39.1, R40.2
PP: D22.3 (K), JP3.2 (C), R57.1, R71.2; also elsewhere on the board
PP_WAKE: JP3.1 (A); also elsewhere on the board
TEMP1: R31.2, R32.1; also elsewhere on the board
TEMP2: R33.2, R34.1; also elsewhere on the board
TEMP3: R35.2, R36.1; also elsewhere on the board

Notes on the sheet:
Divider 2:1 to be able to measure up to 6.6V with the 3.3V ADC ref.
Hardware variant detection: R62 can be increased with each hardware version Table here: https://openinverter.org/wiki/Fully_Open_CCS_Charge_Controller_(FOCCCI) 10k: Foccci 4.2 12k: Foccci 4.3 15k: Foccci 4.4 18k: Foccci 4.5, 4.5b and 5
Current input for HV DC voltage measurement as done in LIM, see https://openinverter.org/forum/viewtopic.php?p=58839#p58839
330 ohms to 5V is the "offical" spec
Analog inputs, e.g. for use with NTCs to ground for temperature measurement or analog feedback contacts or switches.
PlugPresent: - 1k5 to ground for CCS2 - 100 ohm to 1k5 for AC (current limit of the cable) - 150 ohm (button idle) or 480 ohm (button pressed) for CCS1 Some inlets may contain 2k7 or 3k0 to ground. The optional R60 can be used if no external pull down is present. Discussion here: https://openinvert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

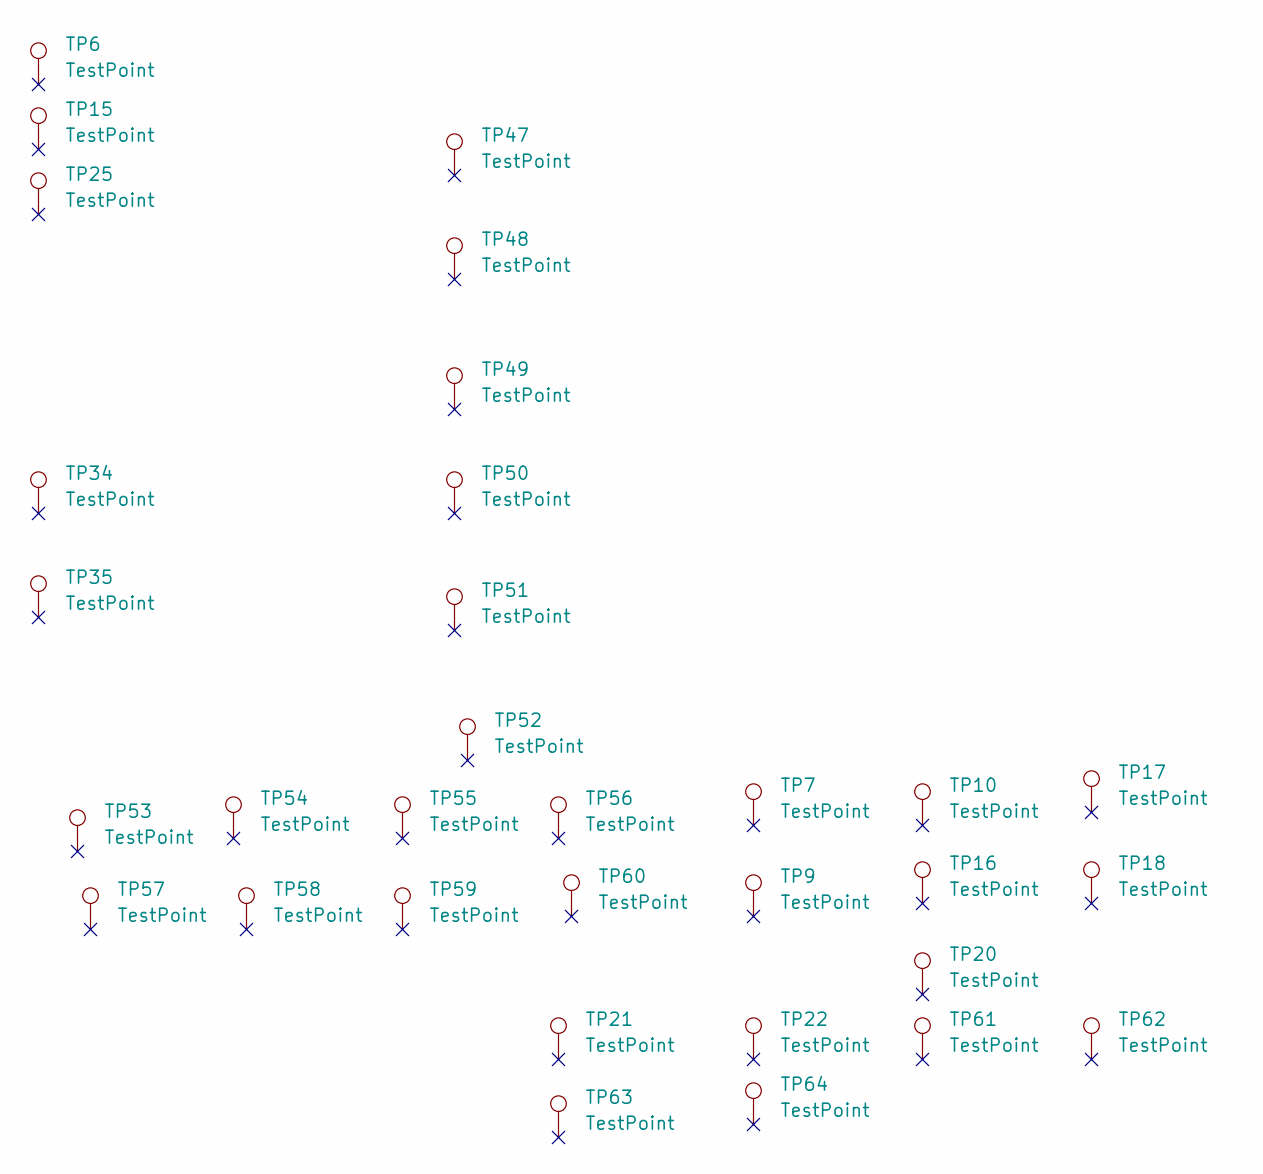
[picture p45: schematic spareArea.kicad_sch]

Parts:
TP6, TP7, TP9, TP10, TP15, TP16, TP17, TP18, TP20, TP21, TP22, TP25, TP34, TP35, TP47, TP48, TP49, TP50, TP51, TP52, TP53, TP54, TP55, TP56, TP57, TP58, TP59, TP60, TP61, TP62, TP63, TP64: TestPoint; TestPoint_Special_THTPad_D1.9mm_Drill1mm

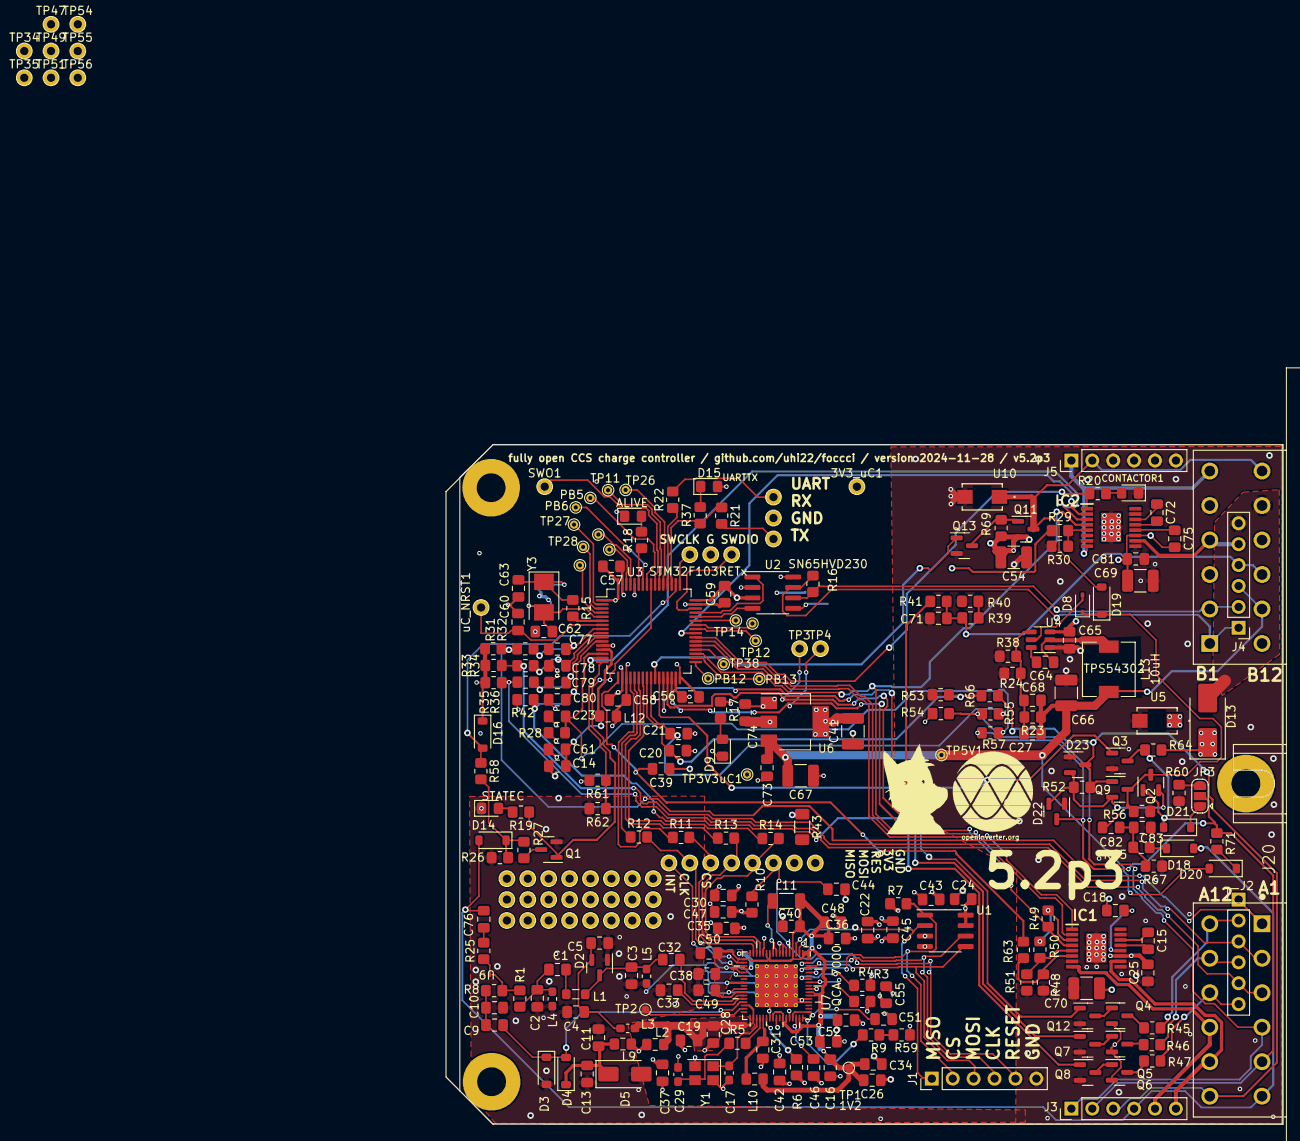
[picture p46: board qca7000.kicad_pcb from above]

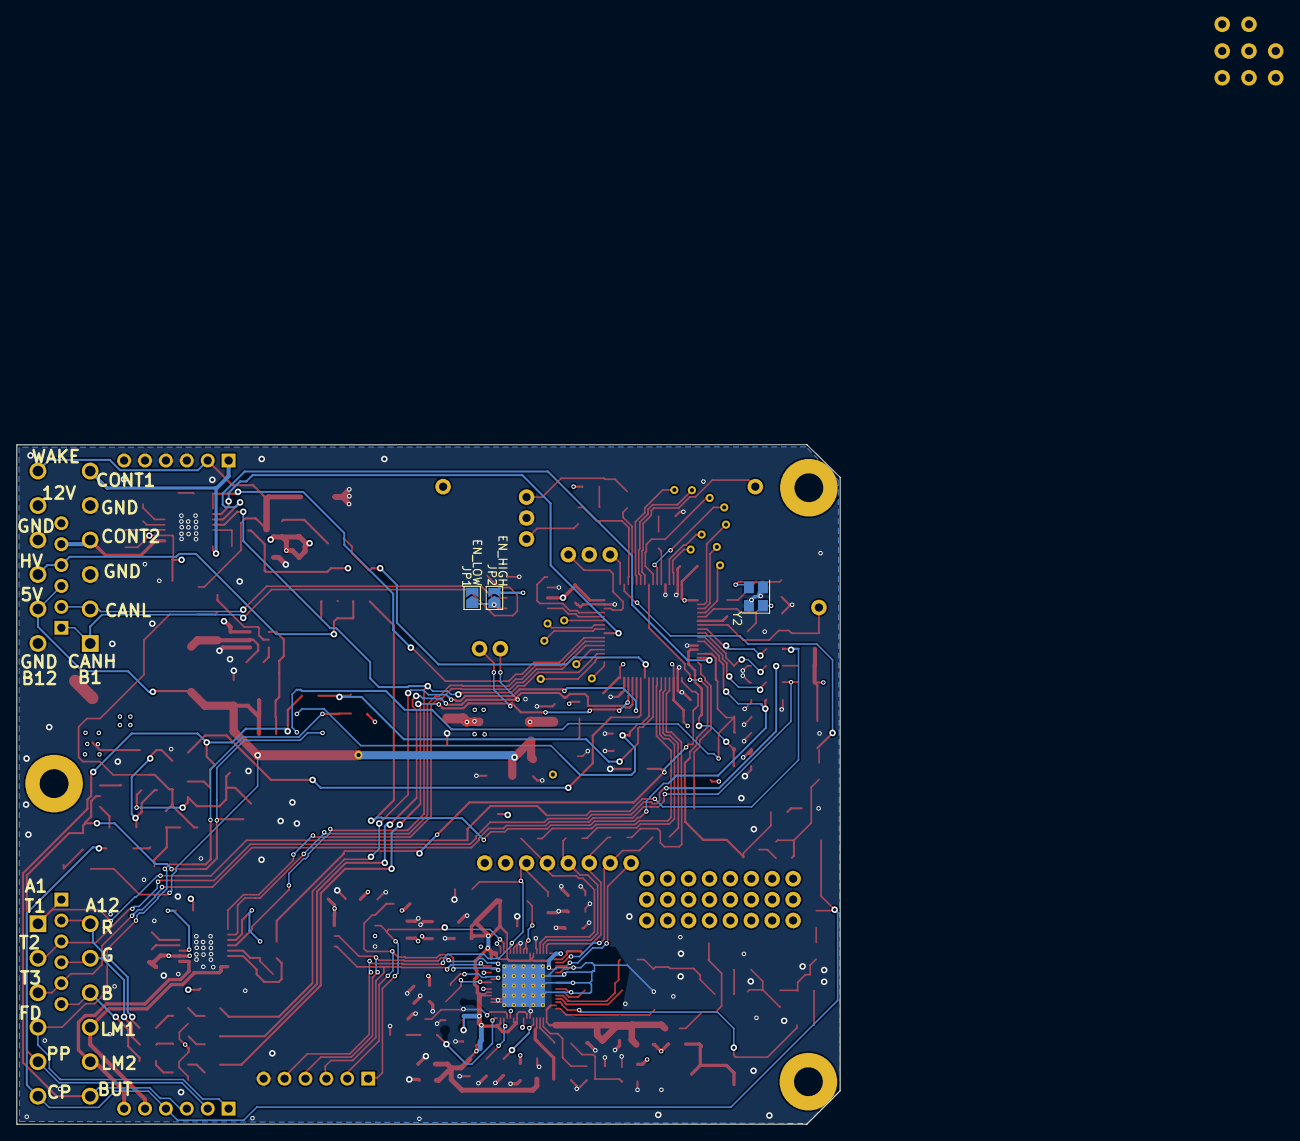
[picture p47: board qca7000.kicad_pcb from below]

Board: 4 copper layers, 100.0 x 82.6 mm, 285 parts (3 on the bottom side), 152 nets.

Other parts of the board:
U$2: OI_LOGO

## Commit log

2023-06-20 schematic improvements and board draft
    [qca7000.kicad_pcb, qca7000.kicad_sch]
2023-06-20 board: more width for supply, fill, shrink
    [qca7000.kicad_pcb, qca7000.kicad_sch]
2023-06-20 v1 ready for production
    [qca7000-B_Cu.gbr, qca7000-B_Mask.gbr, qca7000-B_Paste.gbr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]
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2023-07-06 started adding power supply
    [qca7000.kicad_pcb, qca7000.kicad_sch]
2023-07-07 Added option 3 for the power supply
    [qca7000.kicad_sch]
2023-07-08 Fix: Bias resistor corrected. Docu: first run.
    [qca7000.kicad_sch]
2023-07-10 added power supply and STM32, removed first option stepdown, added CP logic, corrected stepdown converter
    [controller.kicad_sch, powersupply.kicad_sch, qca7000.kicad_sch]
2023-07-10 added sheets for inputs and outputs. layout draft.
    [Inputs.kicad_sch, controller.kicad_sch, outputdrivers.kicad_sch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]
2023-07-11 layout for stm, supply, drivers, flash programming connector
    [Inputs.kicad_sch, controller.kicad_sch, outputdrivers.kicad_sch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]
2023-07-11 fix: can transceiver enable high. fix: uart LED low active. fix: contactor LED low active. fix: LED names in silkscreen.
    [controller.kicad_sch, qca7000.kicad_pcb]
2023-07-12 fix: divider on the stepdown. fix: non-inverted contactor drivers. fix: part number of 8MHz. add: mounting holes and spare grid. add: LIM HVDC input. docu: todo list
    [Inputs.kicad_sch, controller.kicad_sch, outputdrivers.kicad_sch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]
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2023-07-13 docu: interface draft. prod: gerber 2023-07-12
    [qca7000.kicad_pcb]
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2023-08-10 added TE DEUTSCH connector and housing
    [DTM1312PA12PBR008.step, EEC-325X4B.step, Inputs.kicad_sch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]
2023-08-10 added RGB LED highside drivers
    [connectors.kicad_sch, controller.kicad_sch, outputdrivers.kicad_sch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]
2023-08-11 first draft with the DRV8874 hbridge driver. Added 3D models.
    [DRV8874QPWPRQ1.stp, connectors.kicad_sch, outputdrivers.kicad_sch]
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2023-08-15 wired the drv8874. Added spare holes. Flash connector larger holes
    [connectors.kicad_sch, controller.kicad_sch, outputdrivers.kicad_sch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]
2023-08-16 changed to 4 layers. Added button, PP and lock feedback. New testpoints to avoid courtyard warnings.
    [Inputs.kicad_sch, connectors.kicad_sch, controller.kicad_sch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]
2023-08-16 routed driver outputs for contactors and lock motor to PWM TIM3 ports. Use protected 12V for DRV.
    [controller.kicad_sch, outputdrivers.kicad_sch, powersupply.kicad_sch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]
2023-08-16 all 100nF now 0805. Todo list cleaned up.
    [Inputs.kicad_sch, controller.kicad_sch, outputdrivers.kicad_sch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]
2023-08-16 added CP sensing. Added 5V on the connector. Created gerber and pdf
    [connectors.kicad_sch, controller.kicad_sch, outputdrivers.kicad_sch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]
2023-08-22 added some jlcpcb part numbers, adjusted some footprints and values accordingly.
    [Inputs.kicad_sch, controller.kicad_sch, outputdrivers.kicad_sch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]
2023-08-22 added more part numbers
    [controller.kicad_sch, outputdrivers.kicad_sch, powersupply.kicad_sch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]
2023-08-24 more partnumbers assigned. split difficult values into two parts. add protection of CP_SENSE port
    [Inputs.kicad_sch, controller.kicad_sch, outputdrivers.kicad_sch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]
2023-08-24 footprint corrections. some layout adaptions for new footprints (ongoing)
    [controller.kicad_sch, outputdrivers.kicad_sch, powersupply.kicad_sch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]
2023-08-25 layout: all components to front (WIP)
    [qca7000.kicad_pcb]
2023-08-26 layouted all the 0805 and botton-to-top changes. Pin description on bottom silk screen.
    [qca7000.kicad_pcb]
2023-08-26 added alternative 1206 for the 0603 capacitors
    [qca7000.csv, qca7000.kicad_pcb, qca7000.kicad_sch]
2023-08-26 installed FabricationToolkit, used it to create gerber, drill, BOM and placement for JLCPCB
    [bom.csv, designators.csv, positions.csv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]
2023-08-26 added readme with JLCPCB offers
    [qca7000.kicad_pcb]
2023-08-26 pcb: added 3D model of the connector
    [qca7000.kicad_pcb]
2023-08-28 BOM consolidation: XTAL options and back to 8MHz. Replace internal connectors by testpoints. Use T with integrated R for CP switching. Fix: Footprint Q7-Q9 corrected.
    [bom.csv, controller.kicad_sch, designators.csv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]
2023-08-28 added part number for the big 10uH
    [bom.csv, designators.csv, positions.csv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]
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2023-09-07 added rotation attribute to get the correct footprint rotation at JLCPCB
    [bom.csv, controller.kicad_sch, designators.csv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]
2023-09-10 docu: V4 2023-09-10 finished. Added board history.
    [bom.csv, designators.csv, positions.csv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]
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2023-09-27 docu: added issues of the V3 board
2023-09-30 docu: added cost estimation for the V3/V4
    [calculations.xlsx]
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2023-10-25 layout fix: bigger gap between QCA corner and via, to avoid solder bridge to corner frame metal. Silkscreen improvements.
    [bom.csv, designators.csv, positions.csv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]
2023-12-18 fix rx shortcut. add transformer. correct part number of NCV. Correct footprints of U1 and L11. add mounting holes. stepdown layout improved. added TVS at 12V
    [bom.csv, connectors.kicad_sch, designators.csv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]
2023-12-18 fix: origin of the transformer into the middle. Fix: rotation attributes for jlcpcb
    [bom.csv, designators.csv, positions.csv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]
2023-12-18 stepdown L and layout further optimized. fix rotation and layout
    [bom.csv, designators.csv, positions.csv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]
2023-12-18 fix: for the big elcap, use jlc part C3445244 to avoid running into expensive standard service
    [bom.csv, designators.csv, positions.csv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]
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2024-02-06 WIP: PP pull-up and divider. variant detection. ipropi connected to ADC.
    [Inputs.kicad_sch, bom.csv, controller.kicad_sch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]
2024-02-06 v4.2 layout finished. release files and readme
    [bom.csv, designators.csv, positions.csv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]
2024-02-19 feature: Added wakeup logic
    [Inputs.kicad_sch, connectors.kicad_sch, controller.kicad_sch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]
2024-02-19 Corrected pin map for CJ431 Increased variant resistor Added pull-down for Wakeup
    [Inputs.kicad_sch, powersupply.kicad_sch]
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2024-02-19 Corrected DRC errors
    [qca7000.kicad_pcb]
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2024-02-27 Made relay drivers PMOS with gate drivers and free wheeling diode
    [Inputs.kicad_sch, outputdrivers.kicad_sch, qca7000.csv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]
2024-02-28 Using another motor driver IC for contactor control
    [Inputs.kicad_sch, connectors.kicad_sch, controller.kicad_sch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]
2024-03-08 Redesigned wakeup circuit
    [Inputs.kicad_sch, outputdrivers.kicad_sch, powersupply.kicad_sch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]
2024-03-18 Added 1M discharge resistor for CP enable Removed momentary turn-on resitor for PP enable because always charged by uC voltage divider
    [Inputs.kicad_sch, powersupply.kicad_sch, qca7000.kicad_pcb]
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2024-04-04 Made PP standby and button pullup 1k Improved connection of TVS diode
    [Inputs.kicad_sch, powersupply.kicad_sch, qca7000.kicad_pcb]
2024-04-05 Moved JP3 further away from header Added production files Updated pin description photo
    [FOCCI-BOM_JLCSMT.xlsx, qca7000.kicad_pcb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]
2024-05-24 Re-assigned pins to be able to make one loom to the charge port and one to the car
    [FOCCI-BOM_JLCSMT.xlsx, Inputs.kicad_sch, connectors.kicad_sch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]
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2024-05-25 Fix possible collision with enclosure
    [qca7000.kicad_pcb]
2024-06-27 Corrected silkscreen, moved parts away from enclosure rail
    [qca7000.kicad_pcb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]
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2024-07-09 added diode D8, corrected resistors, corrected rotations. V5.1
    [bom.csv, designators.csv, positions.csv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]
2024-10-31 5.2pre: transformerless RF path. TVS. Demo placement for alternative connectors.
    [X1-DFN1006-2_RH_DIO.step, connectors.kicad_sch, outputdrivers.kicad_sch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]
2024-11-27 added alternative 6-pin headers. Added uart3 test points. V5.2pre2
    [bom.csv, connectors.kicad_sch, controller.kicad_sch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]
2024-11-28 layout improvements for #7 sub 2 and sub 4 and partly sub 7
    [qca7000.kicad_pcb]
2024-12-10 some layout fixes for #7
    [bom.csv, designators.csv, positions.csv]
2024-12-11 corrected some rotations for JLC. Version 5.2p7
    [Inputs.kicad_sch, controller.kicad_sch, outputdrivers.kicad_sch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]
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2025-05-27 Changed RF dampening resistors from 100 to 22 Ohms
    [Inputs.kicad_sch, connectors.kicad_sch, controller.kicad_sch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]
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2025-06-04 v5.2p10 intermediate: added JTAG. Layout optimizations. Corrected link of the new 22 ohms.
    [qca7000.kicad_sch]
2026-05-29 mech: foccci tester: increased spare-out for nuts on snapper holder to 9.5mm
